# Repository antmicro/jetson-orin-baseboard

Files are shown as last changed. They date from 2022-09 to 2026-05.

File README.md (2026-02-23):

# Antmicro Baseboard for Jetson Orin

Copyright (c) 2022-2026 [Antmicro](https://www.antmicro.com)




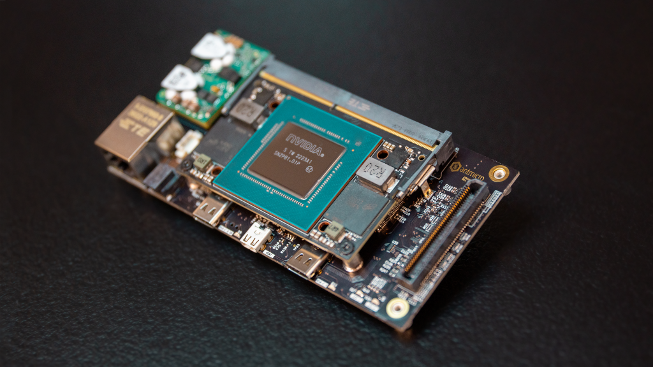
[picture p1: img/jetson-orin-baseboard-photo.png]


## Overview

This project contains open hardware design files for a baseboard supporting [NVIDIA Jetson Orin series](https://www.nvidia.com/en-us/autonomous-machines/embedded-systems/jetson-orin/) of System on Modules (SoMs) including Jetson Orin NX and Jetson Orin Nano.
The board break-routes the typical I/O interfaces from the SoM.
Additionally, it exposes an expansion connector which allows it to be integrated with external processing modules using USB, PCIe or low-speed interfaces.

The design files were prepared in KiCad 9.x.

## Key features

* Two USB PD ports
* DC Power connector
* MIPI CSI-2 interfaces on 50-pin connectors with configurable lane mapping
* Micro HDMI connector
* USB-C 10 Gbps with USB PD and DP
* USB-C 10 Gbps
* USB-C UART with USB PD
* M.2 key M
* M.2 key E
* 1Gb Ethernet with PoE
* Custom expansion connector
* RTC battery backup

## Project structure

The main directory contains KiCad PCB project files, a LICENSE, and a README.
The remaining files are stored in the following directories:

* `img` - contains graphics for this README
* `doc` - contains [documentation and usage instructions](https://antmicro.github.io/jetson-orin-baseboard)

The board exposes MIPI CSI-2 interfaces using unified 50-pin connectors that are electrically compatible with a variety of video accessories created by Antmicro:

* [GMSL Deserializer](https://github.com/antmicro/gmsl-deserializer)
* [SDI-MIPI Video converter](https://github.com/antmicro/sdi-mipi-video-converter)
* [HDMI-MIPI bridge](https://github.com/antmicro/hdmi-mipi-bridge)
* [CVBS-MIPI bridge](https://github.com/antmicro/cvbs-mipi-bridge)
* [OV5640 Dual camera board](https://github.com/antmicro/ov5640-dual-camera-board)
* [OV9281 Dual camera board](https://github.com/antmicro/ov9281-camera-board)
* [Storage Expansion board](https://github.com/antmicro/job-storage-expansion)
* [FRAMOS camera adapter](https://github.com/antmicro/framos-csi-adapter)
* [Allied Vision Alvium Camera Adapter](https://github.com/antmicro/alvium-flexible-csi-adapter)

## Licensing

This project is published under the [Apache-2.0](LICENSE) license.

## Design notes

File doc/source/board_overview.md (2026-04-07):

# Board overview

Jetson Orin Baseboard is an open hardware board design supporting NVIDIA Jetson Orin NX and Orin Nano family of SoMs.
The board design files were created in KiCad 8.x.
The board is a versatile development kit which can be easily adopted in order to make it usable in commercial applications for autonomous vehicles, industry, agriculture, medicine or space.
You can find out more about the Jetson Orin Baseboard in this [blog article](https://antmicro.com/blog/2023/05/jetson-orin-baseboard-1-1-with-orin-nano/), or by visiting Antmicro's portals listed below:

* [Open Hardware Portal](https://openhardware.antmicro.com/boards/jetson-orin-baseboard/)
* [System Designer](https://designer.antmicro.com/library/devices/jetson-orin-baseboard)
* [Open Source Portal](https://opensource.antmicro.com/projects/jetson-orin-baseboard/)

They provide 3D renders and the board stackup definition, as well as an interactive preview of the board schematic.

You can also browse board-specific assets in the GitHub [releases](https://github.com/antmicro/jetson-orin-baseboard/releases) section.
The assets provided here include PDF schematics and mechanical (STEP) models of the board assemblies in certain revisions.

## IO map

A map of on-board connectors, status LEDs, control buttons and I/O interfaces is provided below.

:::{figure-md}
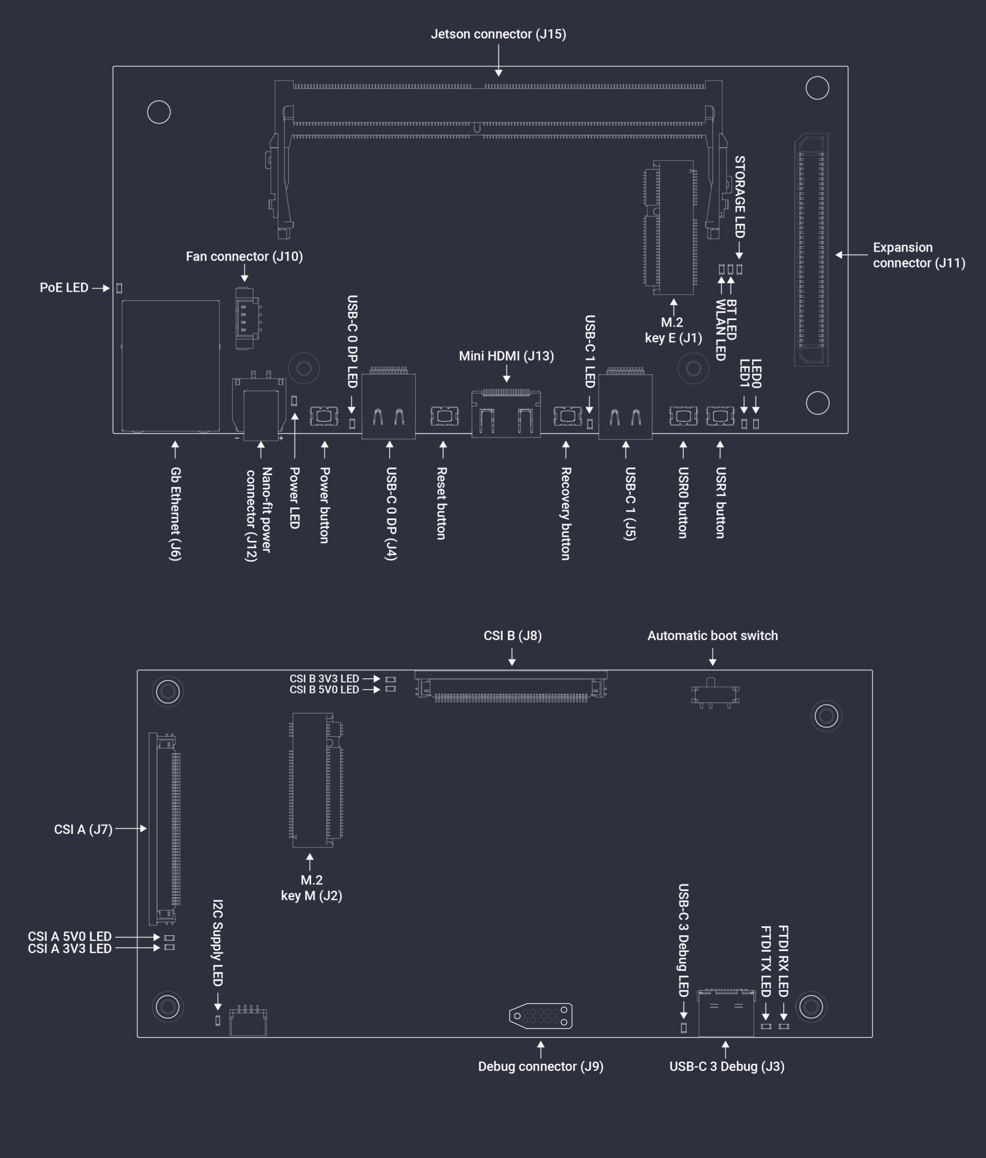
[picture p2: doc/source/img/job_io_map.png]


Jetson Orin Baseboard interface map
:::

## Power

The board can be powered with the following sources:

### 1. DC Connector

Jetson Orin Baseboard can be powered with a stable DC voltage via the on-board locking DC connector ([`J12`](#J12)) with Molex Nano-Fit plug (see the [Power Supply](getting_started.md#power-supply) section for details related to Nano-Fit power harness assembly).
You can use an external DC adapter for powering the board or a battery pack with rechargeable or non-rechargeable batteries, as long as the provided voltage fits within the accepted range (9-20VDC for board revision >= 1.3.0 and up to 15 V on rev. <= 1.1.7).
In board revision >= 1.3.0, the power supply voltage provided to the SoM is switched between `VCC_IN` power rail and 5V power rail provided by the on-board step down DC-DC converter depending on the `MODULE_ID` pin status.
This enables the use of the Jetson Orin NX in "super" mode which requires a minimum power supply voltage of 8V.
If you plan to power the Jetson Orin Baseboard from a battery pack, please note that battery (re-) charging is currently not supported in the design. 
Adjusting the power supply scenario for specific battery types and charging strategy can be implemented via a custom modification of the baseboard PCB design. 

### 2. Power over Ethernet

Jetson Orin Baseboard supports PoE++ Type 1-4 (IEEE 802.3bt) and negotiates Power Delivery (PD) with a maximum power budget of 60W.
The board includes an isolated PoE DC/DC converter.
You can power the board via the Gigabit Ethernet port ([`J6`](#J6)) using a PoE injector or a PoE-capable Ethernet switch.

### 3. USB-C Power Delivery
* USB Power Delivery PD is available on two USB-C ports:
    * USB-C0 ([`J4`](#J4)) general purpose USB port
    * USB-C3 ([`J3`](#J3)) debug console interface port (disabled in the [shared](https://github.com/antmicro/antmicro-jetson-orin-baseboard-tps65988-config) controller configuration)

Those ports are maintained by the on-board USB-C Power Delivery controller (Texas Instruments/[TPS65988](https://www.ti.com/product/TPS65988/part-details/TPS65988DHRSHR)).
This controller needs to be configured in order to make it implement one of the desired power source/sink negotiation scenarios.

:::{note}
The recommended power supply voltage negotiated with the USB-C PD controller for power sink mode is 20VDC (15VDC for board revisions <= 1.3.0).
If you plan to power up the Jetson Orin Baseboard through the USB PD source, make sure it meets [power requirements](getting_started.md#2-power-supply) for stable operation.
:::

## USB-C Power Delivery controller configuration

The on-board USB-C Power Delivery controller (Texas Instruments/[TPS65988](https://www.ti.com/product/TPS65988/part-details/TPS65988DHRSHR)) can be configured for a specific power profile by writing a binary configuration file to an SPI flash.
You can generate your own configuration file with the [TPS6598X-CONFIG](https://www.ti.com/tool/TPS6598X-CONFIG) utility provided by Texas Instruments.
Please refer to the Jetson Orin Baseboard [schematics](https://github.com/antmicro/jetson-orin-baseboard/blob/main/doc/jetson-orin-baseboard-schematic.pdf) to identify the USB port and power supply rail associated with it to generate a valid power profile setting while using the `TPS6598X-CONFIG` tool.
Also please refer to the [TPS65987DDH and TPS65988DH Host Interface Technical Reference Manual](https://www.ti.com/lit/ug/slvubh2b/slvubh2b.pdf) for further details.

There are several ways to write the USB-C PD configuration to the on-board controller:
* Via an external SPI Flash programmer connected to the [`J9`](#J9)
* Via the [antmicro-jetson-orin-baseboard-tps65988-config](https://github.com/antmicro/antmicro-jetson-orin-baseboard-tps65988-config) tool
  * From the Jetson Orin SoM BSP (user space)
  * From the host (PC) via the USB-C ([`J3`](#J3)) debug console interface port (in baseboard revisions >= 1.1.9)

If you happen to have some of the most recent baseboard revision (>= 1.1.9), the easiest method to use is [flashing from the debug console interface port](#tps65988-config-tool-via-the-debug-console-interface-port).

### External SPI Flash programmer
#### 1. Collect the hardware

You will need the following pieces of hardware to proceed with writing the USB-C PD configuration file to the SPI Flash:

* A computer running Linux (the following procedure has been tested with Ubuntu 23 and Debian 11 distributions)
* USB dongle based on FTDI/(FT4232H-56Q) [FTDI4232](https://ftdichip.com/products/ft4232hq/).
  We suggest using Antmicro's open hardware [Debug Toolkit](https://github.com/antmicro/ftdi-toolkit) to simplify the setup (the cable mentioned below connects its J2 straight with Jetson Orin Baseboard's J9)
* 10 Pin Tag-Connect [TC2050-IDC-NL](https://www.tag-connect.com/product/tc2050-idc-nl-10-pin-no-legs-cable-with-ribbon-connector) cable
  This cable should be connected to the signals from FTDI FT4232 according to the following table:

| Tag-Connect TC2050-IDC-NL-050 [(pinout)](https://www.tag-connect.com/wp-content/uploads/bsk-pdf-manager/TC2050-IDC-NL_Datasheet_8.pdf) | FTDI 4232 [(pinout)](https://ftdichip.com/wp-content/uploads/2024/05/DS_FT4232H.pdf) |
|---|---|
| 1 | 3V3 |
| 2 | ADBUS3 (TMS/CS) |
| 3 | GND |
| 4 | ADBUS0 (TCK/SCLK) |
| 5 | GND |
| 6 | ADBUS2(TDO/MISO) |
| 7 | NC |
| 8 | ADBUS1 (TDI/MOSI) |
| 9 | GND |
| 10 | NC |

#### 2. Prepare the FT4232 dongle

  *  Set the [Debug Toolkit](https://github.com/antmicro/ftdi-toolkit) Channel A to 3.3V logic with a jumper.
  *  Enable JTAG VCC with a jumper.
  *  Select `SPI/SWD` interface mode for channel A with a jumper.
  *  Connect the 10 Pin Tag-Connect cable to the Debug Toolkit assuming the connection mapping specified in the table above (for Antmicro Debug Toolkit - connect to J2 connector).

:::{figure-md}
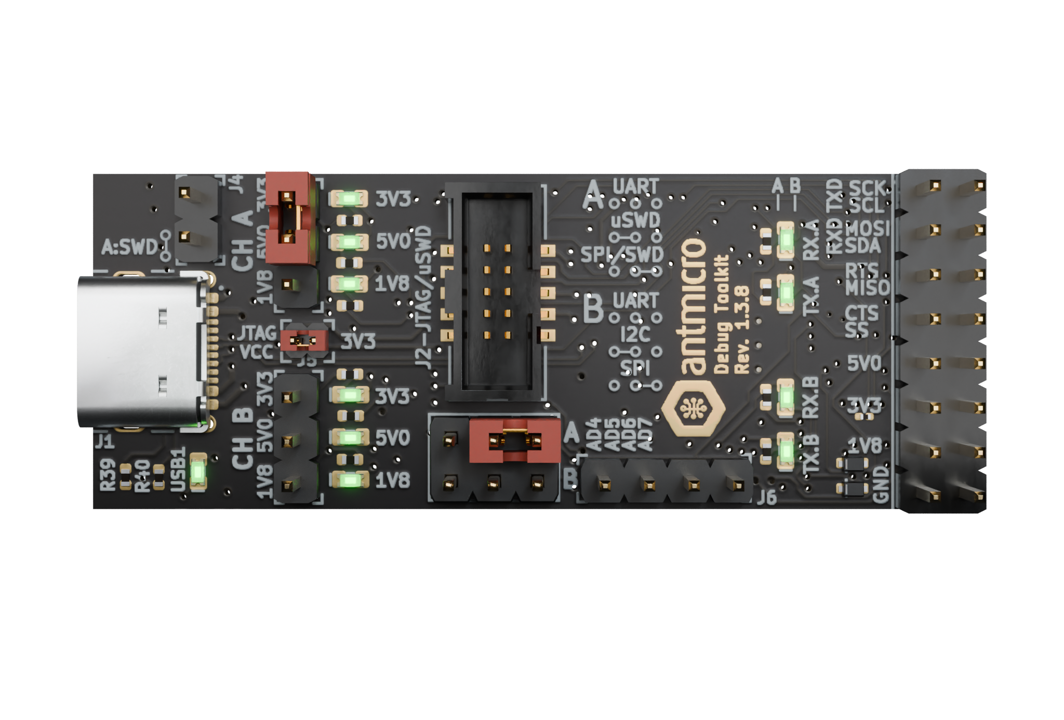
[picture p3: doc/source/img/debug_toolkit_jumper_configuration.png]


Debug Toolkit Jumper configuration for writing the USB-C PD configuration file.
:::

#### 3. Prepare the PC for flashing

  * Install the [flashrom](https://github.com/flashrom/flashrom) utility on your host PC.
    On Debian-based distributions you can use a package manager for that.
```
sudo apt install flashrom
```
  * Adjust the size of the TPS6598 binary configuration file (we named it `config.bin`) to match the SPI flash size:
```
truncate -s 1048576 config.bin
```

#### 4. Write the configuration

  * Connect [Tag-Connect Plug-of-Nails](https://www.tag-connect.com/product/tc2050-idc-nl-050) to the [`J9`](#J9) connector on the Jetson Orin Baseboard.
   Hold the plug in place firmly during the flashing process.
   The SPI flash will be powered via the programming cable during the flashing process - you do not have to provide your Jetson Orin Baseboard with power.

:::{figure-md}
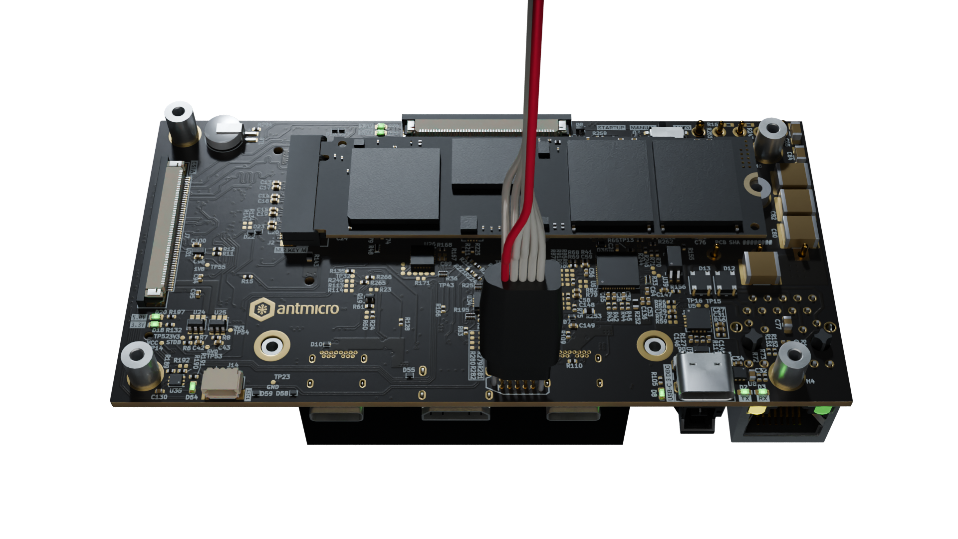
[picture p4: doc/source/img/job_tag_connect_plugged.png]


Jetson Orin Baseboard with Tag-Connect plugged for PD controller flashing.
:::

 * Check if SPI Flash can be detected via Debug Toolkit:
```
flashrom -p ft2232_spi:type=4232H,port=A,divisor=64 | grep "W25Q80.V"
```
Expected outcome:
```
Found Winbond flash chip "W25Q80.V" (1024 kB, SPI) on ft2232_spi.
```

 * Write the configuration file to the SPI Flash:
```
flashrom -p ft2232_spi:type=4232H,port=A,divisor=64 -w config.bin
```
Expected outcome:
```
(...)
Reading old flash chip contents... done.
Erasing and writing flash chip... Erase/write done.
Verifying flash... VERIFIED.
```

 * You can repeat the previous command to ensure that the binary file has been written successfully:

Expected outcome:
```
(...)
Warning: Chip content is identical to the requested image.
Erase/write done.
```

### TPS65988-config tool from Jetson Orin user space

The TPS65988-config flashing script can be found in the [antmicro-jetson-orin-baseboard-tps65988-config](https://github.com/antmicro/antmicro-jetson-orin-baseboard-tps65988-config) repository.

#### 1. Prepare hardware

To properly execute this script, boot the Jetson Orin Baseboard, and connect to it via the [debug console](getting_started.md#connect-the-debug-console) or via SSH. 
Since the PD controller is not yet configured at this point, the baseboard has to be powered from either the [`J12`](#J12) or via PoE connected to the [`J6`](#J6).
Internet connection is also suggested.

#### 2. Install dependencies
Log into Jetson Orin module.
Clone the [antmicro-jetson-orin-baseboard-tps65988](https://github.com/antmicro/antmicro-jetson-orin-baseboard-tps65988-config) repository and install the `smbus2` package using `pip`

```
git clone https://github.com/antmicro/antmicro-jetson-orin-baseboard-tps65988-config.git
pip3 install smbus2
cd antmicro-jetson-orin-baseboard-tps65988-config
```

#### 3. Flash the config
Run:

```
python3 TPS65988_flash.py --erase --write JOBrev1_1_6.bin
```

Expected outcome:
```
(...)
Writing 42KB to flash memory...
Write completed 43968 bytes written
The PD Controller has been flashed successfully
Performing cold reset
```

### TPS65988-config tool via the debug console interface port
This option allows for flashing the USB-C Power Delivery controller without SoM or external power.

#### 1. Prepare hardware
* Disconnect power supply from the baseboard
* Remove Jetson module from the baseboard
* Connect a host PC to Jetson Orin Baseboard USB-C Debug Connector ([`J3`](#J3))

#### 2. Install dependencies

On the host PC:

Clone the [antmicro-jetson-orin-baseboard-tps65988-config](https://github.com/antmicro/antmicro-jetson-orin-baseboard-tps65988-config) repository and install the `smbus2` package with `pip`

```
git clone https://github.com/antmicro/antmicro-jetson-orin-baseboard-tps65988-config.git
pip3 install smbus2
cd antmicro-jetson-orin-baseboard-tps65988-config
```

#### 3. Write the configuration
```
python3 TPS65988_flash.py --erase --write ./JOBrev1_1_6.bin --ft230x
```
During the flashing process the [`D3`](#D3) LED should light up.

Expected outcome:
```
(...)
Writing 42KB to flash memory...
Write completed 43968 bytes written
The PD Controller has been flashed successfully
Performing cold reset
Reverting FT230X to UART configuration
```
The [`D3`](#D3) RX LED should turn off indicating end of communication.

## Mechanics

The Jetson Orin Baseboard PCB is 120x60 millimeters (WxL) which translates into 4.72x2.36 inch.
The overall height of the set depends on the cooling module attached.
The base setup with a default cooling module is 37 mm or 1.45 inch tall.
The KiCad PCB design files include mechanical layers with dimensions specified for the fastening holes and notable components.
The board with the Jetson Module, M.2 storage and cooling module weighs 164g (5.78oz).
The mechanical STEP models of the Jetson Orin Baseboard in notable revisions are provided in the [releases](https://github.com/antmicro/jetson-orin-baseboard/releases/) sections available on GitHub.

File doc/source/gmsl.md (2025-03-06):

# GMSL
This manual will guide you through the setup of the open hardware GMSL Deserializer and Serializer boards together with Jetson Orin Baseboard.
It describes the basic steps required to run a simple demo that captures feed from the connected OV5640 sensor.

## Collect the hardware
You'll need the following hardware:
* [NVIDIA Jetson Orin Nano SoM](https://www.nvidia.com/en-us/autonomous-machines/embedded-systems/jetson-orin/)
* [Antmicro Jetson Orin Baseboard](https://github.com/antmicro/jetson-nano-baseboard)
* [Antmicro OV5640 dual camera board](https://github.com/antmicro/ov5640-dual-camera-board)
* [Antmicro GMSL Serializer](https://github.com/antmicro/gmsl-serializer) x 2
* [Antmicro GMSL Deserializer](https://github.com/antmicro/gmsl-deserializer)
* [Antmicro Dual Camera to GMSL Serializer CSI Adapter](https://github.com/antmicro/dual-gmsl-serializer-adapter) (optional, for two camera setup)
* NVMe drive
* Power supplies (for GMSL Deserializer it can be the same as for the Jetson Orin Baseboard)

## Build your setup

### Prerequisites
First follow the steps in [Getting Started](./getting_started.md) to have a running Jetson Orin Baseboard ready.

### Steps
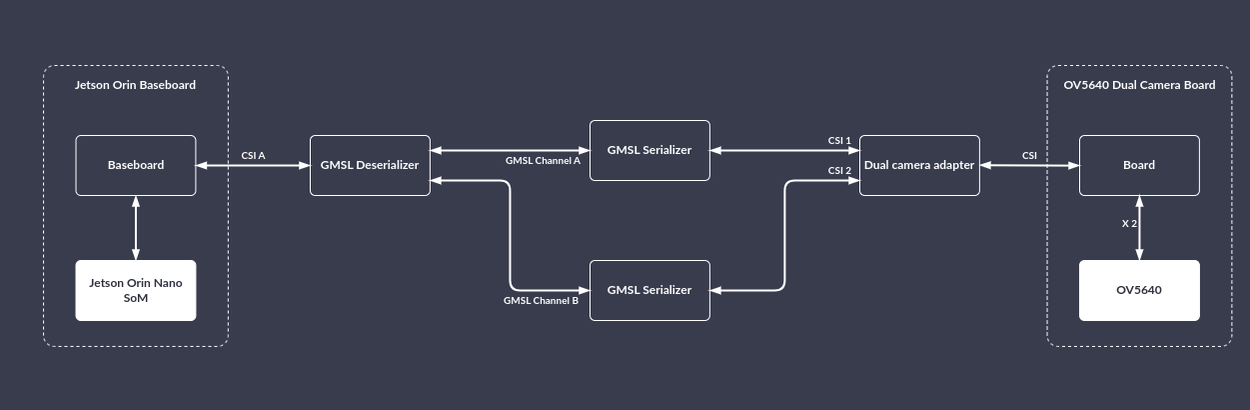
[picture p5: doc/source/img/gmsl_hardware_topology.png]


To prepare the Jetson Orin Baseboard for GMSL usage, connect the hardware like in the diagram above, that is:
1. Connect GMSL Deserializer to Jetson Orin Baseboard on CSI A
2. Connect GMSL Serializer #1 to GMSL Deserializer on Channel A
3. Connect GMSL Serializer #2 to GMSL Deserializer on Channel B
4. Connect GMSL Serializer #1 to the dual camera adapter
5. Connect GMSL Serializer #2 to the dual camera adapter
6. Connect OV5640 Dual Camera Board to the dual camera adapter
7. Plug in the power supply to the GMSL Deserializer
8. Power on the Jetson Orin Baseboard

This is how the setup should look after everything has been connected:
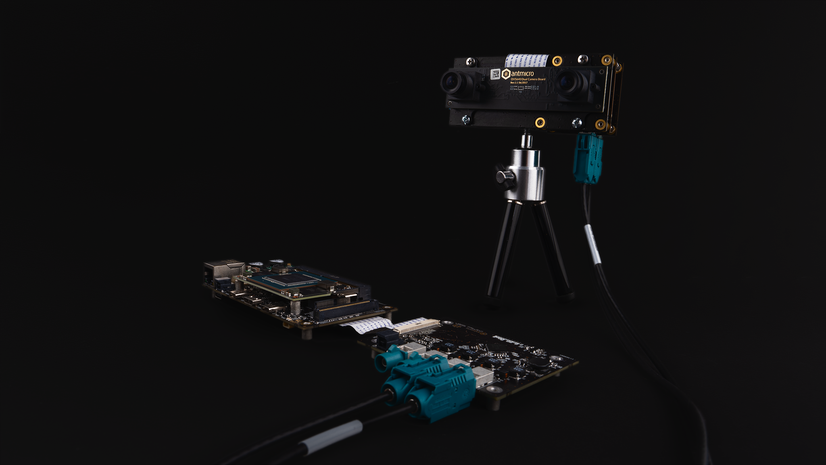
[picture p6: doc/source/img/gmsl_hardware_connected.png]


## Flash the BSP image
Flash the image using [this BSP](https://github.com/antmicro/meta-antmicro/tree/master/system-releases/nvidia-jetson-orin-baseboard-demo). First, pull the code:
```
mkdir gmsl-demo && cd gmsl-demo
$ repo init -u https://github.com/antmicro/meta-antmicro.git -m system-releases/nvidia-jetson-orin-baseboard-demo/manifest.xml
$ repo sync -j`nproc`
```
Build the BSP:
```
$ source sources/poky/oe-init-build-env
$ export BB_ENV_PASSTHROUGH_ADDITIONS="$BB_ENV_PASSTHROUGH_ADDITIONS KERNEL_DEVICETREE"
$ PARALLEL_MAKE="-j $(nproc)" BB_NUMBER_THREADS="$(nproc)" MACHINE="p3509-a02-p3767-0000" KERNEL_DEVICETREE="tegra234-p3767-0003-antmicro-job-gmsl-ov5640.dtb" bitbake nvidia-jetson-orin-baseboard-demo
```
After the BSP has been built, connect the NVMe storage to the device and put the device into recovery mode:
* Connect the Recovery USB-C port to the host PC
* Press the POWER button (if the device isn't powered yet)
* Press and hold the RECOV button
* Press the RESET button
* Release the RESET and RECOV buttons
* Check if the following USB device is present on your host PC:
```
$ lsusb
...
ID 0955:7323 NVIDIA Corp. APX
...
```
Unpack the `tegraflash` package:
```
cd tmp/deploy/images/p3509-a02-p3767-0000
mkdir flash-directory && cd flash-directory
tar xzvf ../nvidia-jetson-orin-baseboard-demo-p3509-a02-p3767-0000.tegraflash.tar.gz
```
Flash it:
```
sudo ./initrd-flash
```

Run the following command on the device to verify that the GMSL hardware was detected:
```
$ media-ctl -p
```
It's output should reflect the GMSL devices' topology:
```
...
- entity 1: nvcsi0 (2 pads, 2 links)
            type V4L2 subdev subtype Unknown flags 0
            device node name /dev/v4l-subdev0
	pad0: Sink
		<- "des_ch_0":0 [ENABLED]
	pad1: Source
		-> "vi-output, ov5640 21-003c":0 [ENABLED]

- entity 4: nvcsi1 (2 pads, 2 links)
            type V4L2 subdev subtype Unknown flags 0
            device node name /dev/v4l-subdev1
	pad0: Sink
		<- "des_ch_1":0 [ENABLED]
	pad1: Source
		-> "vi-output, ov5640 23-003c":0 [ENABLED]

- entity 7: ser_0_ch_0 (2 pads, 2 links)
            type V4L2 subdev subtype Unknown flags 0
            device node name /dev/v4l-subdev2
	pad0: Source
		[fmt:FIXED/0x0]
		-> "des_ch_0":1 [ENABLED]
	pad1: Sink
		[fmt:YUYV8_1X16/0x0]
		<- "ov5640 21-003c":0 [ENABLED]

- entity 10: ser_1_ch_0 (2 pads, 2 links)
             type V4L2 subdev subtype Unknown flags 0
             device node name /dev/v4l-subdev3
	pad0: Source
		[fmt:FIXED/0x0]
		-> "des_ch_1":1 [ENABLED]
	pad1: Sink
		[fmt:YUYV8_1X16/0x0]
		<- "ov5640 23-003c":0 [ENABLED]

- entity 13: des_ch_0 (2 pads, 2 links)
             type V4L2 subdev subtype Unknown flags 0
             device node name /dev/v4l-subdev4
	pad0: Source
		[fmt:YUYV8_1X16/0x0]
		-> "nvcsi0":0 [ENABLED]
	pad1: Sink
		[fmt:FIXED/0x0]
		<- "ser_0_ch_0":0 [ENABLED]

- entity 16: des_ch_1 (2 pads, 2 links)
             type V4L2 subdev subtype Unknown flags 0
             device node name /dev/v4l-subdev5
	pad0: Source
		[fmt:YUYV8_1X16/0x0]
		-> "nvcsi1":0 [ENABLED]
	pad1: Sink
		[fmt:FIXED/0x0]
		<- "ser_1_ch_0":0 [ENABLED]

- entity 19: ov5640 21-003c (1 pad, 1 link)
             type V4L2 subdev subtype Sensor flags 0
             device node name /dev/v4l-subdev6
	pad0: Source
		[fmt:UYVY8_1X16/1920x1080 field:none colorspace:srgb]
		-> "ser_0_ch_0":1 [ENABLED]

- entity 21: vi-output, ov5640 21-003c (1 pad, 1 link)
             type Node subtype V4L flags 0
             device node name /dev/video0
	pad0: Sink
		<- "nvcsi0":1 [ENABLED]

- entity 47: ov5640 23-003c (1 pad, 1 link)
             type V4L2 subdev subtype Sensor flags 0
             device node name /dev/v4l-subdev7
	pad0: Source
		[fmt:UYVY8_1X16/1920x1080 field:none colorspace:srgb]
		-> "ser_1_ch_0":1 [ENABLED]

- entity 49: vi-output, ov5640 23-003c (1 pad, 1 link)
             type Node subtype V4L flags 0
             device node name /dev/video1
	pad0: Sink
		<- "nvcsi1":1 [ENABLED]
```

## Capturing streams
### Setting up formats
Deserializer and serializer need to be informed what packet types to forward, otherwise all packets will be filtered:
```
# first stream
media-ctl -d /dev/media0 --set-v4l2 '"ser_0_ch_0":1[fmt:YUYV8_1X16/1920x1080]'
media-ctl -d /dev/media0 --set-v4l2 '"des_ch_0":0[fmt:YUYV8_1X16/1920x1080]'
# second stream
media-ctl -d /dev/media0 --set-v4l2 '"ser_1_ch_0":1[fmt:YUYV8_1X16/1920x1080]'
media-ctl -d /dev/media0 --set-v4l2 '"des_ch_1":0[fmt:YUYV8_1X16/1920x1080]'
```
### Capturing frames
To capture a given number of frames from the camera just run:
```
v4l2-ctl -d<camera_number> --stream-mmap --stream-count=<number_of_frames> --stream-to=cam0_image.raw
```
Or use GStreamer:
```
gst-launch-1.0 v4l2src device=<camera_device> num-buffers=<number_of_frames> ! filesink location=cam0_image.raw
```
For OV5640 number of frames should be > 3, since OV5640 needs a few frames to roll out before the stream stabilizes.

### Live video feed
This requires Jetson Orin Baseboard to be connected to some screen via HDMI.
To stream the feed from a camera to an X11 window:
```
gst-launch-1.0 v4l2src device=<camera_device> ! xvimagesink
```

To capture two feeds simultaneously:
```
gst-launch-1.0 \
v4l2src device=/dev/video1 ! \
compositor name=mix sink_0::xpos=0 sink_0::ypos=0 sink_1::xpos=1280 sink_1::ypos=0 ! \
videoconvert ! autovideosink \
v4l2src device=/dev/video0 ! \
mix.
```

### Example images captured with the setup
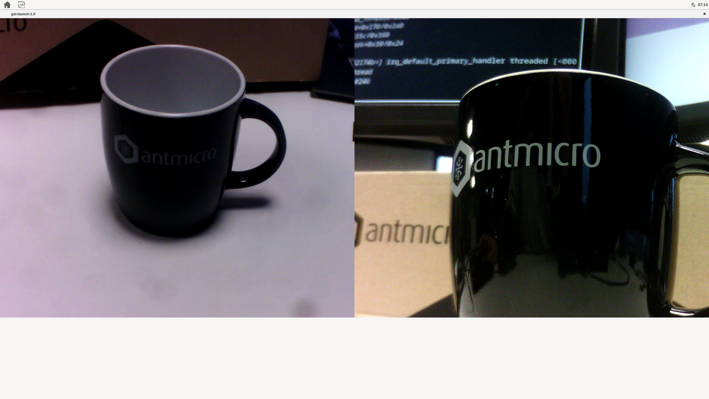
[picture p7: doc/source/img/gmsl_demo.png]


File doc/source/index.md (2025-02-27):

# {{project}}

```{toctree}
:maxdepth: 3

getting_started
board_overview
gmsl
```

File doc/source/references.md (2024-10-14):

# Image references
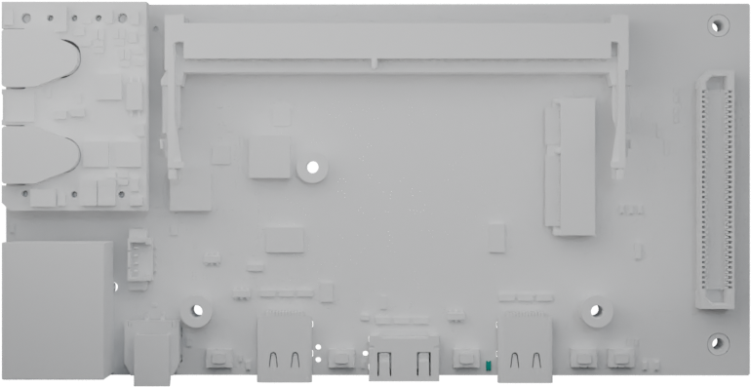
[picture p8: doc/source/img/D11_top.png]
```{image} img/D11_top.png
:name: D11
```

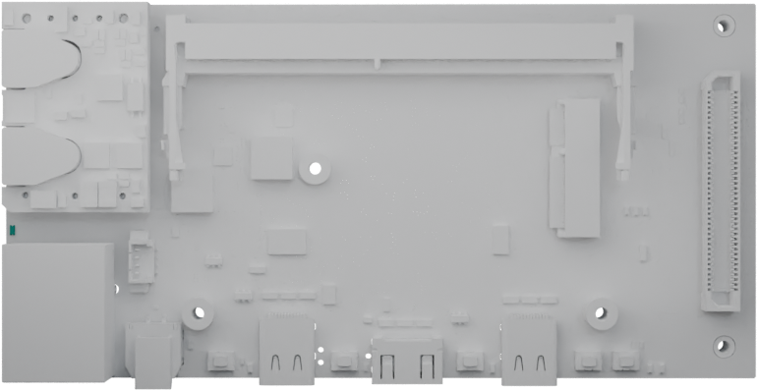
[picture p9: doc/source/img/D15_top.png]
```{image} img/D15_top.png
:name: D15
```

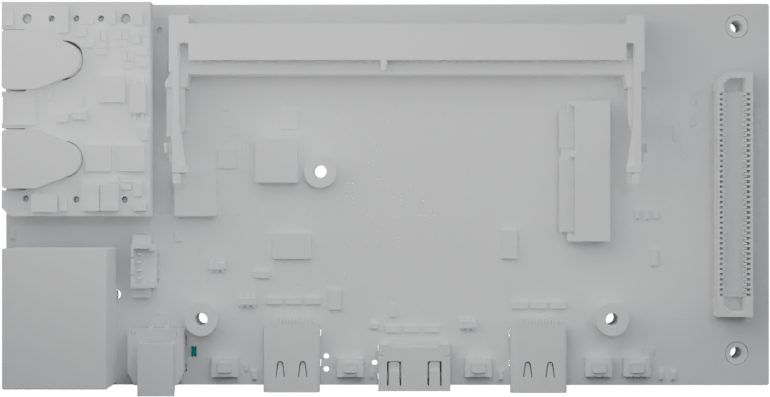
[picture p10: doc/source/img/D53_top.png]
```{image} img/D53_top.png
:name: D53
```

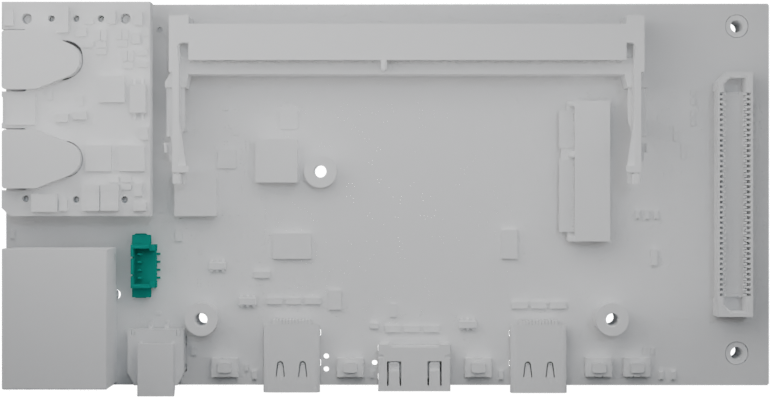
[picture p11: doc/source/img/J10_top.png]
```{image} img/J10_top.png
:name: J10
```

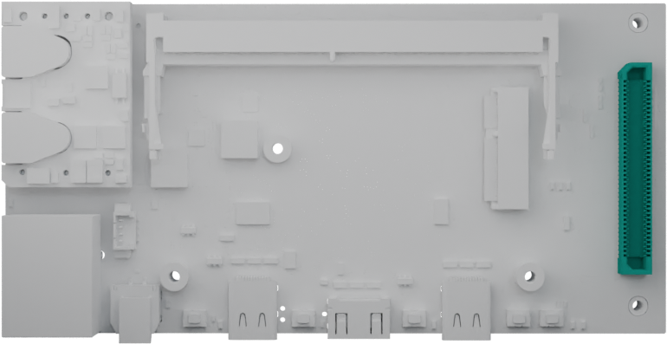
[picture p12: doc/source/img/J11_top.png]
```{image} img/J11_top.png
:name: J11
```

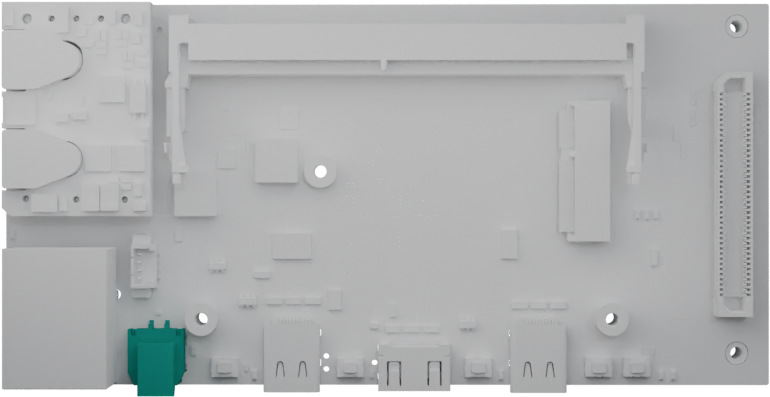
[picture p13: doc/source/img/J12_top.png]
```{image} img/J12_top.png
:name: J12
```

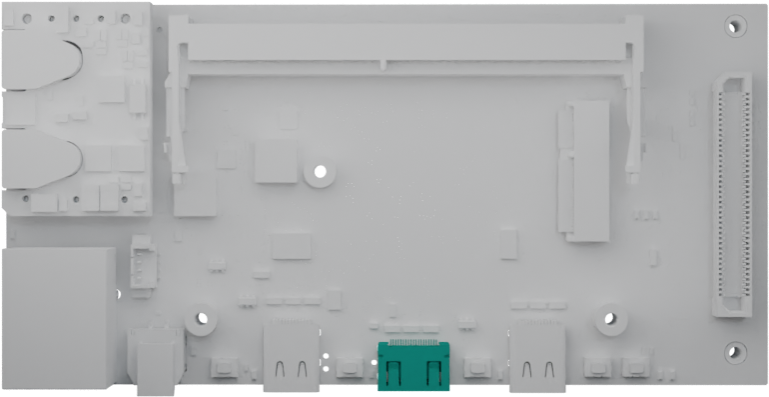
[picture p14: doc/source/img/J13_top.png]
```{image} img/J13_top.png
:name: J13
```

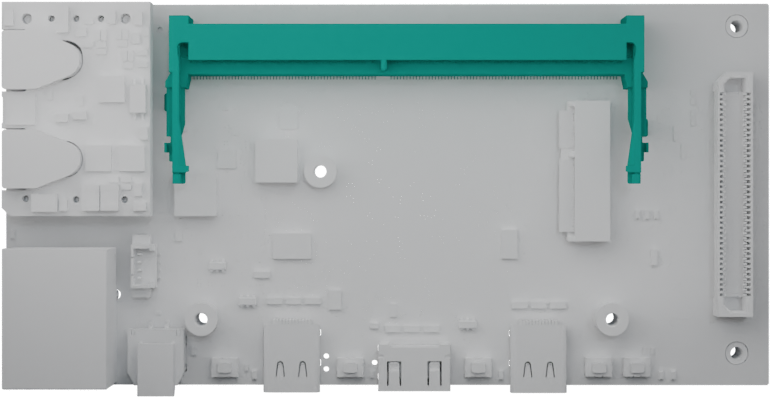
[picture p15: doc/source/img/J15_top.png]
```{image} img/J15_top.png
:name: J15
```

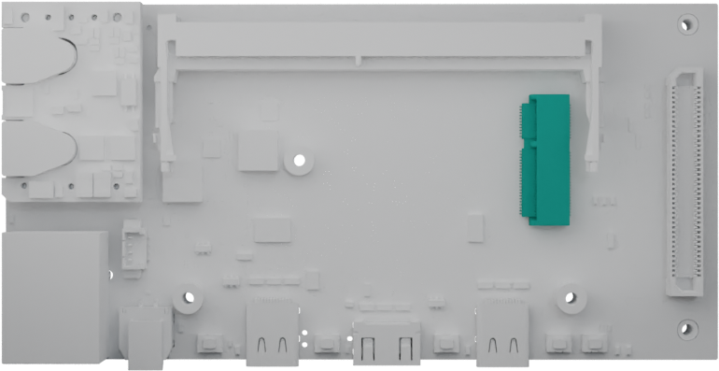
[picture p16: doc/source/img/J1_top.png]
```{image} img/J1_top.png
:name: J1
```

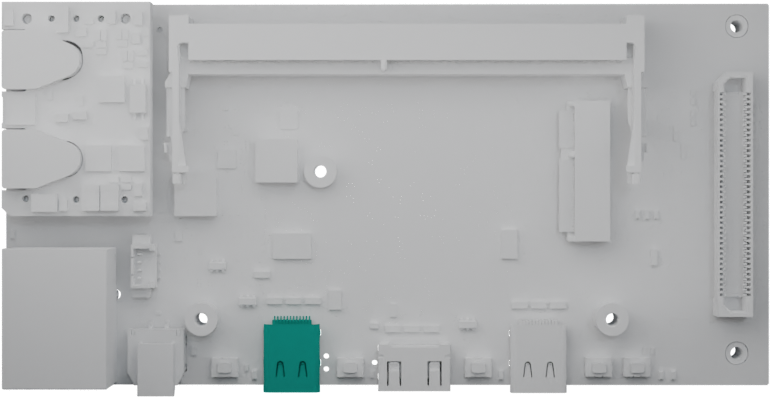
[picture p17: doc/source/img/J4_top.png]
```{image} img/J4_top.png
:name: J4
```

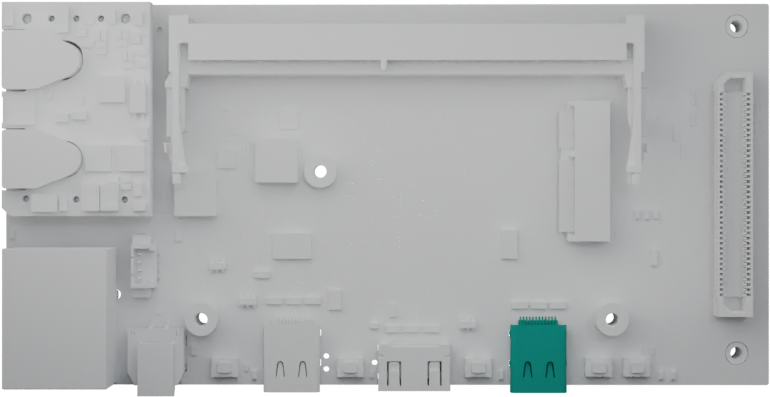
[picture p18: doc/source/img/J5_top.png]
```{image} img/J5_top.png
:name: J5
```

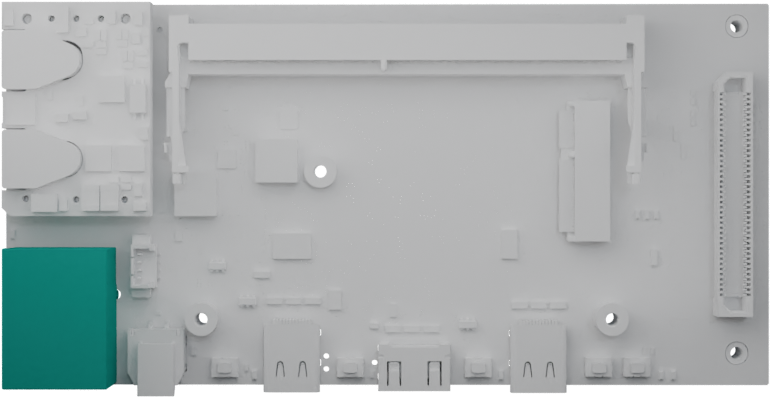
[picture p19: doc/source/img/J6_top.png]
```{image} img/J6_top.png
:name: J6
```

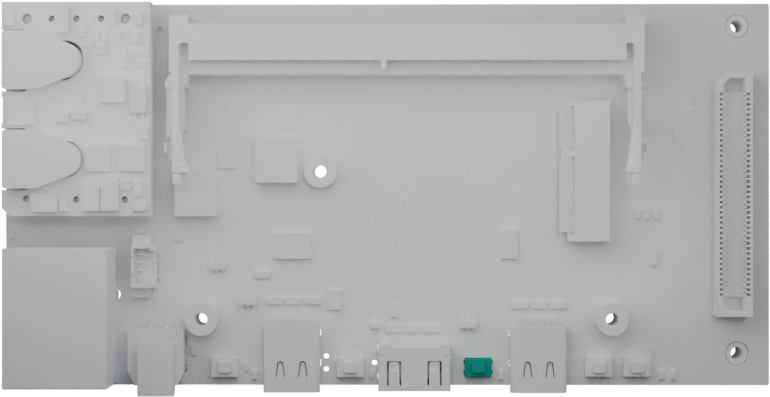
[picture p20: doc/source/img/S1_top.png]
```{image} img/S1_top.png
:name: S1
```

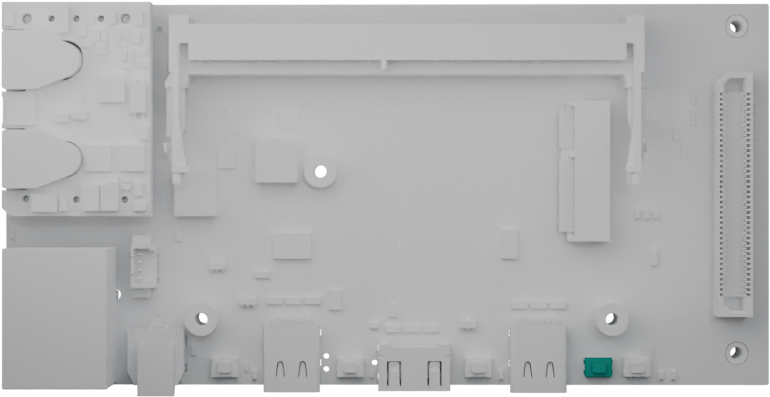
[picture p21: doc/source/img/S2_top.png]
```{image} img/S2_top.png
:name: S2
```

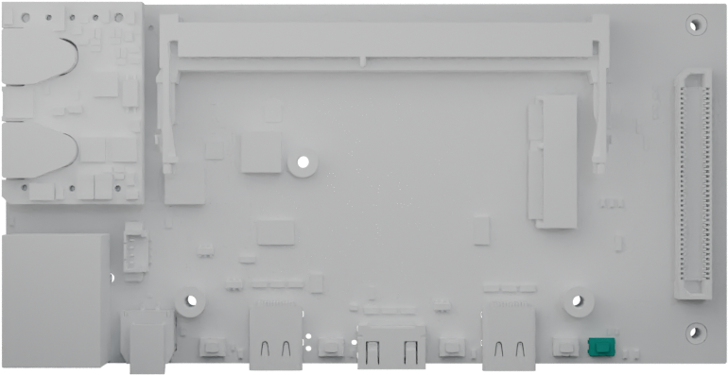
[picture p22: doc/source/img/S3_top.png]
```{image} img/S3_top.png
:name: S3
```

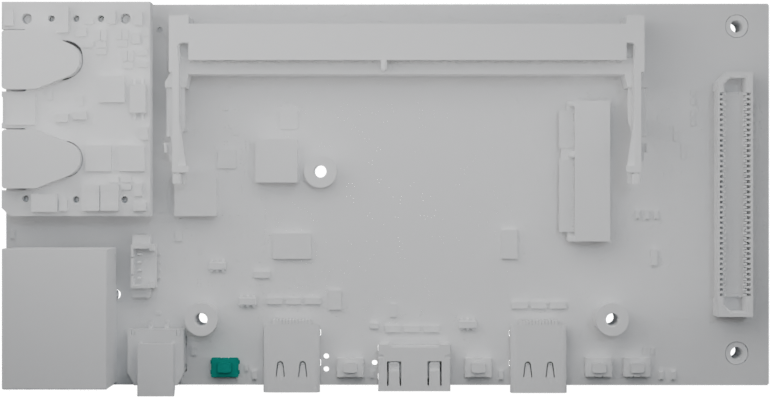
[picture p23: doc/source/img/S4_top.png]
```{image} img/S4_top.png
:name: S4
```

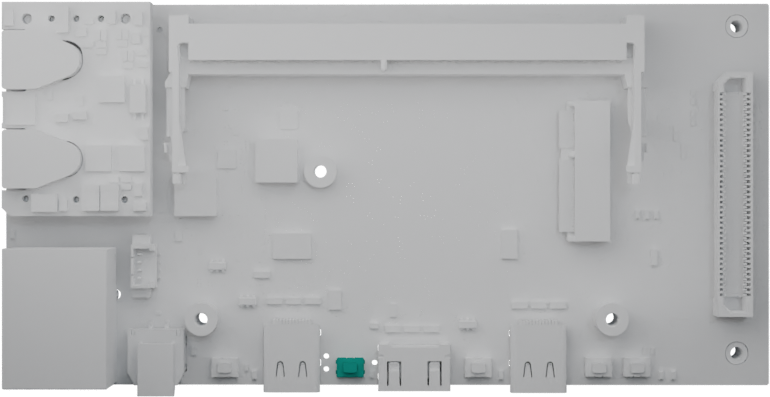
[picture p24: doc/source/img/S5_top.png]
```{image} img/S5_top.png
:name: S5
```

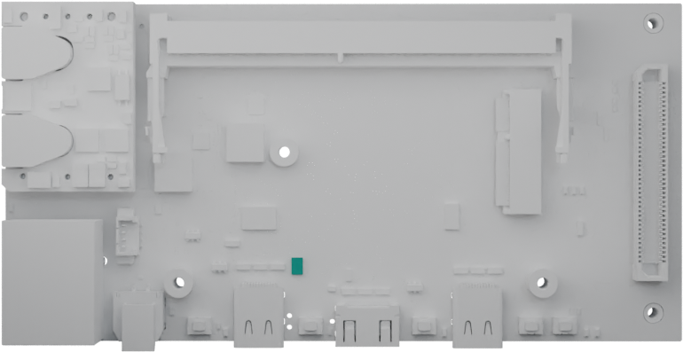
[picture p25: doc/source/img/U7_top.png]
```{image} img/U7_top.png
:name: U7
```

```{image} img/D3_bottom.png
:name: D3
```

```{image} img/J14_bottom.png
:name: J14
```

```{image} img/J2_bottom.png
:name: J2
```

```{image} img/J3_bottom.png
:name: J3
```

```{image} img/J7_bottom.png
:name: J7
```

```{image} img/J8_bottom.png
:name: J8
```
```{image} img/job_tag_connect_plugged_scaled.png
:name: J9
```

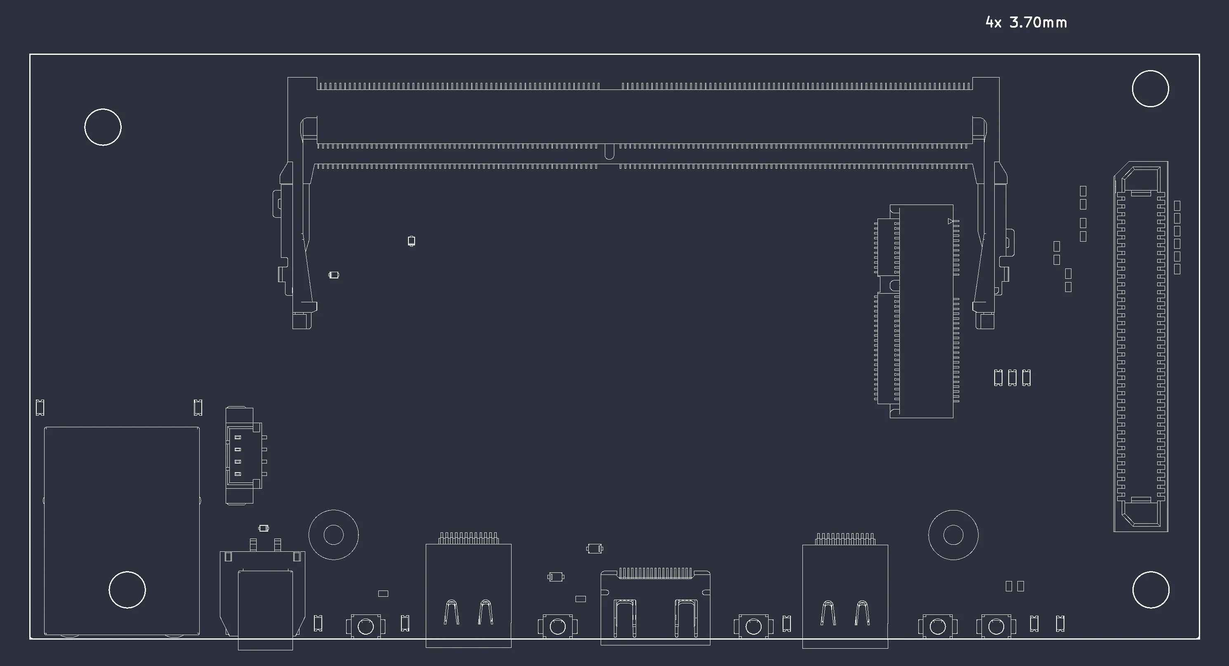
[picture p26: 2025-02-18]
assets/wireframe/wireframe_descriptions_top.webp

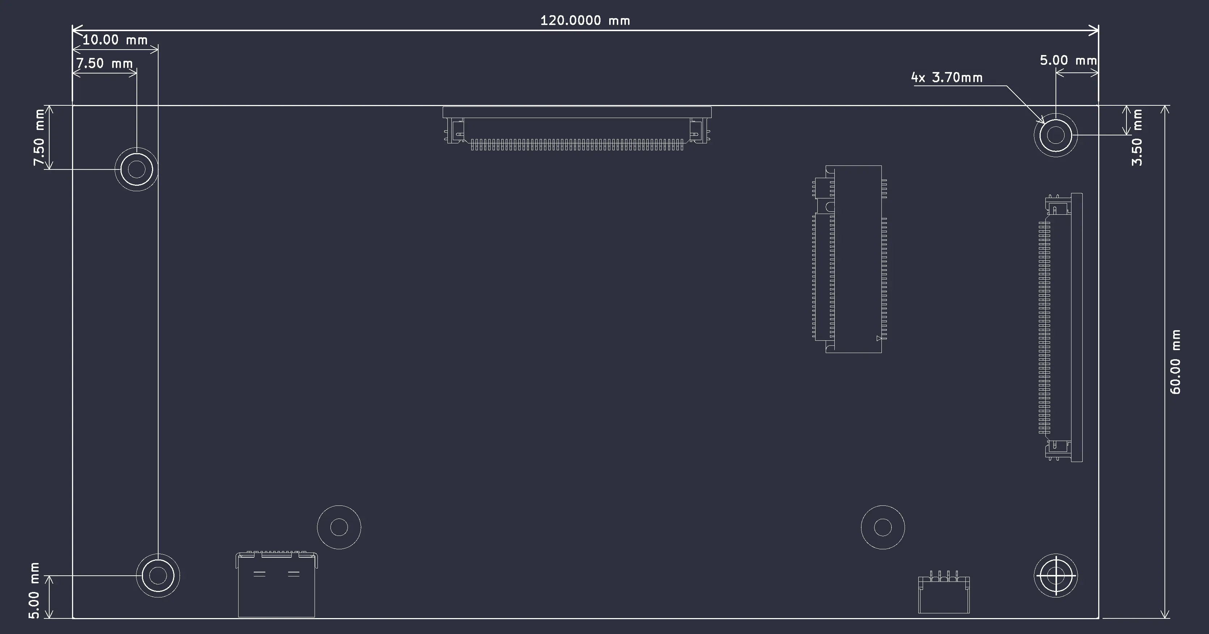
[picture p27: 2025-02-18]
assets/wireframe/wireframe_dimensions_bottom.webp

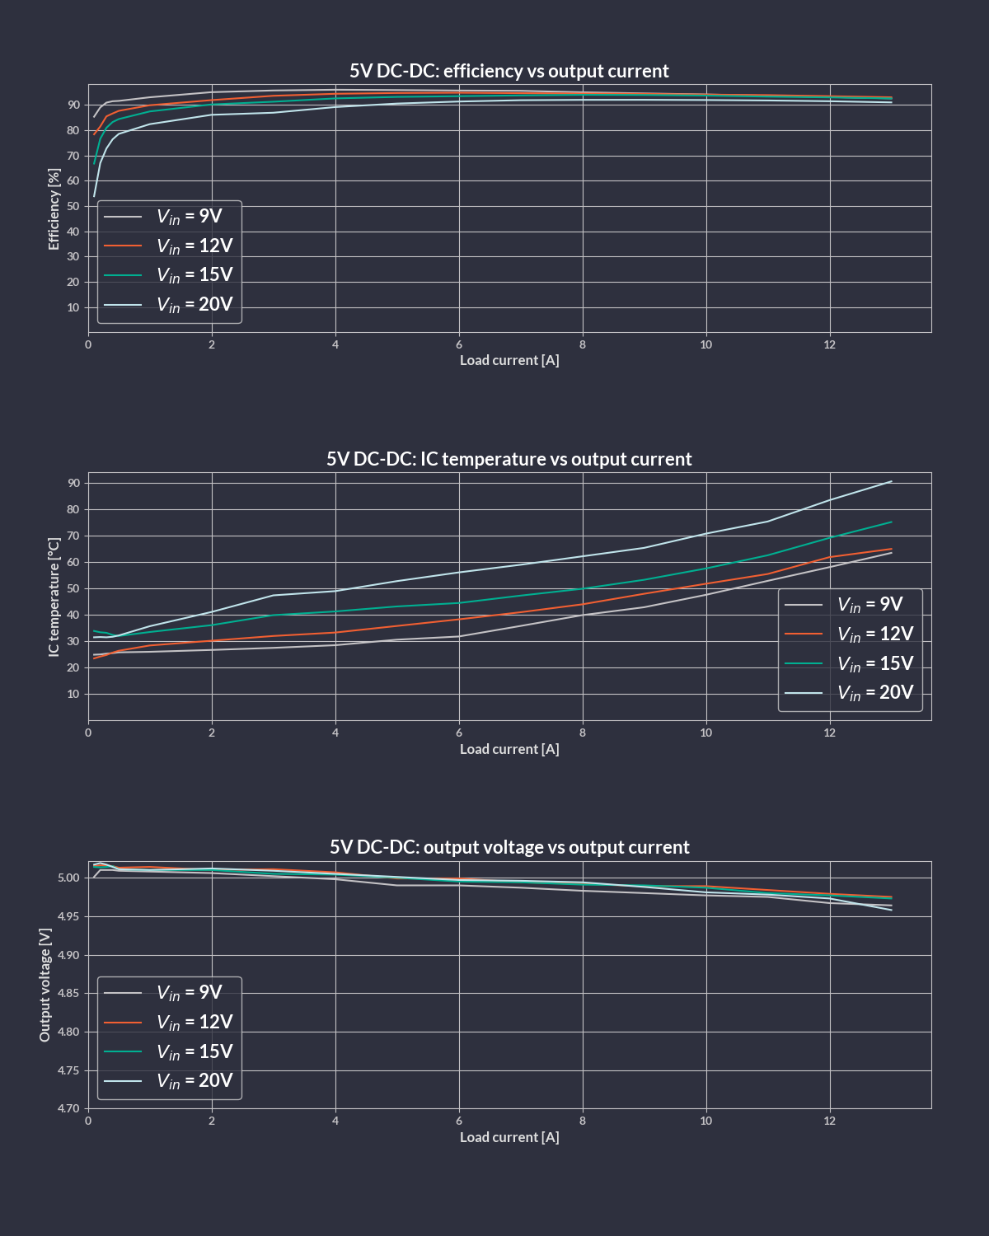
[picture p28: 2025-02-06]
doc/source/img/5V_eff_temp_vs_output_curr.png

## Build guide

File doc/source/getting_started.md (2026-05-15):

# Getting started guide

This manual will guide you through the initial setup of the open hardware [Jetson Orin Baseboard](https://github.com/antmicro/jetson-orin-baseboard).
It describes the basic steps required to assemble the board with required peripheral accessories, write a compiled Board Support Package (BSP) to the processing module and get it booted.
If you want to learn more about the Jetson Orin Baseboard itself, go to the [Board Overview](./board_overview.md) section.
That section also includes an [I/O map](./board_overview.md#io-map) that may come in handy when locating interface connectors mentioned in this guide.

## Collect the hardware

To get started with the Jetson Orin Baseboard, you'll need the following hardware:

### 1. Jetson SoM

The Jetson Orin Baseboard is electrically compatible with the NVIDIA Jetson Orin NX, Jetson Orin Nano [family of SoMs](https://developer.nvidia.com/embedded/jetson-modules) including Super modes of those SoMs.

### 2. Power supply

The Jetson Orin Baseboard supports three power supply scenarios:

* USB-C port ([`J4`](#J4)) with charger supporting Power Delivery (PD) negotiation.
  That is the easiest and most recommended solution for starters.
  The boards produced and distributed by [CircuitHub](https://antmicro-hardware.circuithub.com) come with pre-configured on-board USB-C Power Delivery controller which enables power sink mode on `USB-C 0` port.
  If you have built the board from scratch, you need to [configure the USB-C Power Delivery controller](board_overview.md#usb-c-power-delivery-controller-configuration) as described in the Board Overview section.
  You can use a typical smartphone or laptop USB-C charger utilizing Power Delivery protocol with support for 15V or 20V supply.

* RJ45 ([`J6`](#J6)) Ethernet connector using a PoE injector or a PoE-capable Ethernet switch compliant with the IEEE 802.3bt standard.

* DC locking connector ([`J12`](#J12)) which accepts a 2-wire Molex Nano-Fit plug.
  You can use an off-the-shelf Nano-Fit Cable assembly (Molex/[451300203](https://www.molex.com/en-us/products/part-detail/451300203)) or build a custom one from a Nano-Fit receptacle (Molex/[1053071202](https://www.molex.com/en-us/products/part-detail/1053071202)) and pre-crimped wires (Molex/[797582130](https://www.molex.com/en-us/products/part-detail/797582130)).
  The Jetson Orin Baseboard can be powered with a benchtop PSU or AC/DC wall adapter providing DC voltage.
  The recommended power supply voltage range for Jetson Orin Baseboard in revision <= 1.1.7 is 9-15 VDC.
  The recommended power supply voltage range for Jetson Orin Baseboard in revision >= 1.3.0 is 9-20 VDC.
  If you are using a DC locking connector - please observe the polarity marked in the render below.

Power consumption of the device varies depending on the used SoM version, utilized peripherals and specific application. 
We recommend using minimum a 30W rated power supply for the Jetson Orin Nano series and minimum 45W for the Jetson Orin NX series.

:::{figure-md}
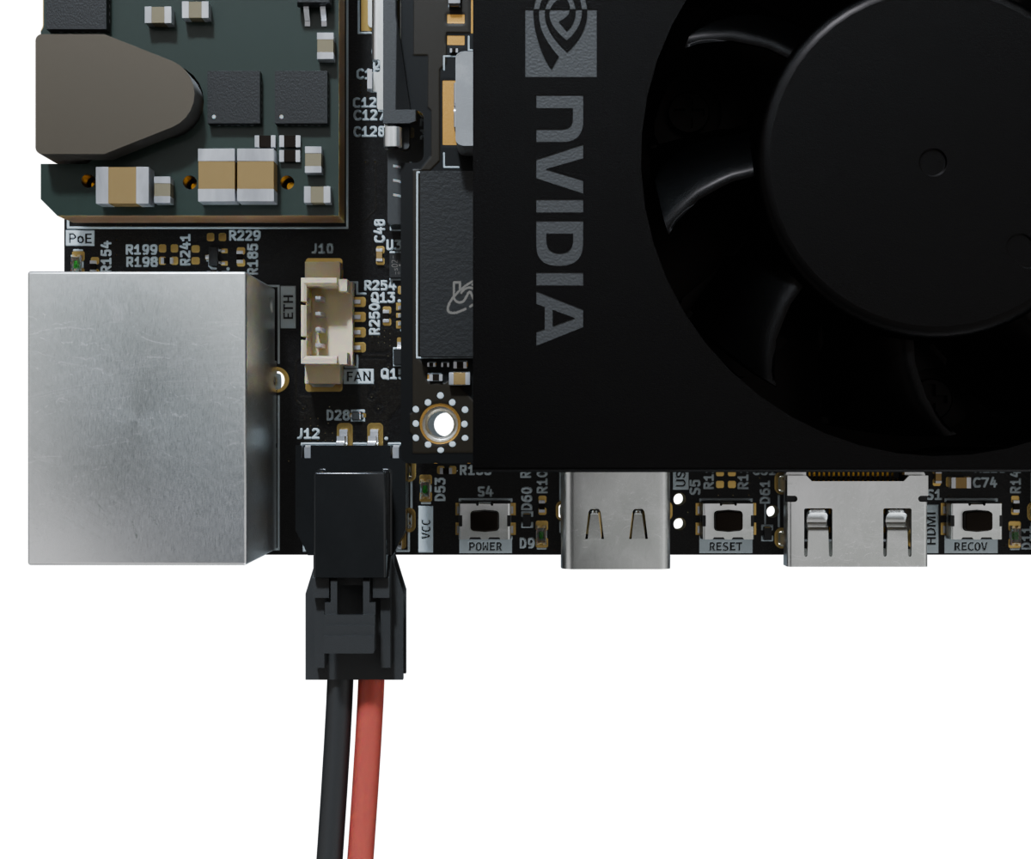
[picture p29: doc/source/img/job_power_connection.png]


Jetson Orin Baseboard DC power connection with polarity marking (red: vcc, black: gnd).
:::

### 3. Storage

You should equip the Jetson Orin Baseboard with M.2 NVMe SSD storage with at least 64GB of capacity.
That will be the primary storage device from which the SoM will boot.

### 4. Cooling module

You can use the Jetson Orin compatible cooling fan (Waveshare/[24076](https://www.waveshare.com/orin-fan-pwm.htm)) as a primary cooling solution when working with the Jetson Orin Baseboard.
Using a SoM without any cooling solution attached will make it throttle and eventually reboot or crash the system due to overheating.

### 5. Fastening bolts

You will need at least one metric M2.5 (5mm long) bolt and a matching screwdriver to fasten the SSD to the baseboard.
You may want to use more bolts to fasten the SoM and the baseboard to the baseplate.
All mechanical fastening points located on the board support bolts with metric M2.5 thread (ISO 7045).

### 6. Host PC

You will need a computer running Linux for flashing the reference BSP image to the Jetson Orin SoM installed in the baseboard.
The BSP flashing instructions provided below were verified with Debian and Arch based systems.
You may need to introduce minor adjustments for other Linux distros.

### 7. Cabling

#### SoM Flashing and debug console

You will need two USB-C cables for connecting the SoM flashing port and the debug port located on the Jetson Orin Baseboard to your PC.
You should avoid using USB hubs for the flashing interface to get the optimal flashing speed/performance.

#### Video output

Video output is optional.\
Use good quality HDMI 2.1, miniHDMI to HDMI cables with metal body plugs.\
Following cables were verified in an anechoic chamber EMI test and are recommended: Ugreen/15514 or Ugreen/15515.

## Build your setup

To prepare the Jetson Orin Baseboard for initial usage, follow the steps described below:

### 1. Install the cooling module

Begin with installing the cooling fan on the Jetson Orin SoM.
Make sure the openings carved in the bottom side of the heatsink match the power inductors located on the Jetson Orin SoM.
Please refer to the Jetson Cooling Fan [product page](https://www.waveshare.com/orin-fan-pwm.htm) for details.

### 2. Install the SoM

Securely attach the NVIDIA Jetson Orin SoM to the [`J15`](#J15) connector of the Jetson Orin Baseboard.
Remember to connect the cooling fan plug into the [`J10`](#J10) fan receptacle.
Optionally, you can fasten the SoM to the baseboard with two metric M2.5 (5mm long) bolts.

:::{caution}
The baseboard does not support hot-swapping of the SoM. 
Please disconnect all power sources from the baseboard and wait minimum 10s before removing/inserting the SoM.
:::

### 3. Install the storage

Install the NVMe M.2 SSD storage in the [`J2`](#J2) M.2 (key-M) slot located on the bottom side (i.e opposite side to the SoM) of the Jetson Orin Baseboard.
You need to fasten the SSD with one metric M2.5 (5mm long) bolt to ensure reliable connection.

### 4. Apply power supply

Pick one of the power supply scenarios described in the [Power Supply](#power-supply) section.
We recommend using an off-the-shelf USB-C charger connected to the `USB-C 0` port ([`J4`](#J4)) as the easiest option.
Apply power to the board.
Providing valid power supply should cause the VCC ([`D53`](#D53)) power indicator LED to light up.

### 5. Connect the debug console

Connect the debug USB-C ([`J3`](#J3)) port (located on the bottom side, under the power connector) to your PC.
This should get a virtual USB/serial port registered in your system under ``/dev/ttyUSBx``.
You can check the ``lsusb`` or ``dmesg`` commands to verify if the serial bridge was enumerated properly.

### 6. Connect the flashing interface

Connect the flashing USB-C ([`J5`](#J5) which is the right-most port on the top side of the Jetson Orin Baseboard) to your PC.
This should cause the [`D11`](#D11) LED indicator located next to the USB port to light up.
Now you are ready to prepare the BSP flashing image and initialize the flashing process.
At this point you should have 3 USB-C cables connected to the board and providing power supply, debug console in a terminal session, flashing interface.

:::{figure-md}
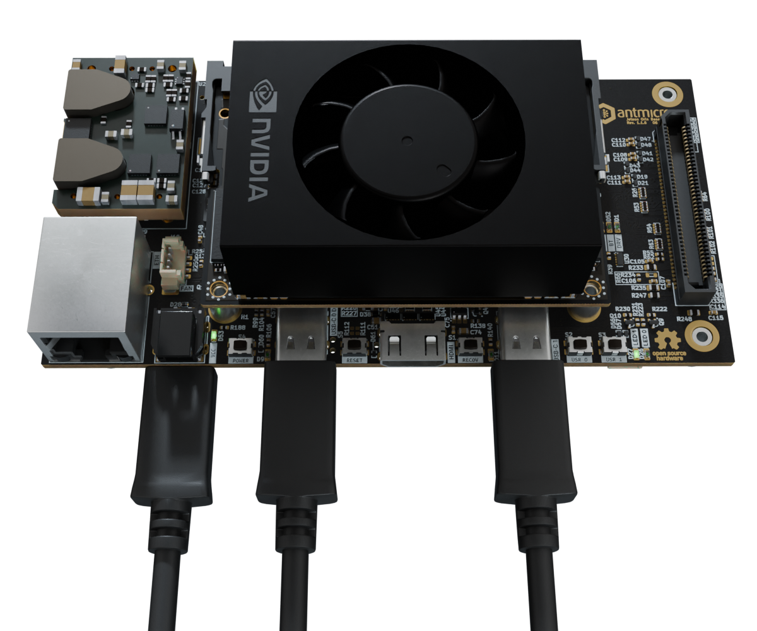
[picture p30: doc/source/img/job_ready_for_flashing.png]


Jetson Orin Baseboard ready for flashing.
:::

## Flash the BSP image

Jetson Orin Baseboard comes with a reference BSP image of a Yocto-based system built on top of the [meta-antmicro](https://github.com/antmicro/meta-antmicro) layer.
This BSP will let you verify the basic functionality of the board.
The following steps will guide you through the process of downloading and flashing a precompiled Board Support Package (BSP) for the Jetson Orin Baseboard.

### 1. Get the BSP image

First, create a workspace directory that will contain all of the files you will need for flashing:

```bash
export WORK="$HOME/antmicro-job-bsp"
mkdir -p $WORK
cd $WORK
```
Download the BSP image into the previously created workspace directory.
Make sure there is no other BSP image already downloaded there.
Please use the tabs provided below to pick the reference BSP image suitable for the Jetson Orin SoM variant you plan to use with the baseboard.
The latest available reference BSP image is based on JetPack 6.1.

````{tab} Orin NX 16 GB
```bash
wget https://dl.antmicro.com/projects/nvidia-jetson-orin-baseboard-demo-p3768-0000-p3767-0000.rootfs-20250709101446.tegraflash.tar.gz
```
````

````{tab} Orin NX 8 GB
```bash
wget https://dl.antmicro.com/projects/nvidia-jetson-orin-baseboard-demo-p3768-0000-p3767-0001.rootfs-20250709101437.tegraflash.tar.gz
```
````

````{tab} Orin Nano 8 GB
```bash
wget https://dl.antmicro.com/projects/nvidia-jetson-orin-baseboard-demo-p3768-0000-p3767-0003.rootfs-20250709101435.tegraflash.tar.gz
```
````

````{tab} Orin Nano 4 GB
```bash
wget https://dl.antmicro.com/projects/nvidia-jetson-orin-baseboard-demo-p3768-0000-p3767-0004.rootfs-20250709102320.tegraflash.tar.gz
```
````

````{tab} Orin Nano 8 GB (included in the NVIDIA Developer Kit)
```bash
wget https://dl.antmicro.com/projects/nvidia-jetson-orin-baseboard-demo-jetson-orin-nano-devkit-nvme.rootfs-20260428121811.tegraflash.tar.gz
```
````

Next, unpack the BSP image:

```bash
mkdir -p $WORK/bsp
cd $WORK/bsp
tar xvzf $WORK/*.tegraflash.tar.gz
```

### 2. Install dependencies

You need to have a `device-tree-compiler` installed on your machine for the flash tool to work.
On a Debian-like system, you can install it via apt:

```bash
sudo apt-get install device-tree-compiler
```

On an Arch-like system, you can install it via pacman:

```bash
sudo pacman -S dtc
```

### 3. Disable auto-mounting

When running a Debian-like operating system, you might encounter some difficulties with flashing the board, due to problems with disk auto-mounting.
A simple workaround for this issue is to disable auto-mounting for the time being:

```bash
gsettings set org.gnome.desktop.media-handling automount false
gsettings set org.gnome.desktop.media-handling automount-open false
```

### 4. Enter recovery mode

Make sure that the Jetson Orin Baseboard is [connected to a power source](#apply-power-supply) and that you have connected the [debug console USB](#connect-the-debug-console) and the [flashing USB interface](#connect-the-flashing-interface) to your PC, as described in the [Build your setup](#build-your-setup) section.
As already mentioned in the [Cabling](#cabling) section, you should be entering the recovery mode with direct connection of the flashing USB interface to the PC (i.e. there should be no USB hubs in between).
In order to enter the recovery mode, execute the following procedure using buttons located on the top side of the Jetson Orin Baseboard, oriented as shown in the photo above.

* Press and release the `POWER` button located on the top side, next to the DC power jack.
  The cooling fan on top of the Jetson SoM should start spinning slowly.
* Press and hold the `RECOV` (FORCE_RECOVERY) button located on the top side between the HDMI port and the right-most USB-C connector.
* Press and release the `RESET` button located on the top side between the HDMI port and the left-most USB-C connector.
* Release the `RECOV` button.
  The SoM cooling fan will now start spinning faster.

On the host PC, you should now see the following new USB device being detected (e.g. via lsusb):
```bash
lsusb | grep -i nvidia
# Bus 001 Device 026: ID 0955:7523 NVIDIA Corp. APX
```

The Jetson SoM will stay in the recovery mode for ~45s and then it will make an attempt to boot up.
If needed, repeat the procedure to force the SoM back into recovery mode.

### 5. Open debug console

Whenever developing with the Jetson Orin Baseboard, it always makes sense to have a terminal hooked to the Debug UART on your host PC.
You can use any serial port terminal emulator for that, but we’ll use ``picocom`` in this guide.
Make sure that the [debug console USB](#connect-the-debug-console) is connected to your host PC and the USB-serial converter is enumerated:
```bash
lsusb -d 0403:
# Bus 001 Device 118: ID 0403:6015 Future Technology Devices International, Ltd Bridge(I2C/SPI/UART/FIFO)
sudo dmesg | grep FTDI
# [1740634.745814] usb 1-4: FTDI USB Serial Device converter now attached to ttyUSB0
```

Run the terminal:
```bash
sudo picocom -b 115200 /dev/ttyUSB0
```

You should keep the ``picocom`` terminal open in a separate window/tab throughout board flashing.
That will give you an insight into the progress and debug log messages displayed during the process.

### 6. Flash the board

Open another terminal instance on your PC and navigate to the directory which holds the downloaded and unpacked BSP, as described in the [Get the BSP image](#get-the-bsp-image) section.

```bash
cd $HOME/antmicro-job-bsp/bsp
```

Make sure your SoM remains in the recovery mode.
Then, execute the flashing script from the same directory:

```bash
sudo ./initrd-flash
```
Be patient, as flashing might take a while (up to 30min).
When the flashing succeeds, you should see a log similar to the one below:

```bash
Starting at 2024-07-05T11:43:56+00:00
Machine:       p3509-a02-p3767-0000
Rootfs device: nvme0n1p1
Found Jetson device in recovery mode at USB 1-8
== Step 1: Signing binaries at 2024-07-05T11:43:56+00:00 ==
== Step 2: Boot Jetson via RCM at 2024-07-05T11:44:09+00:00 ==
Found Jetson device in recovery mode at USB 1-8
== Step 3: Sending flash sequence commands at 2024-07-05T11:44:12+00:00 ==
Waiting for USB storage device flashpkg from e3340a08...........[/dev/sdc]
Device size in blocks: 262144
== Step 4: Writing partitions on external storage device at 2024-07-05T11:44:57+00:00 ==
Waiting for USB storage device nvme0n1 from e3340a08...[/dev/sdc]
Creating partitions
  [02] name=kernel start=0 size=131072 sectors
  [03] name=kernel-dtb start=0 size=896 sectors
  [04] name=reserved_for_chain_A_user start=0 size=65536 sectors
  [05] name=kernel_b start=0 size=131072 sectors
  [06] name=kernel-dtb_b start=0 size=896 sectors
  [07] name=reserved_for_chain_B_user start=0 size=65536 sectors
  [08] name=recovery start=0 size=163840 sectors
  [09] name=recovery-dtb start=0 size=1024 sectors
  [10] name=RECROOTFS start=0 size=614400 sectors
  [11] name=esp start=0 size=131072 sectors
  [12] name=recovery_alt start=0 size=163840 sectors
  [13] name=recovery-dtb_alt start=0 size=1024 sectors
  [14] name=esp_alt start=0 size=131072 sectors
  [01] name=APP (fills to end)
Writing partitions
  Writing boot.img (size=37214208) to /dev/sdc2 (size=67108864)...
  Writing kernel_tegra234-p3767-0000-antmicro-job.dtb (size=333342) to /dev/sdc3 (size=458752)...
  Writing boot.img (size=37214208) to /dev/sdc5 (size=67108864)...
  Writing kernel_tegra234-p3767-0000-antmicro-job.dtb (size=333342) to /dev/sdc6 (size=458752)...
  Writing esp.img (size=67108864) to /dev/sdc11 (size=67108864)...
  Writing nvidia-jetson-orin-baseboard-demo.ext4 (size=59055800320) to /dev/sdc1 (size=255237365248)...
[OK: /dev/sdc]
== Step 5: Waiting for final status from device at 2024-07-05T12:13:37+00:00 ==
Waiting for USB storage device flashpkg from e3340a08...[/dev/sdc]
Final status: SUCCESS
Successfully finished at 2024-07-05T12:13:41+00:00
Host-side log:              log.initrd-flash.2024-07-05-11.43.56
Device-side logs stored in: device-logs-2024-07-05-11.43.56
```

Common Issue:
When a device is connected through a USB hub, the initrd-flash script may not recognize it, and it can get stuck displaying "Waiting for Jetson to appear on USB.......".
To verify whether the baseboard is directly connected to a root hub, use the `lsusb -vt` command.
Note that some USB ports on your PC motherboard USB may also be internally connected through a hub.

### 7. Login

After successful flashing, the SoM should reboot and you should see the booting log in the [debug console](#open-debug-console).
The SoM should boot up to the login screen visible in the debug console.
The reference BSP comes with a preconfigured root account.
To log in to the console, connect to the board via UART, turn on the power, and wait for the board to boot.
When it successfully boots, you will be asked for login and password:

```
p3509-a02-p3767-0000 login:
```
:::{note}
Please note that the login prompt may differ depending on the SoM and the BSP version you used for flashing.
:::

Use the following login credentials to get access to the system:

```
login: root
password: root
```

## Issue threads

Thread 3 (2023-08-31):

Import to Altium error

ltidswell, 2023-08-31:
I'm trying to import the files into Altium Designer using the import wizard but the .PcbDoc keeps showing up as empty. The schematics import fine. I get the following logs after the import is complete. Do you have Altium files available / has anyone else had this issue with these files?
[csi.SchLib.LOG](https://github.com/antmicro/jetson-orin-baseboard/files/12480976/csi.SchLib.LOG)
[ethernet.SchLib.LOG](https://github.com/antmicro/jetson-orin-baseboard/files/12480977/ethernet.SchLib.LOG)
[hdmi.SchLib.LOG](https://github.com/antmicro/jetson-orin-baseboard/files/12480978/hdmi.SchLib.LOG)

pgielda, 2023-08-31:
No, the project files are meant to be used in Kicad (https://en.wikipedia.org/wiki/KiCad). Obviously it is technically possible to import those designs to other tools but this is beyond the scope of this repository / issue tracker -- its meant for reporting bugs / problems with the design only.

Closed 2023-08-31.

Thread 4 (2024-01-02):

Most sheets are off-grid...

ajawamnet, 2024-01-02:
see attached

pkatarzynski, 2024-09-11:
Hi ajawamnet

Your screenshot you posted suggests that you are using a grid of 0.254 (10mil).

The schematics are defined for a grid of 1.27mm (50mil) which is a default grid size specified for KiCad 7 and KiCad8 (see the https://docs.kicad.org/8.0/en/eeschema/eeschema.html#snapping).
You can also use a 0.635mm (25mil) grid for a more fine-grained snapping.

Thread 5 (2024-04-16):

Will USB-C Displayport + Power Delivery work out of the box?

chicoband, 2024-04-16:
What device tree do I need to use? What changes do I need to make in the device tree to achieve this? Or will it work without any modifications in the device tree? Sorry I'm new to this but please help!

UtsavBalar1231, 2024-06-24:
+1

mizrex, 2024-09-20:
+1

pkatarzynski, 2024-09-23:
USB Power Delivery Controller (TPS65988DHRSHR) needs to be programmed with configuration file in order to enable USB-C power delivery in certain role.
You can configure it externally with TAG connect probe  as described [here](https://antmicro.github.io/jetson-orin-baseboard/board_overview.html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) or you can use the [TPS65988-config](https://github.com/antmicro/antmicro-jetson-orin-baseboard-tps65988-config) tool that allows to configure the controller from user space.

USB-C ALT mode requires muxing video output from HDMI to DisplayPort in the BSP.

sb3d-tech-mteitel, 2024-09-23:
Do you have instructions for “muxing video output from HDMI to DisplayPort in the BSP”?
Device Tree?
Pinmux?

Sent from Mail for Windows

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

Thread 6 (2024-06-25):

Repository does not contain lib folder

Furukawa-k, 2024-06-25:
I cannot find the kicad library folder in the repository.

pkatarzynski, 2024-07-01:
Hi Furukawa-k
I saw there was a mention about `lib` folder in README which was a leftover from previous revisions  - thanks for spotting this.

After we have migrated the PCB design into KiCad 7.x there is no need to keep  local copies of the component libraries as they can be re-created from the project.
You can generate local component libraries with those three major steps

* In KiCad Schematic Editor select `File -> Export -> Symbols to New Library`
  *  Include power symbols, select `Project` for Library Table
  * Confirm you want to reassign the schematic component references to the newly created schematic library
* In KiCad PCB Editor select `File -> Export -> Symbols to New Library`
  * Select `Project` for the Library Table
  * Confirm you want to make the fooprints from the design refer to the newly created footprint library
 * In KiCad PCB Editor select `Tools -> Update Schematic from PCB`
   * In the `Update` section check only `Footprint assignments`

Furukawa-k, 2024-07-17:
Thank you for indicating the reference.
How can I reference the 3D model?

Closed 2024-07-01.

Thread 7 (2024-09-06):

A lot of those Footprints are really wrong...

ajawamnet, 2024-09-06:
For instance, the SOD-523 - see the datasheet vs what you have.
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
Many of the footprints are incorrect.

pkatarzynski, 2024-09-11:
Hi ajawamnet

From the snippet you shared I assume you are referring to the recommended mounting footprint of SOD-523 provided by ON Semiconductors (https://www.onsemi.com/pdf/datasheet/rb521s30t1-d.pdf).

We share the SOD-523 footprint  for more diodes in our component library. This footprint definition originates from NXP  (https://www.nxp.com/docs/en/package-information/SOD523.pdf).

Also the recommended SOD-523 pad geometry differs between diode vendors.

I think the biggest recommended SOD-523 package comes from Diodes (https://www.diodes.com/assets/Package-Files/SOD523.pdf) which assumes 0.6x0.7mm pad size.

Closed 2024-09-11.

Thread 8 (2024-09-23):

SW1 part number is incorrect

ltidswell, 2024-09-23:
The value & footprint for part SW1 is for PN: PCM12SMTR but the MPN listed for this part (and what shows in the BOM) is PN: PCM13SMTR. This part will not fit in the footprint used on the board. If the BOM is used to order this part, it will NOT fit on the board.
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

mizrex, 2024-09-23:
It did work in our case. This is the DigiKey part# we used [401-2016-2-ND](https://www.digikey.com/en/products/detail/c-k/PCM12SMTR/1640112)

mizrex, 2024-09-23:
@ltidswell , yes you are right. I misunderstood your comment earlier.

pkatarzynski, 2024-11-06:
Hi ltidswell.

We have unified the SW1 MPN into PCM12SMTR. Thanks for spotting that.

Closed 2024-11-06.

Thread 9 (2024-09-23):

Bluetooth won't come up on a M.2 Wifi/BT card

mizrex, 2024-09-23:
Firstly, great work on this project! Very nicely done and documented.
We tried connecting a Wifi6 and also a Wifi5 Intel M.2. cards to J1 Key-E on the board. While the Wifi came up fine after installing their drivers. We are not able to get the Bluetooth working.
I did see that the SDIO pins are not connected (only major difference compare to the Jetson Orin Nano dev kit). But I'm not sure if Bluetooth uses the SDIO.
If you happen to have any idea on this?

mizrex, 2024-09-24:
Could it be something related to this USB connection:
If R20 and R52 needs to be populated?
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

mizrex, 2024-09-25:
We tried connecting R20 and R52, from my previous post. The Bluetooth LED (D52), started glowing, and M.2 card started showing up under _lsusb_ . However, it won't activate or turn on(even after drivers were installed). _hcitool dev_ cannot find any local bluetooth hardware connected. Any idea on this?

mizrex, 2024-10-01:
@pkatarzynski , thank you for getting back. This is [the Wifi+BT card](https://www.intel.com/content/www/us/en/products/sku/130293/intel-wifi-6-ax201-gig/specifications.html) we are using.
@pgielda , please see the lsusb and lspci outputs below. I think the wifi came up fine on the PCIE, while the bluetooth came up on the USB (after we connected R20 and R52). However, the bluetooth doesn't come up (even after installing it's drivers). Wifi works fine.
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

pkatarzynski, 2024-10-04:
Please verify if the Bluetooth interface is not soft-blocked.

You can use  `rfkill list` for that.
You can unblock the device with `rfkill unblock all`

After that the Bluetooth device should become visible after calling  `hcitool dev`

We have checked this approach with Waveshare AW-CB375NF WiFi/BT M.2 card Jetson Orin Baseboard in [Rev.1.1.6](https://github.com/antmicro/jetson-orin-baseboard/releases/tag/rev.1.1.6-ch) and the reference BSP image mentioned in the [Getting Started](https://antmicro.github.io/jetson-orin-baseboard/getting_started.html#get-the-bsp-image) section of the documentation.

zonga501, 2024-10-14:
Hello, Working with mizrex and the device seems to not be blocked but is also not showing
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

Closed 2024-10-11.

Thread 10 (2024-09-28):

1.1.6 doesn't have 3D models

ajawamnet, 2024-09-28:
Unlike 1.0.0 and 1.1.2, 1.1.6 has no 3D models and the PCB has the environment for each footprint set to ${ANT3DMDL}  instead of ${KIPRJMOD}

pkatarzynski, 2024-10-11:
A 3D model of the Jetson Orin Baseboard in rev.1.1.6 is included in the GH release https://github.com/antmicro/jetson-orin-baseboard/releases/tag/rev.1.1.6-ch

ajawamnet, 2024-10-11:
No - not the same thing I mean there's no 3D models in the ALTIUM  file.  And the the environment for each footprint set to ${ANT3DMDL} instead of ${KIPRJMOD}

Closed 2024-10-11.

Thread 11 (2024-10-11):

No HDMI display after boot (GPU miscinfigured for X11?)

sb3d-tech-mteitel, 2024-10-11:
Hardware:
Jetson orin baseboard purchased from CircuitHub. (https://antmicro-hardware.circuithub.com/)
Reworked for 2 4 lane mipi cameras. (remove R107 and install R103)
Jetson orin NX 8GB.

Powered from J4 or J12

bsp loaded per the instructions here.

https://github.com/antmicro/jetson-orin-baseboard/blob/main/doc/source/getting_started.md
enclosed are:
 the device tree as decompiled from /proc/device-tree using dtc.
the log from the host while running initrd-flash
the log from the target console during boot
output from dmesg after booting the target.

[initrd-flash.log](https://github.com/user-attachments/files/17337391/initrd-flash.log)
[bootlog.log](https://github.com/user-attachments/files/17337394/bootlog.log)
[debugConsole.log](https://github.com/user-attachments/files/17337396/debugConsole.log)
[device-tree.dts.log](https://github.com/user-attachments/files/17337475/device-tree.dts.log)

Note: EUFI displays the NVIDIA Logo and message **  WARNING: Test Key is used.  **
on the HDMI display at the point in the debug console output that has a large number of blank lines.

This is the last thing that is displayed on the HDMI monitor.

there are concerning messages about NVRM and Xserver in the debug console logs.

I am able to log into the target from the debug console or ssh.

sarnold, 2024-10-29:
We're thinking this is related to the right (or wrong) machine definition: Building for [this machine](https://github.com/OE4T/meta-tegra/blob/kirkstone/conf/machine/p3768-0000-p3767-0001.conf) should get the demo image working.

sarnold, 2024-10-29:
Also it turns out the Orin Baseboard build manifest seems to be on the wrong meta-tegra branch since the 8 GB Orin NX machine is *missing*.

gtirth, 2025-02-19:
I am also having the same problem. Are there any instructions or solutions to get this working.

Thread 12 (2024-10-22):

Orin Nano Support

mstanisz0, 2024-10-22:
Hi all,

I was trying to follow the [Getting Started Guide](https://antmicro.github.io/jetson-orin-baseboard/getting_started.html) and I ran into an issue flashing the BSP image.  When I go to flash, I get a hang at `Waiting for USB storage device flashpkg` on my Linux host.

On the debug console, the Orin Nano gets stuck in a busy wait loop.

From [searching around](https://github.com/OE4T/meta-tegra/discussions/1304), it sounds like it might be a device tree issue for my board type.  I see the antmicro BSP was developed for the Orin NX 16GB (P3767-0000) but I have the Orin Nano 8GB (P3767-0003).

Could you point me to instructions on how to update the demo BSP for the Orin Nano 8GB?

mstanisz0, 2024-10-29:
I'm assuming my issue is related to either having an Orin Nano or installed JetPack6 previously.  Is there a link you suggest for building up a new BSP for the baseboard?  I was looking at the [Module Adaptation Guide](https://docs.nvidia.com/jetson/archives/r36.4/DeveloperGuide/HR/JetsonModuleAdaptationAndBringUp/JetsonOrinNxNanoSeries.html), not sure if that's the right place to start.

mstanisz0, 2024-10-29:
Moving this discussion over to the [meta-antmicro](https://github.com/antmicro/meta-antmicro) repo, looks like it might be more relevant there.

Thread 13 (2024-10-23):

Bluetooth, continues to not work, through the M.2 Wifi/Bluetooth modules

mizrex, 2024-10-23:
Hello, Working with mizrex and the device seems to not be blocked but is also not showing
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

_Originally posted by @zonga501 in https://github.com/antmicro/jetson-orin-baseboard/issues/9#issuecomment-2411304959_

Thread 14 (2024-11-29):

USB-C Chip Removal and Compatibility with Base Image

aiweier1231, 2024-11-29:
Hi Antmicro Team,

First, thank you for providing this excellent open-source Jetson Orin baseboard design! I’m a graduate student at the University of Waterloo, and I am working on my own baseboard design based on your project. For simplicity (and to avoid potential issues with USB-C protocol chips), I’ve decided to remove the USB-C DP chip. However, the actual USBx connections to the Jetson module remain unchanged.

Here’s how I plan to use USB on my baseboard:

I need to retain the debug (FTDI) USB functionality for debugging purposes.
I need the ability to flash images to the Jetson module.
I will connect a USB 3.0 camera
I am planning to use the following base image as a starting point:
https://dl.antmicro.com/projects/nvidia-jetson-orin-baseboard-demo-p3509-a02-p3767-0000-20240723125144.tegraflash.tar.gz

Given these changes and requirements, I have a few questions:

1. Would the original image still work with the removal of the TI USB-C DP chip, given that the USBx connections to the Jetson remain the same?
2. Would I need to modify the device tree for USB-C PD hardware change?
3. Does the TI USB-C chip require flashing or a specific configuration in the base image for proper functionality?

Thank you in advance for your support and for making these resources available to the community!

Leo

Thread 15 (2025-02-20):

CSI port openings?

BEKKING, 2025-02-20:
I was planning to buy this product for my object detection project but i am unable to see any classical 15-22 pin CSI ports to directly connect my camera to.
Instead there is 50 pin irregular mezzanine connector is selected by designers. Is there a way for me to connect a camera module with standard CSI-MIPI cable to this baseboard?

Muammer06, 2025-02-23:
@pgielda, thank you for replying.
To respond briefly on behalf of my colleague, we were discussing the CSI port that is typically found in camera interfaces. We require instructions on how to transfer the 2-line and 4-line structure for this board. It appears unfeasible to transfer directly from the 50-line data transfer port to the CSI port, as per your design. Do you believe it would be more practical to create a separate board for this purpose? What steps should we take to address this issue?
CSI port=https://www.google.com/search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

Closed 2025-07-31.

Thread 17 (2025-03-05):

Jetpack 6.0 Flash

gtirth, 2025-03-05:
Hello,

I have been trying to flash the jetpack 6.0 on the orin baseboard with jetson orin nx 8GB SOC. However, it does not seem to boot up in the very last phase and it fails with timeout error.

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

I would really appreciate some insights here.

Thanks,
Tirth

amarburg, 2025-05-20:
You need to disable reading the CVB EEPROM per [here in the L4T Manual](https://docs.nvidia.com/jetson/archives/r36.4.3/DeveloperGuide/HR/JetsonModuleAdaptationAndBringUp/JetsonAgxOrinSeries.html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)

That said, I am also not able to get a bootable system with Jetpack.   Will create a separate issue.

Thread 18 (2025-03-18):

jetson-orin-baseboard-bsp board configuration files no longer accessible

acostach, 2025-03-18:
Hi @smr0z , previously two files for the Antmicro Job beaseboard for L4T 35.2.1 were available as an overlay on top of the Nvidia BSP:

- bsp_overlay/antmicro-job+p3767.conf
- bsp_overlay/bootloader/t186ref/BCT/tegra234-mb2-bct-misc-p3767-0000-antmicro-job.dts

I was using them at the "a3f498d4e1d3de081f0fdac2e16b4ecd64595d40" revision of the jetson-orin-baseboard-bsp repository, for provisioning our boards. Now `wget https://raw.githubusercontent.com/antmicro/jetson-orin-baseboard-bsp/a3f498d4e1d3de081f0fdac2e16b4ecd64595d40/bsp_overlay/antmicro-job%2Bp3767.conf ` returns a 404.

it seems that either the repository was deleted, made private or renamed. Could you please point me to where they have been moved, or make them available again?

Thank you

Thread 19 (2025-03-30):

USB C pin swap

mKunzendorf, 2025-03-30:
Hi, first of all thanks for sharing this project

When looking at U10 pin  4, 5 and 7, 8
It seems like the positive and negative pins are swapped, is this intentional?

USBSS0_RX_C_P -> USBSS0_RX_N
USBSS0_RX_C_N -> USBSS0_RX_P

USBSS0_TX_C_P -> USBSS0_TX_N
USBSS0_TX_C_N ->  USBSS0_TX_P

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

Best Regards
Mikael

zakrent, 2025-04-04:
Hi mKunzendorf

The polarity of USB SuperSpeed lanes has been swapped intentionally in order to simplify the PCB layout. USB automatically detects it and corrects for it, see sections 6.4.2 and 6.13.7 of [USB 3.2 Revision 1.1 specification](https://www.usb.org/document-library/usb-32-revision-11-june-2022) for details.

A side note here is that some USB Alt modes such as DisplayPort Alt mode do not support the automatic lane polarity inversion. That's why we swapped the lane polarity before the USB SS/DP mux but we didn't swap any polarities after it.

Closed 2025-04-09.

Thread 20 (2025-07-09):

Writing partition failed to nvme

TechSmithSH, 2025-07-09:
During flashing image to nvme, it failed, on step#3 it seems passed but on step#4 it failed. Below is the log for "sudo ./initrd-flash", could you please help to suggest whats going wrong?

Hardware Info
SOM: JetsonOrinNX 8GB
NVME: 128Gb (ThinkPlus ST9000 M.2 NVME 2280)
HOST PC: Ubuntu22, no USB hub in between, directly plugged to USB C on the host machine

Disk automount is disabled,
gsettings set org.gnome.desktop.media-handling automount false
gsettings set org.gnome.desktop.media-handling automount-open false

sudo ./initrd-flash
Starting at 2025-07-09T16:07:46+08:00
Machine:       p3768-0000-p3767-0001
Rootfs device: nvme0n1p1
Found Jetson device in recovery mode at USB 1-12
== Step 1: Signing binaries at 2025-07-09T16:07:46+08:00 ==
== Step 2: Boot Jetson via RCM at 2025-07-09T16:07:59+08:00 ==
Found Jetson device in recovery mode at USB 1-12
== Step 3: Sending flash sequence commands at 2025-07-09T16:08:03+08:00 ==
Waiting for USB storage device flashpkg from 4ce67d9d.......[/dev/sda]
Device size in blocks: 262144
Unmounted /dev/sda.
== Step 4: Writing partitions on external storage device at 2025-07-09T16:08:28+08:00 ==
Waiting for USB storage device nvme0n1 from 4ce67d9d.........................................[got flashpkg when expecting nvme0n1]
ERR: could not find nvme0n1
ERR: write failure to external storage at 2025-07-09T16:11:41+08:00

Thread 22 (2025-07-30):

Cross-over connections between RX+ and RX- and between TX+ and TX- pins

avinashkrg90, 2025-07-30:
In page no 5 (USB3) schematic, the IC HD3SS3220RNHT is used as a mux-demux for USB signals meant for debug purpose. Pin no 9 and 10 (RX+ and RX-) are tied to the SODIMM pins in a cross-over manner, that is RX+ is going to USBSS2_RX_N and similarly the RX - is going to the USBSS2_RX_P, as can be shown in the screenshot attached.

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

As per datasheet, shouldn't they be connected without a cross-over, i.e. +ve with +ve and -ve with -ve.
Please look into this once.

Closed 2025-07-31.

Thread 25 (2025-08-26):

Trying to configure Vision Components IMX412C cameras on Jetson Orin baseboard, cameras seem to probe (mostly) ok but am running into some issues

dburr, 2025-08-26:
# Trying to configure Vision Components IMX412C cameras on Jetson Orin baseboard, cameras seem to probe (mostly) ok but am running into some issues

I am attempting to configure dual [Vision Components IMX412c sensors](https://www.mipi-modules.com/en/mipi-camera-modules-technical-data/) on an Antmicro Jetson Orin Baseboard with an Orin NX 8 GB SOM, and am running into some problems, probably due to the unusual I/O arrangement (gpio and i2c muxes.)

The GPIO mux is properly detected and I have verified that the cameras are receiving power (I have the GPIO lines locked "high" (camera power lines are active high.)

```text
[    7.346186] pca953x 1-0020: supply vcc not found, using dummy regulator
[    7.353151] pca953x 1-0020: using no AI
[    7.359941] gpio-308 (csia_pen-hog): hogged as output/high
[    7.366220] gpio-309 (csib_pen-hog): hogged as output/low
[    7.372399] gpio-310 (usbc1_pen-hog): hogged as output/high
[    7.378761] gpio-311 (disable_poe_dcdc-hog): hogged as output/low
[    7.385527] gpiochip2: registered GPIOs 308 to 315 on 1-0020
```

And the i2c mux also appears to be properly configured, and indeed the cameras themselves appear to probe as well... mostly.

```text
[    7.394145] pca954x 2-0070: supply vcc not found, using dummy regulator
[    7.401074] pca954x 2-0070: supply vcc-pullup not found, using dummy regulator
[    7.408587] pca954x 2-0070: pca954x_probe: forcing device bus number, start 30.
[    7.416742] vc_mipi 30-001a: vc_probe(): Probing UNIVERSAL VC MIPI Driver (v0.18.3)
[    7.519194] i2c 30-0010: +--- VC MIPI Camera -----------------------------------+
[    7.526887] i2c 30-0010: | MANUF. | Vision Components               MID: 0x0427 |
[    7.534577] i2c 30-0010: | MODULE | ID:  0x0412                     REV:   0004 |
[    7.549169] i2c 30-0010: | SENSOR | SONY IMX412C                                |
[    7.556859] i2c 30-0010: +--------+---------------------------------------------+
[    7.564552] i2c 30-0010: +--- Sensor Registers ------+--------+--------+--------+
[    7.572246] i2c 30-0010: |                           | low    | mid    | high   |
[    7.579940] i2c 30-0010: +---------------------------+--------+--------+--------+
[    7.587628] i2c 30-0010: | idle                      | 0x0100 |        |        |
[    7.595321] i2c 30-0010: | horizontal start          | 0x0345 | 0x0344 |        |
[    7.603009] i2c 30-0010: | vertical start            | 0x0347 | 0x0346 |        |
[    7.610698] i2c 30-0010: | horizontal end            | 0x0349 | 0x0348 |        |
[    7.618394] i2c 30-0010: | vertical end              | 0x034b | 0x034a |        |
[    7.626090] i2c 30-0010: | hor. output width         | 0x034d | 0x034c |        |
[    7.633784] i2c 30-0010: | ver. output height        | 0x034f | 0x034e |        |
[    7.641480] i2c 30-0010: | exposure                  | 0x0200 | 0x0203 | 0x0202 |
[    7.649179] i2c 30-0010: | gain                      | 0x0205 | 0x0204 |        |
[    7.656873] i2c 30-0010: +---------------------------+--------+--------+--------+
[    7.664571] i2c 30-0010: | clock for ext. trigger    |        0 Hz              |
[    7.672276] i2c 30-0010: | pixel clock               |        0 Hz              |
[    7.679971] i2c 30-0010: | shutter offset            |        0 us              |
[    7.687669] i2c 30-0010: +---------------------------+--------------------------+
[    7.695364] i2c 30-0010: +--- Module Modes -------+---------+---------+---------+
[    7.703062] i2c 30-0010: |  # | rate    | lanes   | format  | type    | binning |
[    7.703064] i2c 30-0010: +----+---------+---------+---------+---------+---------+
[    7.703070] i2c 30-0010: |  0 |    1350 |       2 | RAW10   | STREAM  |       0 |
[    7.703072] i2c 30-0010: |  1 |    1350 |       4 | RAW10   | STREAM  |       0 |
[    7.719181] i2c 30-0010: |  2 |    1350 |       2 | RAW10   | SLAVE   |       0 |
[    7.719182] i2c 30-0010: |  3 |    1350 |       4 | RAW10   | SLAVE   |       0 |
[    7.734578] i2c 30-0010: +----+---------+---------+---------+---------+---------+
[    7.749622] i2c 30-0010: vc_init_ctrl_imx412(): Initialising module control for IMX412
[    7.765030] i2c 30-0010: +-------+--------+------------+-----------+
[    7.806150] i2c 30-0010: | lanes | format | exposure   | framerate |
[    7.812690] i2c 30-0010: |       |        | max [us]   | max [mHz] |
[    7.819219] i2c 30-0010: +-------+--------+------------+-----------+
[    7.825761] i2c 30-0010: |     2 | RAW10  |    1058097 |     20028 |
[    7.832289] i2c 30-0010: |     4 | RAW10  |     529048 |     40057 |
[    7.838820] i2c 30-0010: |     2 | RAW10  |    1058097 |     20028 |
[    7.838822] i2c 30-0010: |     4 | RAW10  |     529048 |     40057 |
[    7.838824] i2c 30-0010: |     2 | RAW10  |    1058097 |     20028 |
[    7.838827] i2c 30-0010: |     4 | RAW10  |     529048 |     40057 |
[    7.838829] i2c 30-0010: |     2 | RAW10  |    1058097 |     20028 |
[    7.878951] i2c 30-0010: |     4 | RAW10  |     529048 |     40057 |
[    7.885496] i2c 30-0010: |     2 | RAW10  |    1058097 |     20028 |
[    7.892026] i2c 30-0010: |     4 | RAW10  |     529048 |     40057 |
[    7.898570] i2c 30-0010: |     2 | RAW10  |    1058097 |     20028 |
[    7.905112] i2c 30-0010: |     4 | RAW10  |     529048 |     40057 |
[    7.911653] i2c 30-0010: +-------+--------+------------+-----------+
[    7.918184] i2c 30-0010: VC MIPI Core successfully initialized
[    7.924176] vc_mipi 30-001a: vc_init_io(): Init trigger and flash mode
[    7.939297] i2c 30-0010: vc_mod_set_trigger_mode(): Set trigger mode: DISABLED
[    7.954051] i2c 30-0010: vc_mod_set_io_mode(): Set IO mode: DISABLED
[    7.965789] vc_mipi 30-001a: vc_init_frmfmt(): Init frame (width: 4032, height: 3040, fps: 0)
[    7.980174] vc_mipi 30-001a: vc_init_binning(): Init binning modes
[    7.980373] vc_mipi 30-001a: tegracam sensor driver:vc_mipi_v2.0.6
[    7.990550] tegra-camrtc-capture-vi tegra-capture-vi: subdev vc_mipi 30-001a bound
[    8.009161] vc_mipi 30-001a: vc_core_set_num_lanes(): Set number of lanes 4
[    8.016330] vc_mipi 30-001a: vc_init_lanes(): Init lanes (num_lanes: 4)
[    8.023138] vc_mipi 30-001a: vc_init_tegra_controls(): Read control gain (min: 0, max: 48000, default: 0)
[    8.032974] vc_mipi 30-001a: vc_init_tegra_controls(): Overwrite control exposure (min: 1, max: 529048, default: 10000)
[    8.044065] vc_mipi 30-001a: vc_init_tegra_controls(): Overwrite control framerate (min: 0, max: 40057, default: 0)
```

The cameras do appear to be communicating (at least somewhat) over i2c, as much of the probed data is correct and makes sense (module name and ID, revision, MID, sensor name, etc.) I am unsure of what the correct values for some of the properties should be (horizontal start, vertical start, etc.) however I am almost certain that some of them are bogus (for example, ext. trigger clock, pixel clock, and shutter offset of 0 looks bogus to me.)

I have tried running image capture commands (nvgstcapture-1.0, etc.) and all I see is a completely black image.

Any advice/assistance is much appreciated. I am wondering (hoping) if there is something simple that I have overlooked, because this seems like it is very close to working.

Below I have attached my .dtsi file as well as the full kernel log (dmesg.)

Artifacts:

* [My DTSI file](https://github.com/user-attachments/files/21997547/tegra234-camera-vc-mipi-cam.dtsi.txt)
* [Full kernel log (dmesg) output](https://github.com/user-attachments/files/21997551/dmesg.new.txt)

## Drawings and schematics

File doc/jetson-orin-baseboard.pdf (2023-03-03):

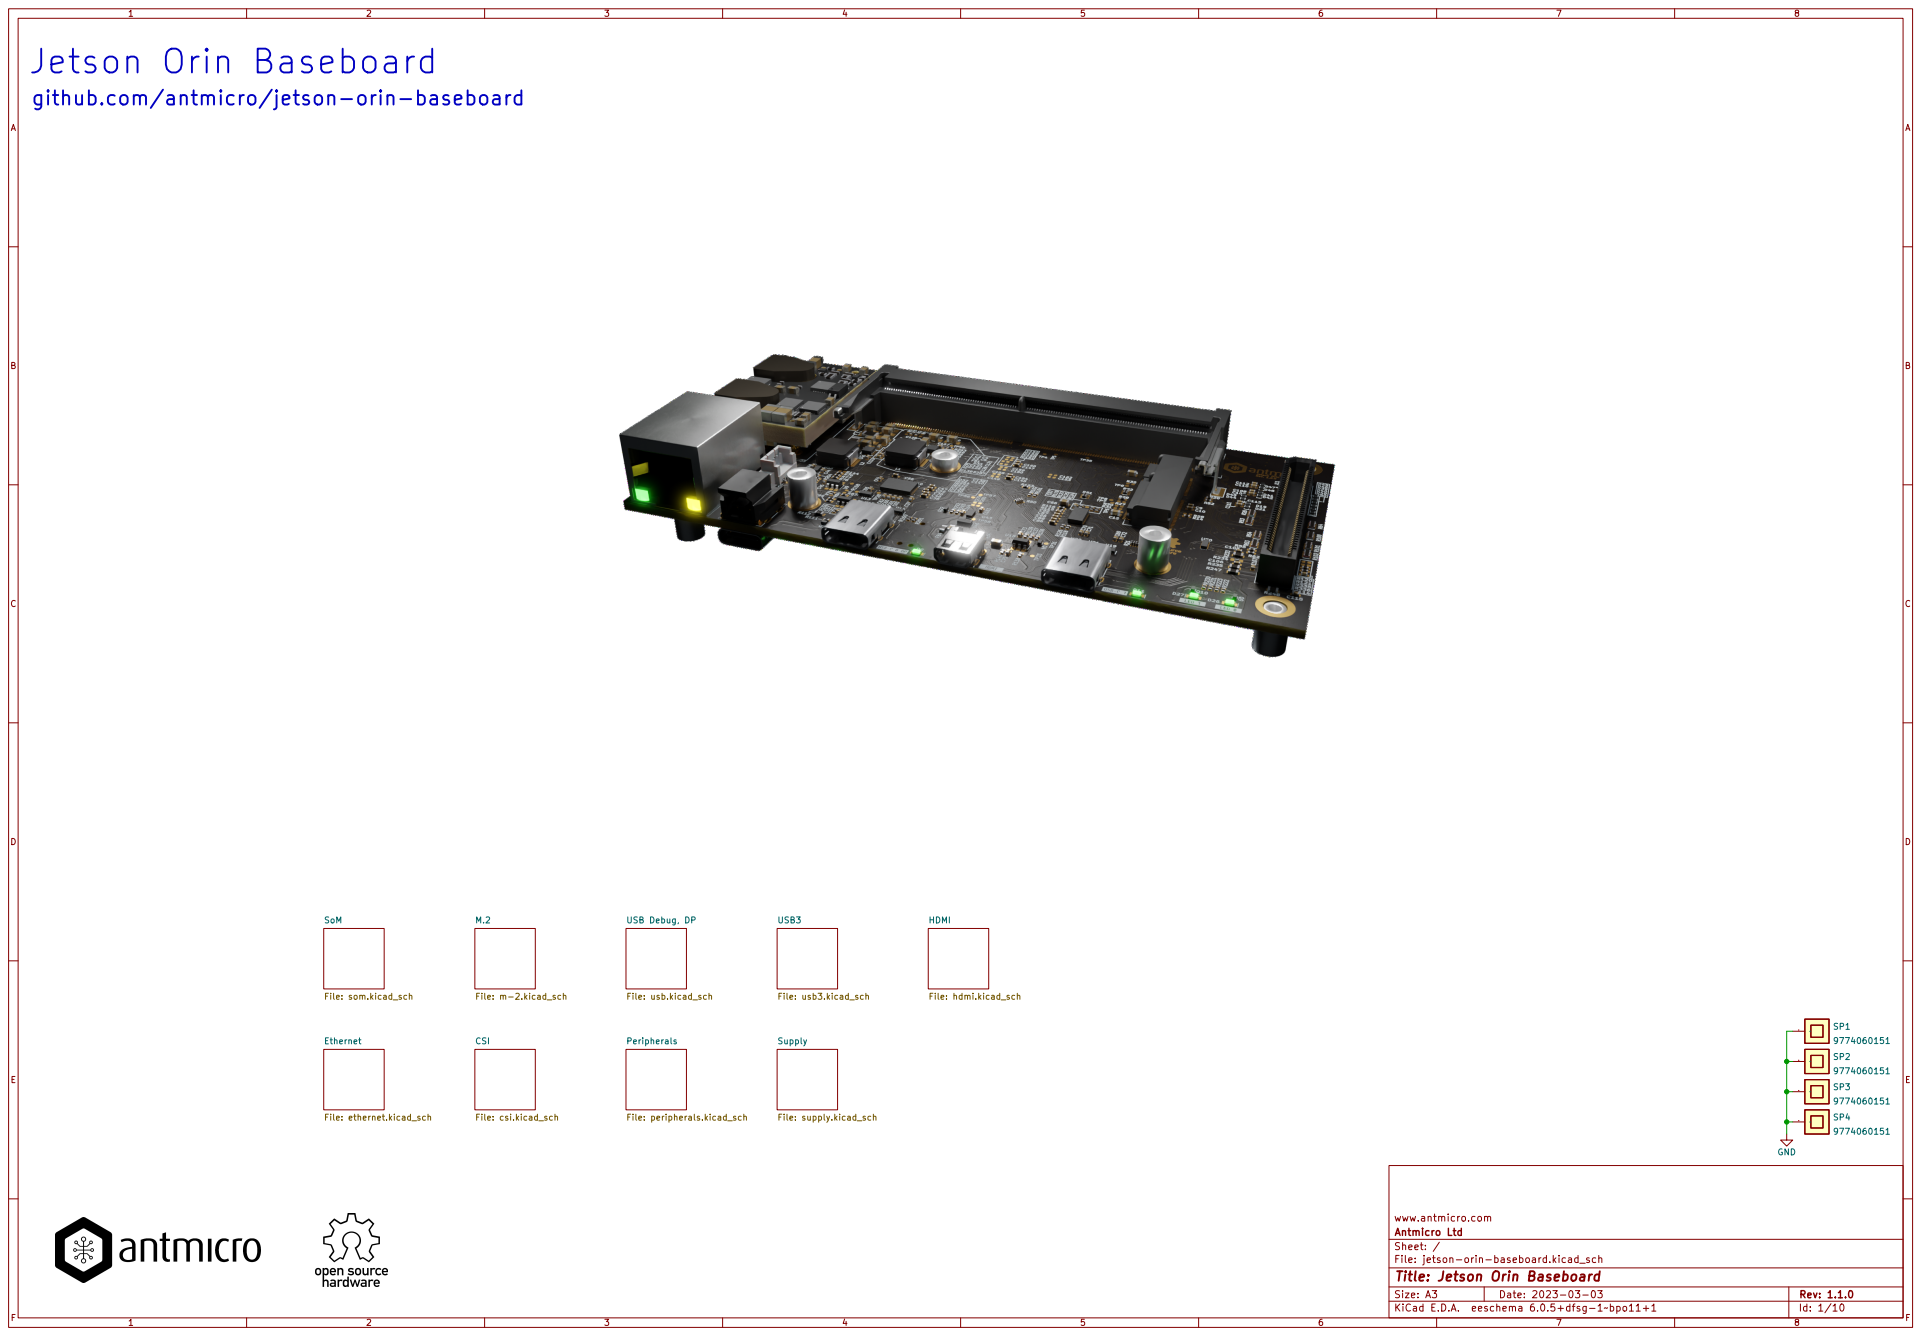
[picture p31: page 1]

9774060151 Jetson Orin Baseboard
github.com/antmicro/jetson-orin-baseboard

File: jetson-orin-baseboard.kicad_sch Sheet: / Antmicro Ltd www.antmicro.com

Id: 1/10 Title: Jetson Orin Baseboard

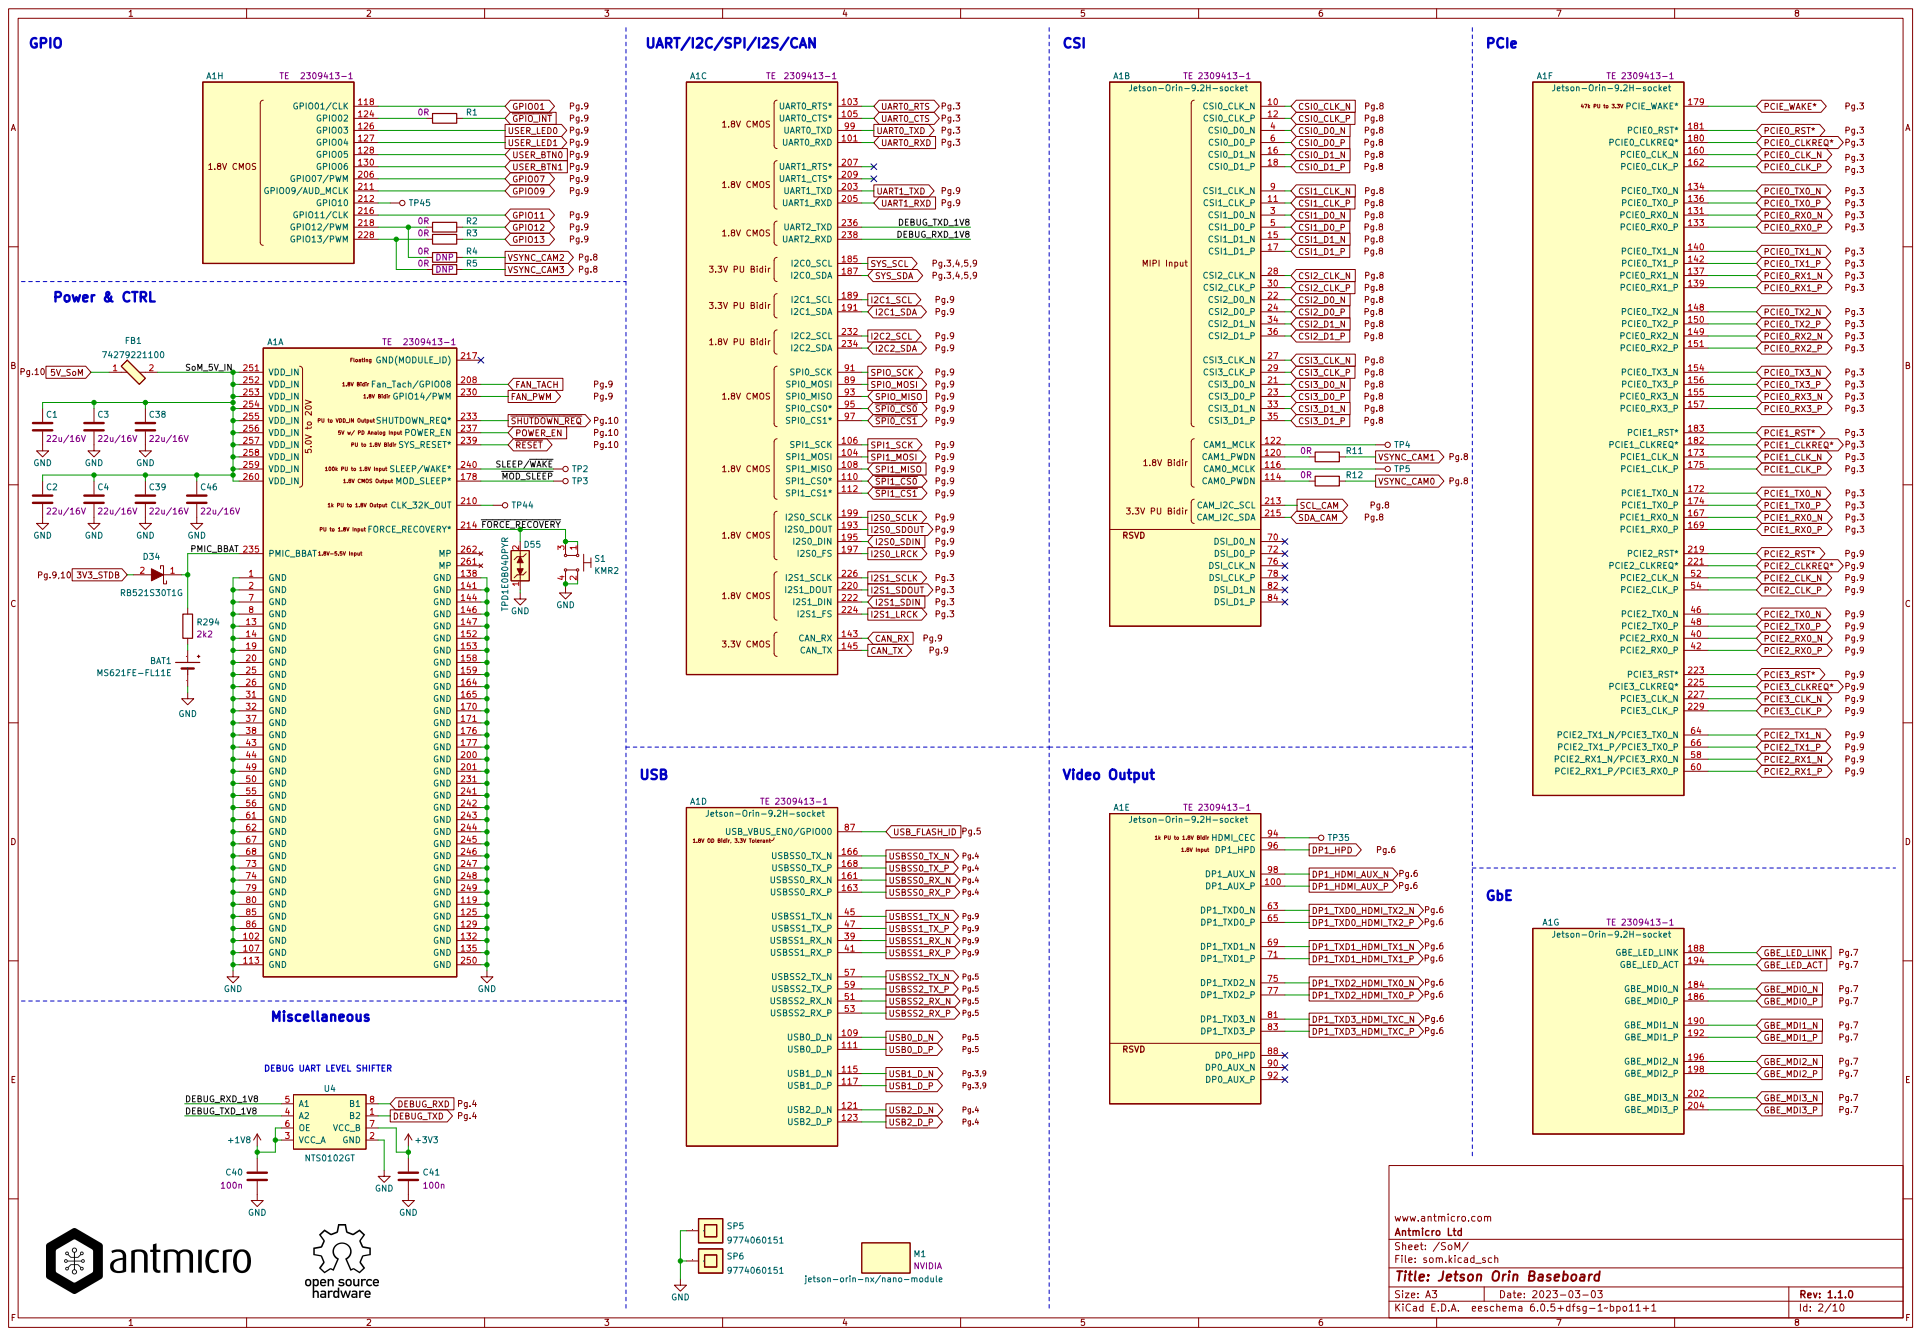
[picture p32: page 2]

Jetson-Orin-9.2H-socket TE 2309413-1

1.8V Bidir 3.3V PU Bidir MIPI Input RSVD

Video Output DEBUG UART LEVEL SHIFTER

1.8V Input 1k PU to 1.8V Bidir RSVD

File: som.kicad_sch Sheet: /SoM/ Antmicro Ltd www.antmicro.com

jetson-orin-nx/nano-moduleNVIDIA

Id: 2/10 Title: Jetson Orin Baseboard

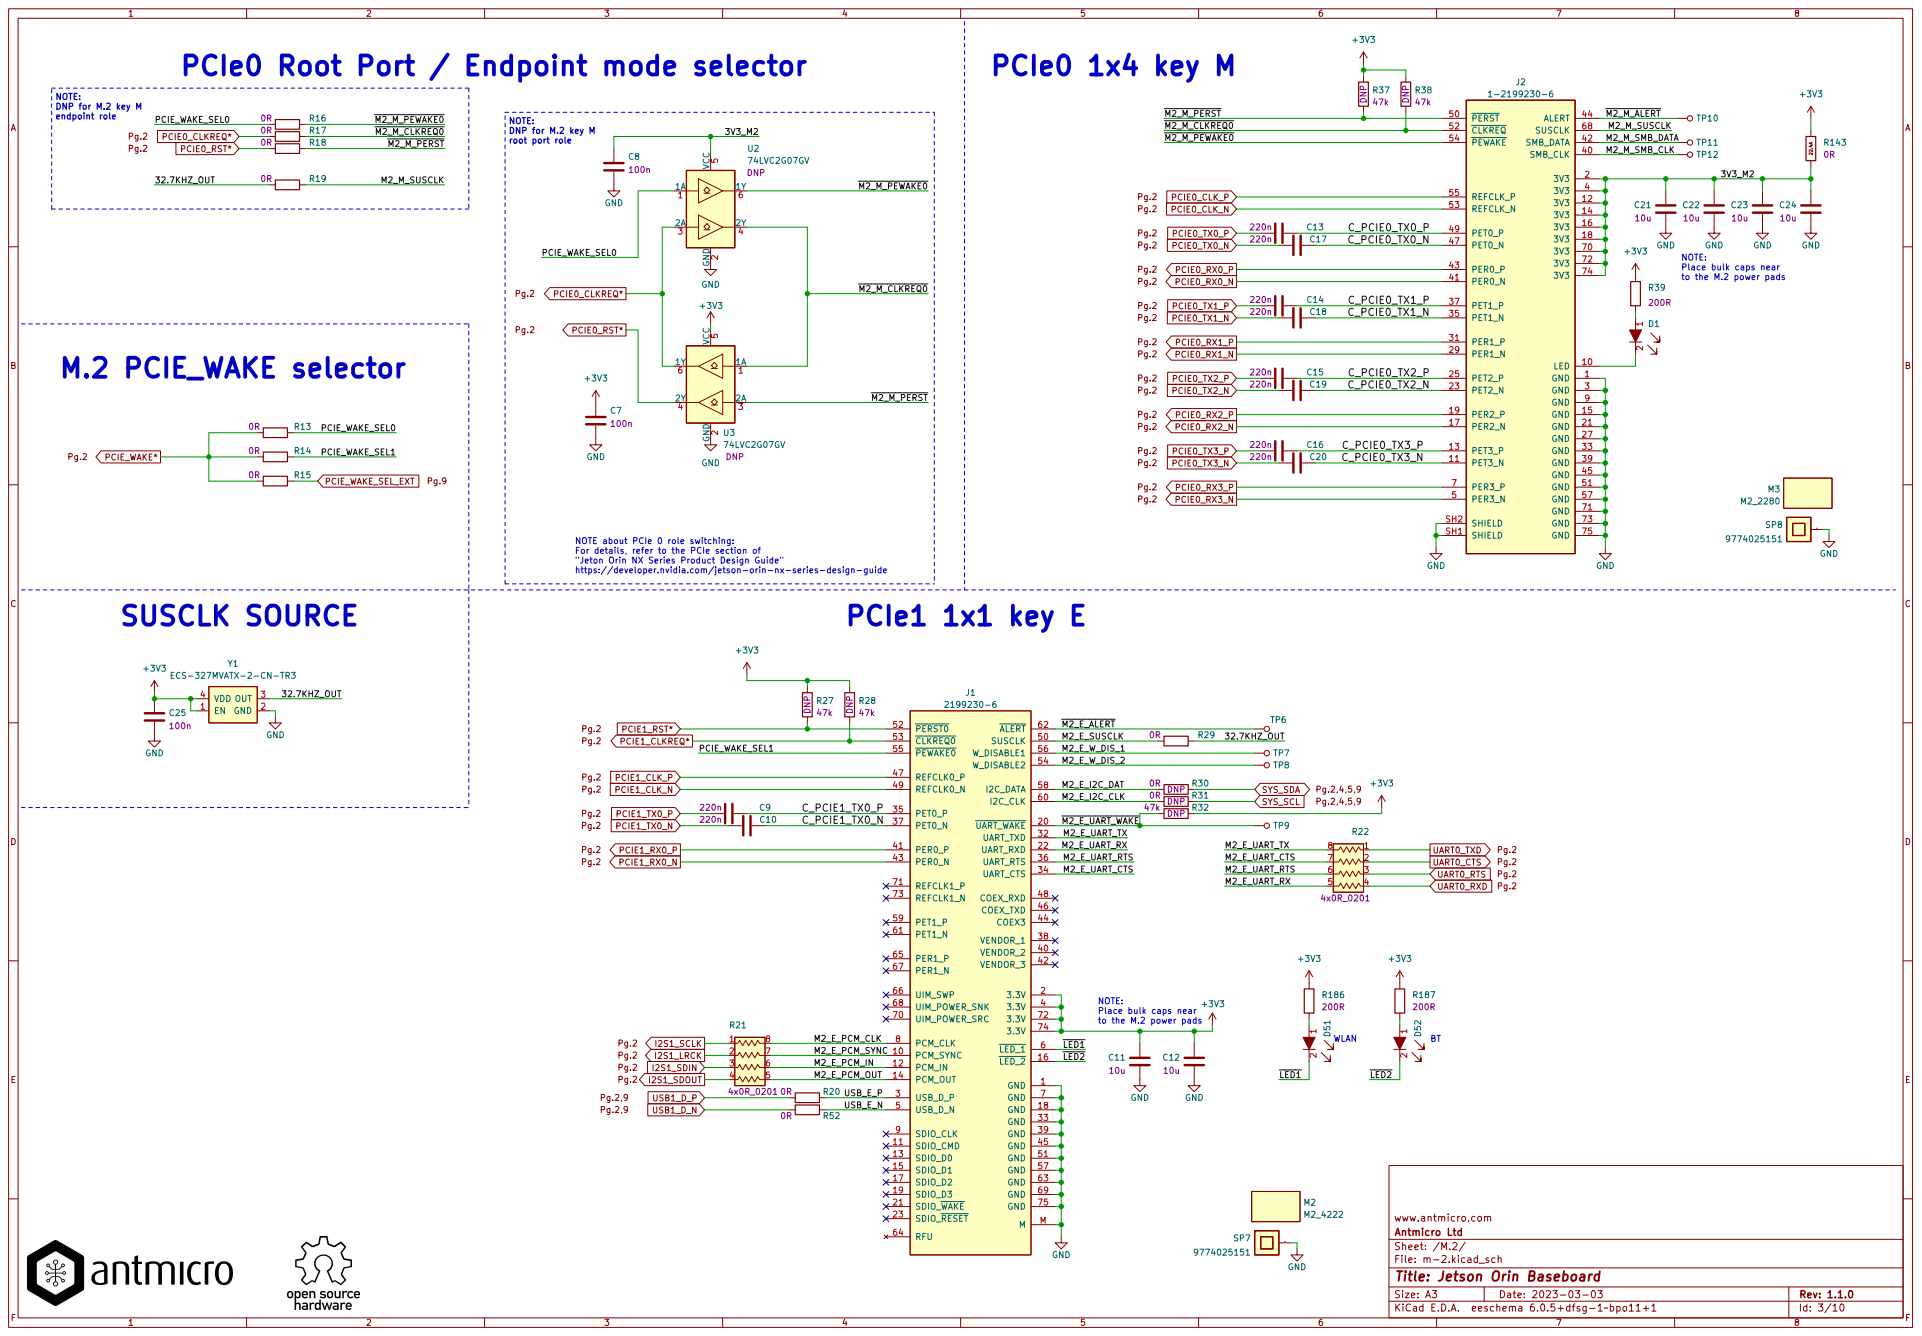
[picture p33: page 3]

PCIe0 Root Port / Endpoint mode selector

NOTE: DNP for M.2 key M

NOTE: Place bulk caps near

to the M.2 power pads

NOTE about PCIe 0 role switching: For details, refer to the PCIe section of "Jeton Orin NX Series Product Design Guide"

https://developer.nvidia.com/jetson-orin-nx-series-design-guide

47k | R32 DNP

C_PCIE1_TX0_N

File: m-2.kicad_sch Sheet: /M.2/ Antmicro Ltd www.antmicro.com

Id: 3/10 Title: Jetson Orin Baseboard

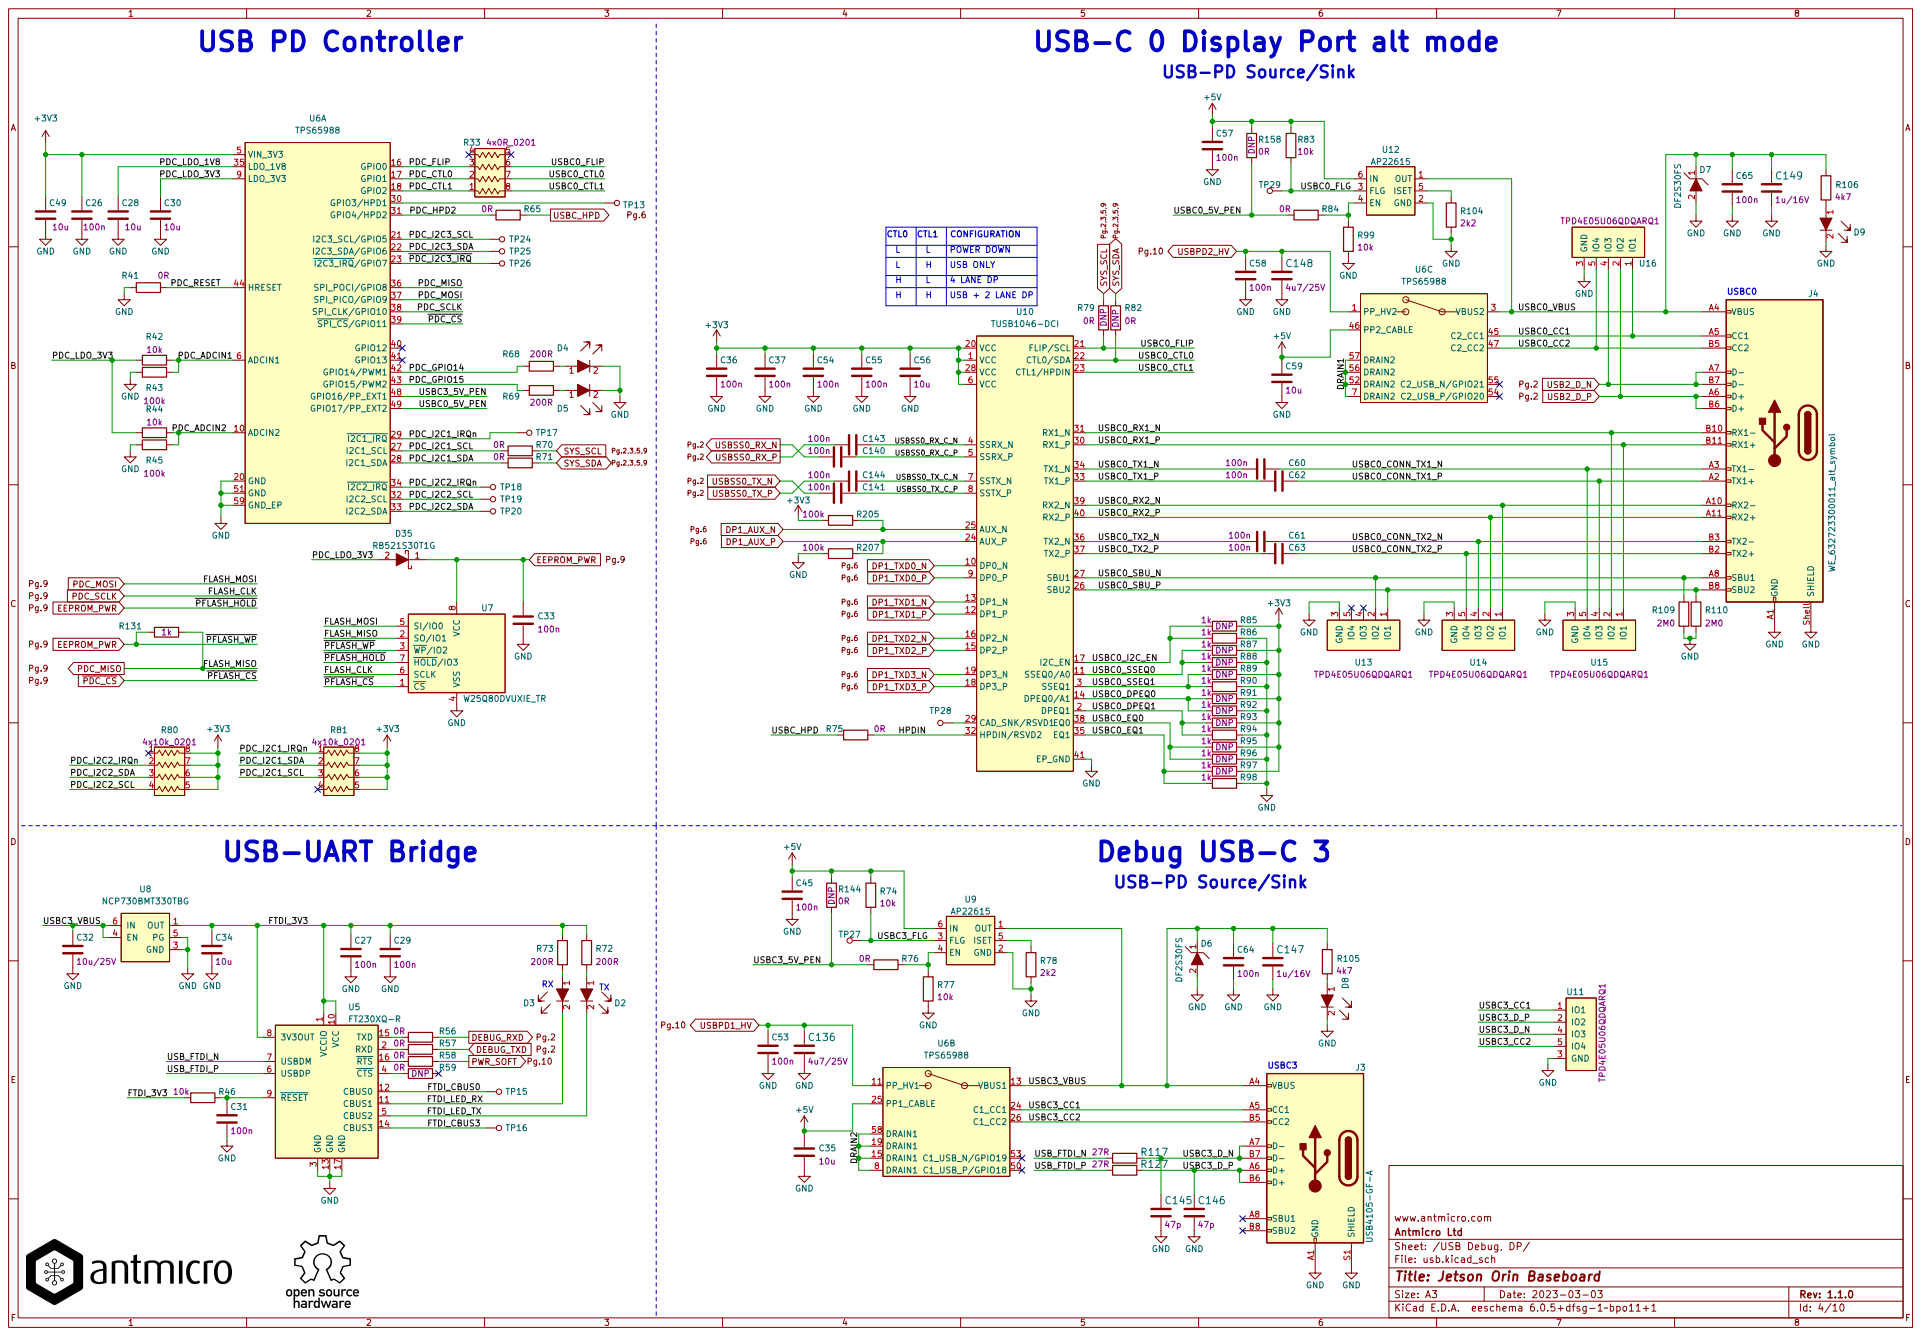
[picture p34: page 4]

USB-C 0 Display Port alt mode

4 LANE DP USB-UART Bridge

USB + 2 LANE DP CONFIGURATION

4 SI/IO0 5 SCLK 6 ~{HOLD}/IO3 7 VCC

USB-PD Source/Sink

1 VCC 10 CBUS1 11 CBUS0 12 GND 13 CBUS3 14 TXD 15 ~{RTS} 16 GND 17 RXD 2 GND

Sheet: /USB Debug, DP/ Antmicro Ltd www.antmicro.com

File: usb.kicad_sch
Id: 4/10 Title: Jetson Orin Baseboard

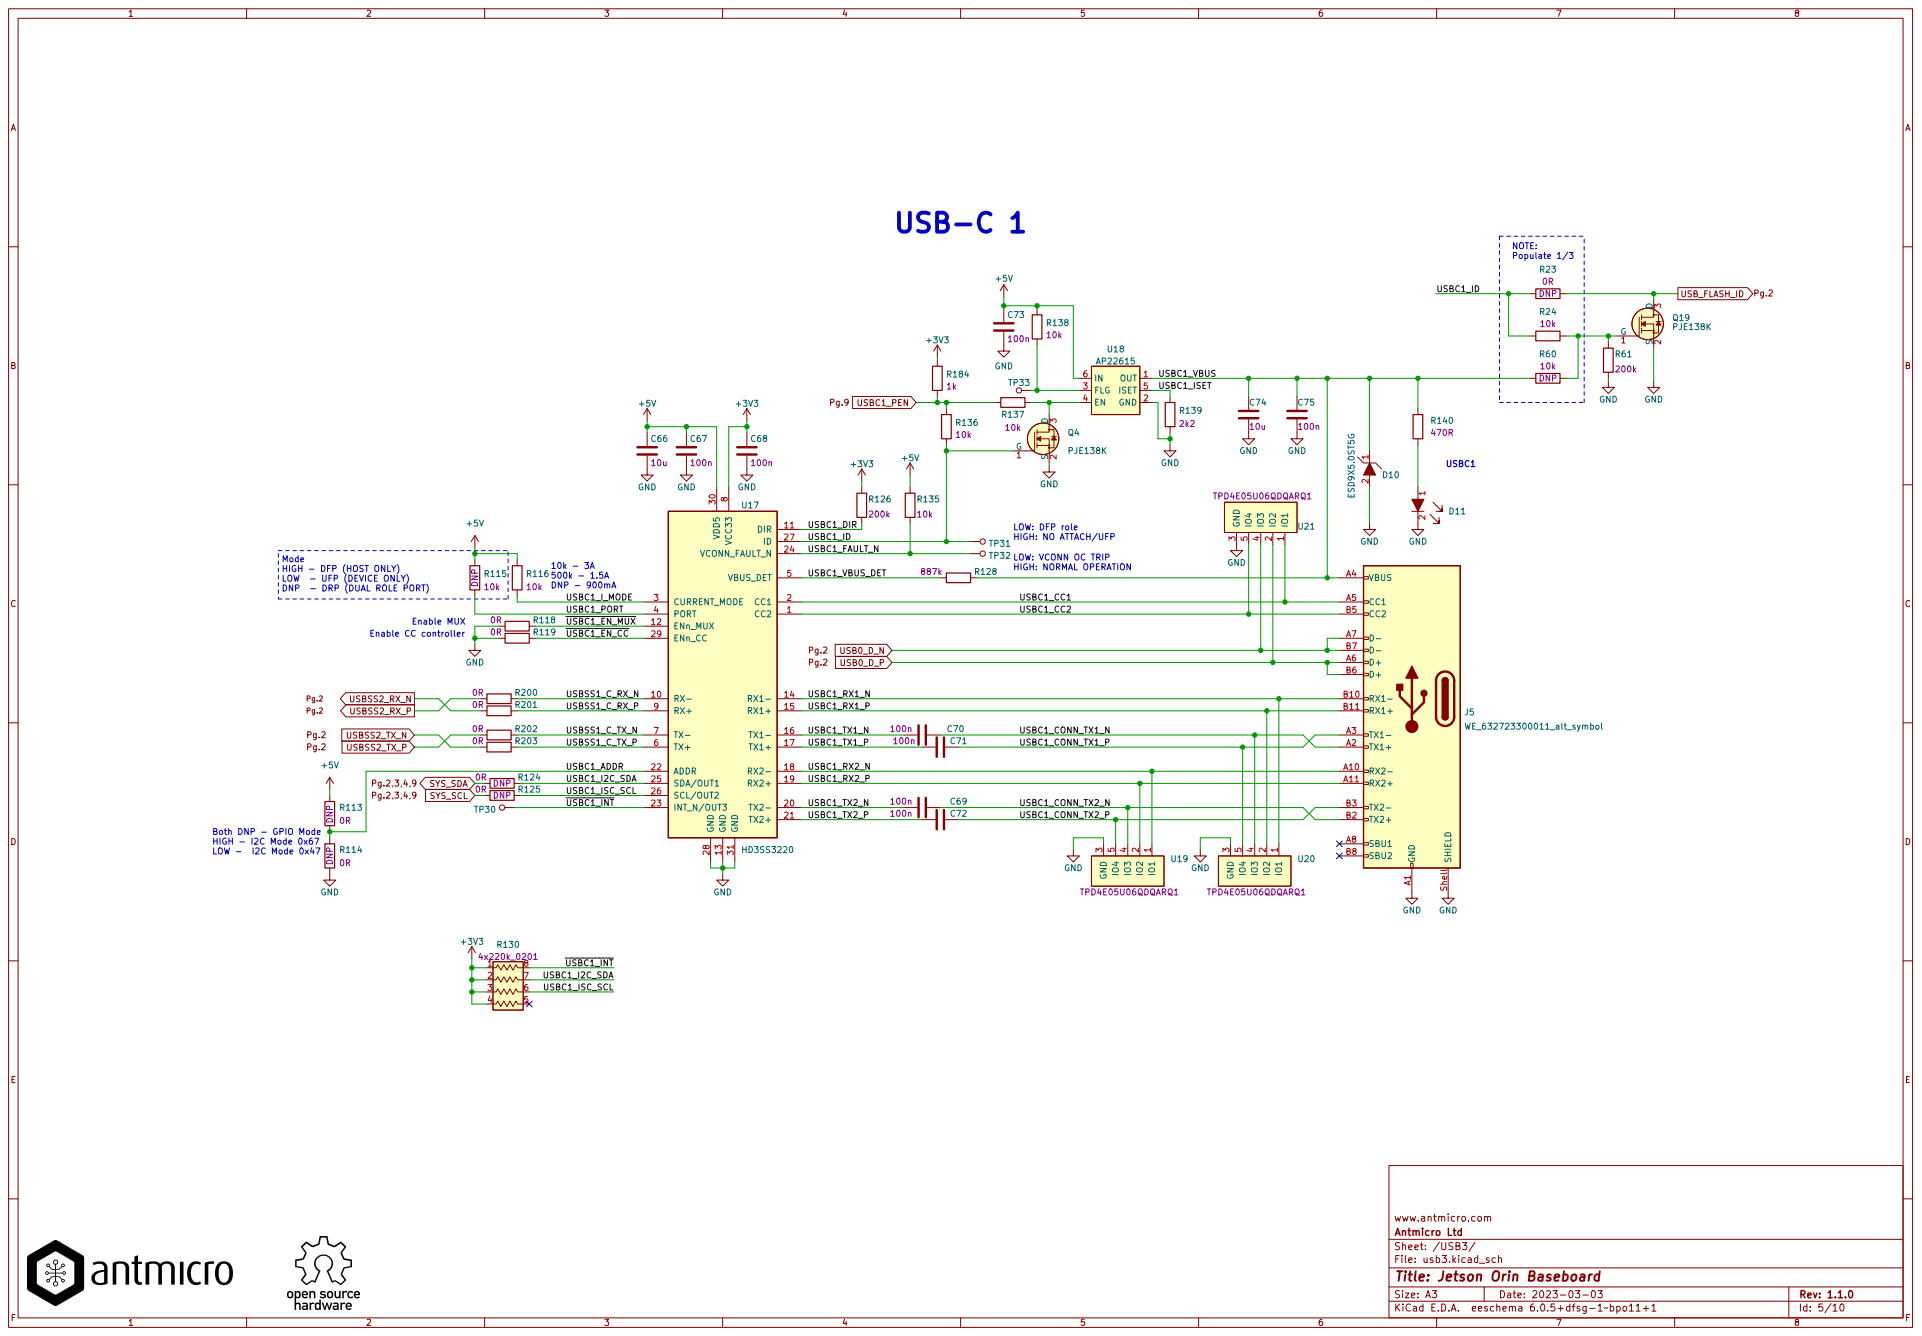
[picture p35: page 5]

USBC1 Both DNP - GPIO Mode HIGH - I2C Mode 0x67

Enable CC controller Mode HIGH - DFP (HOST ONLY)

LOW: VCONN OC TRIP HIGH: NORMAL OPERATION

LOW - UFP (DEVICE ONLY)
DNP - DRP (DUAL ROLE PORT) Enable MUX

File: usb3.kicad_sch Sheet: /USB3/ Antmicro Ltd www.antmicro.com

Id: 5/10 Title: Jetson Orin Baseboard

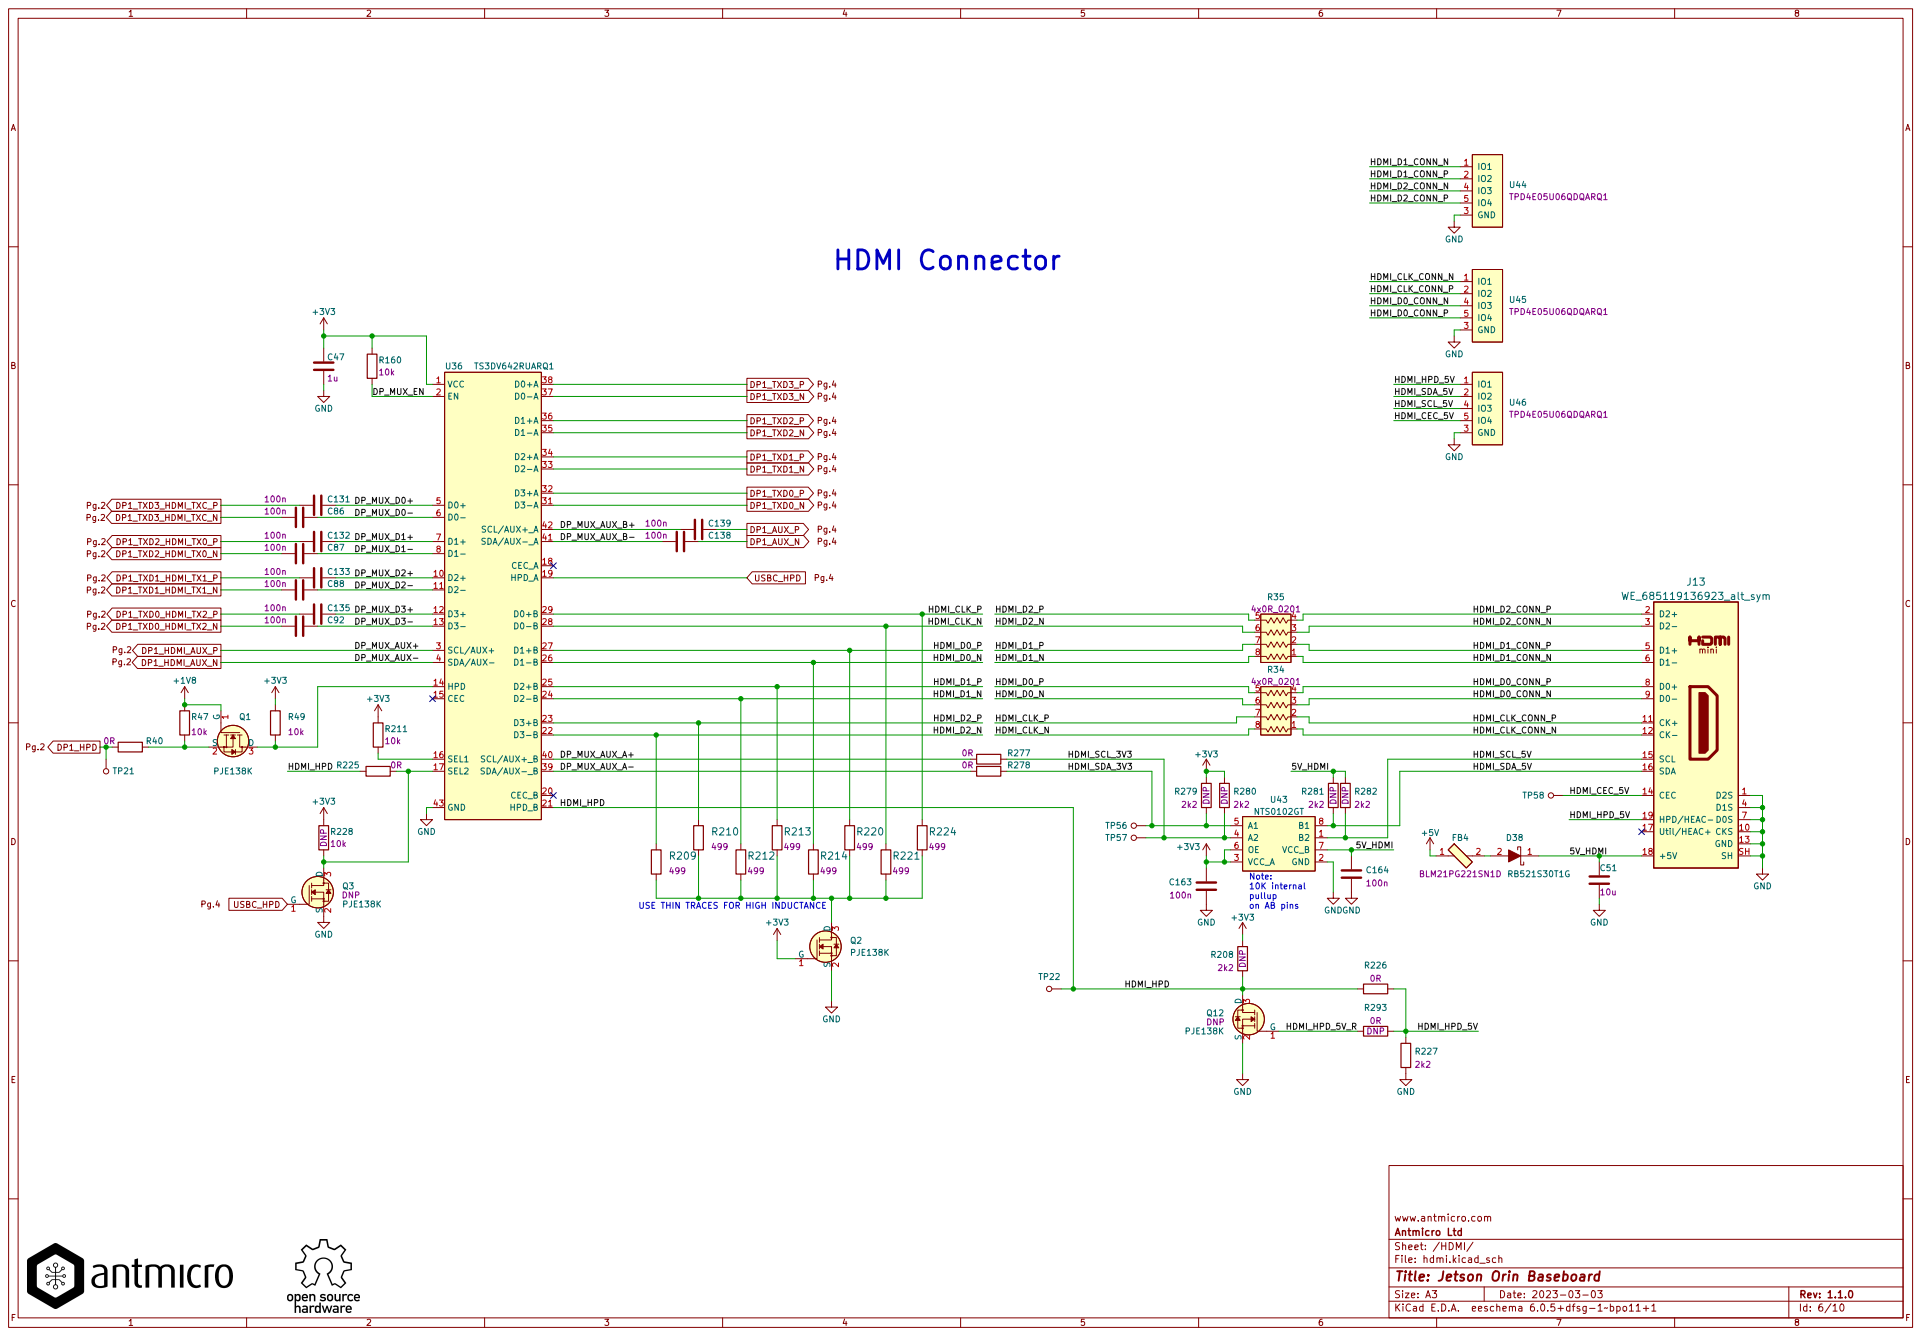
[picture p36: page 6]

File: hdmi.kicad_sch Sheet: /HDMI/ Antmicro Ltd www.antmicro.com

Id: 6/10 Title: Jetson Orin Baseboard

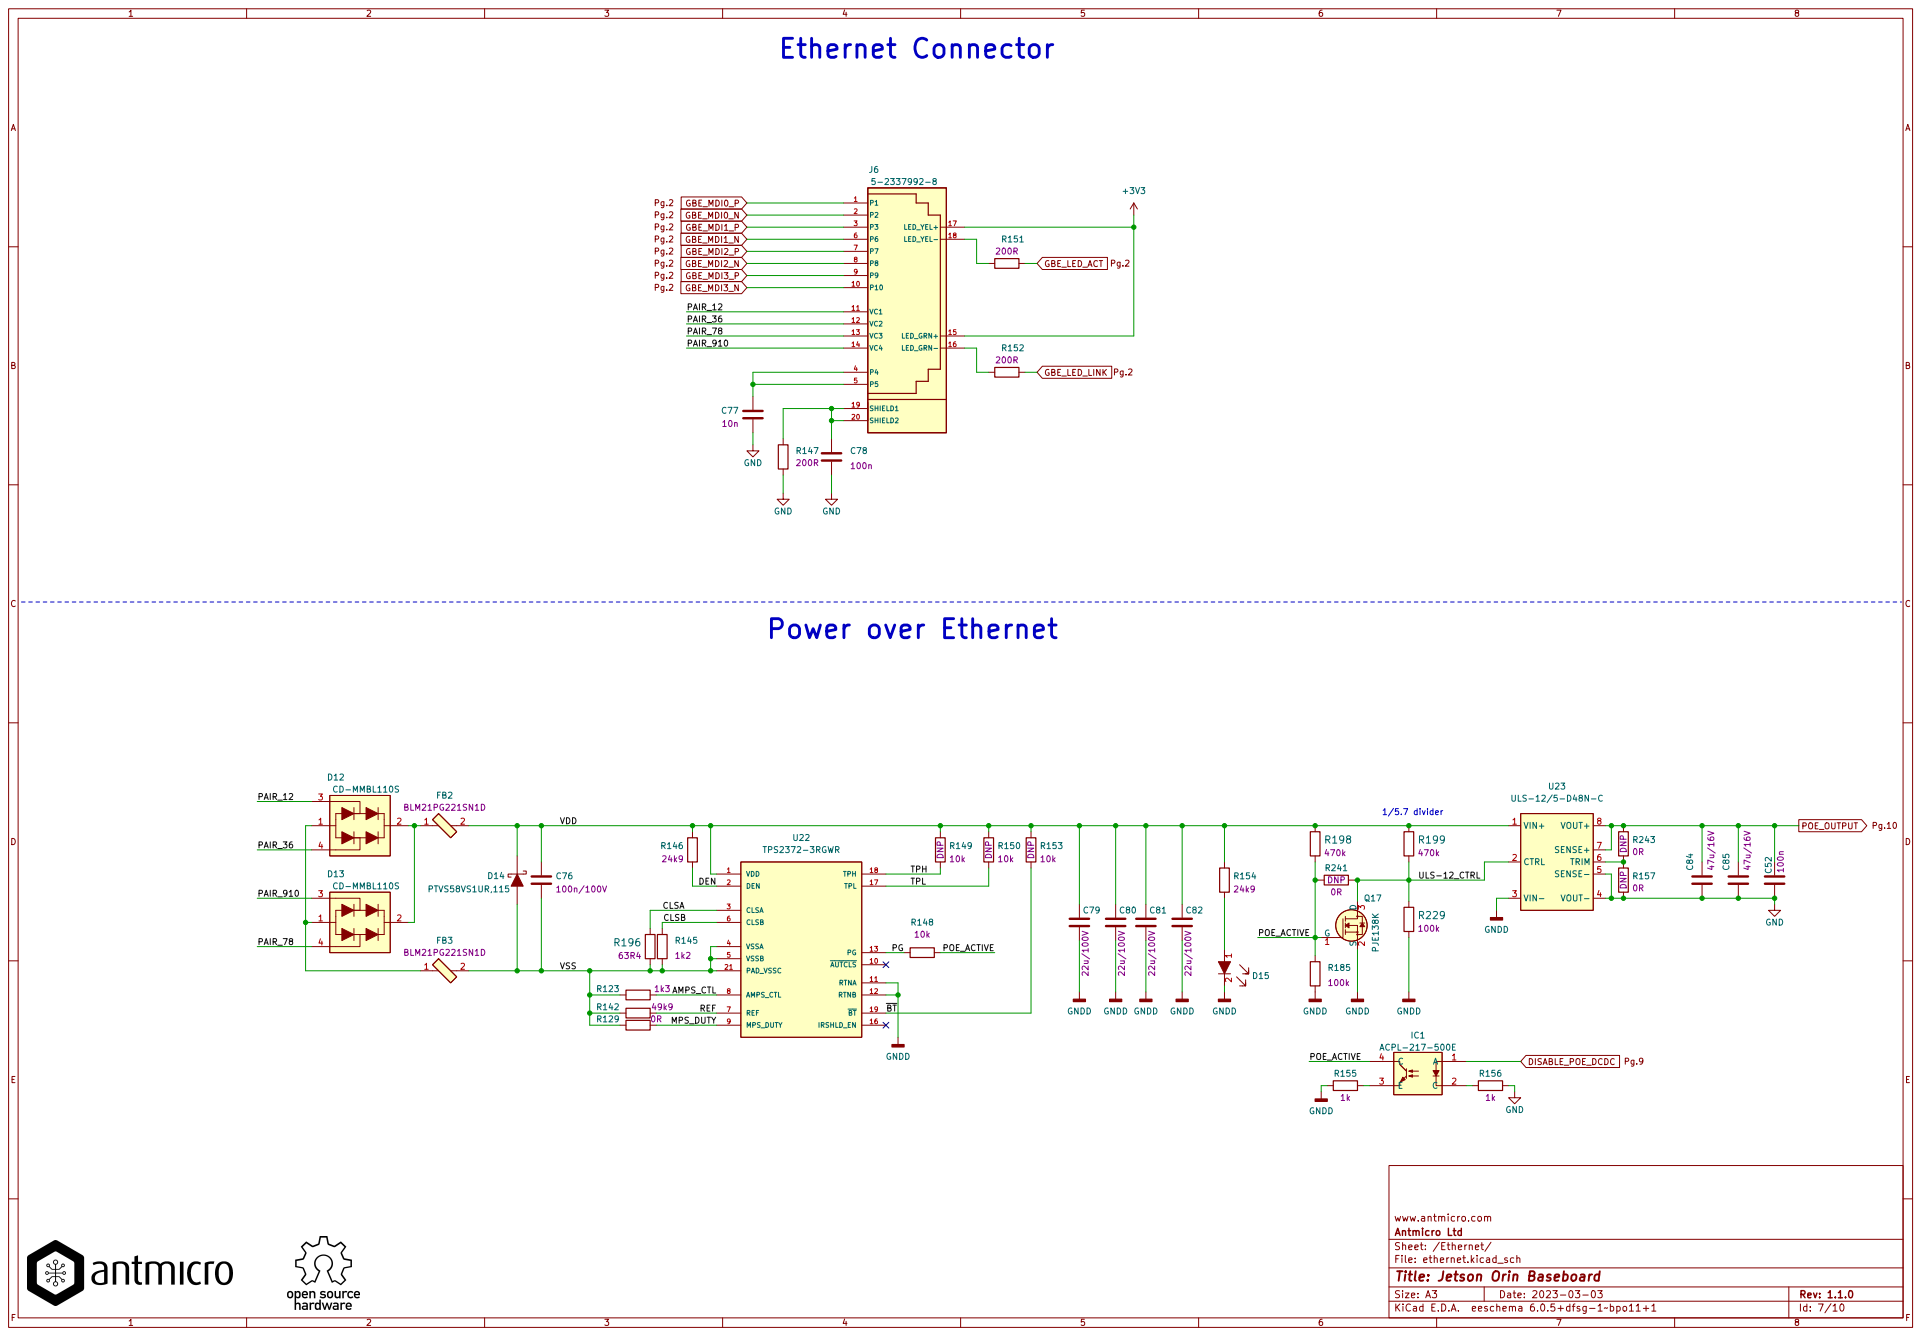
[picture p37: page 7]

TPL TPH Ethernet Connector

File: ethernet.kicad_sch Sheet: /Ethernet/ Antmicro Ltd www.antmicro.com

Id: 7/10 Title: Jetson Orin Baseboard

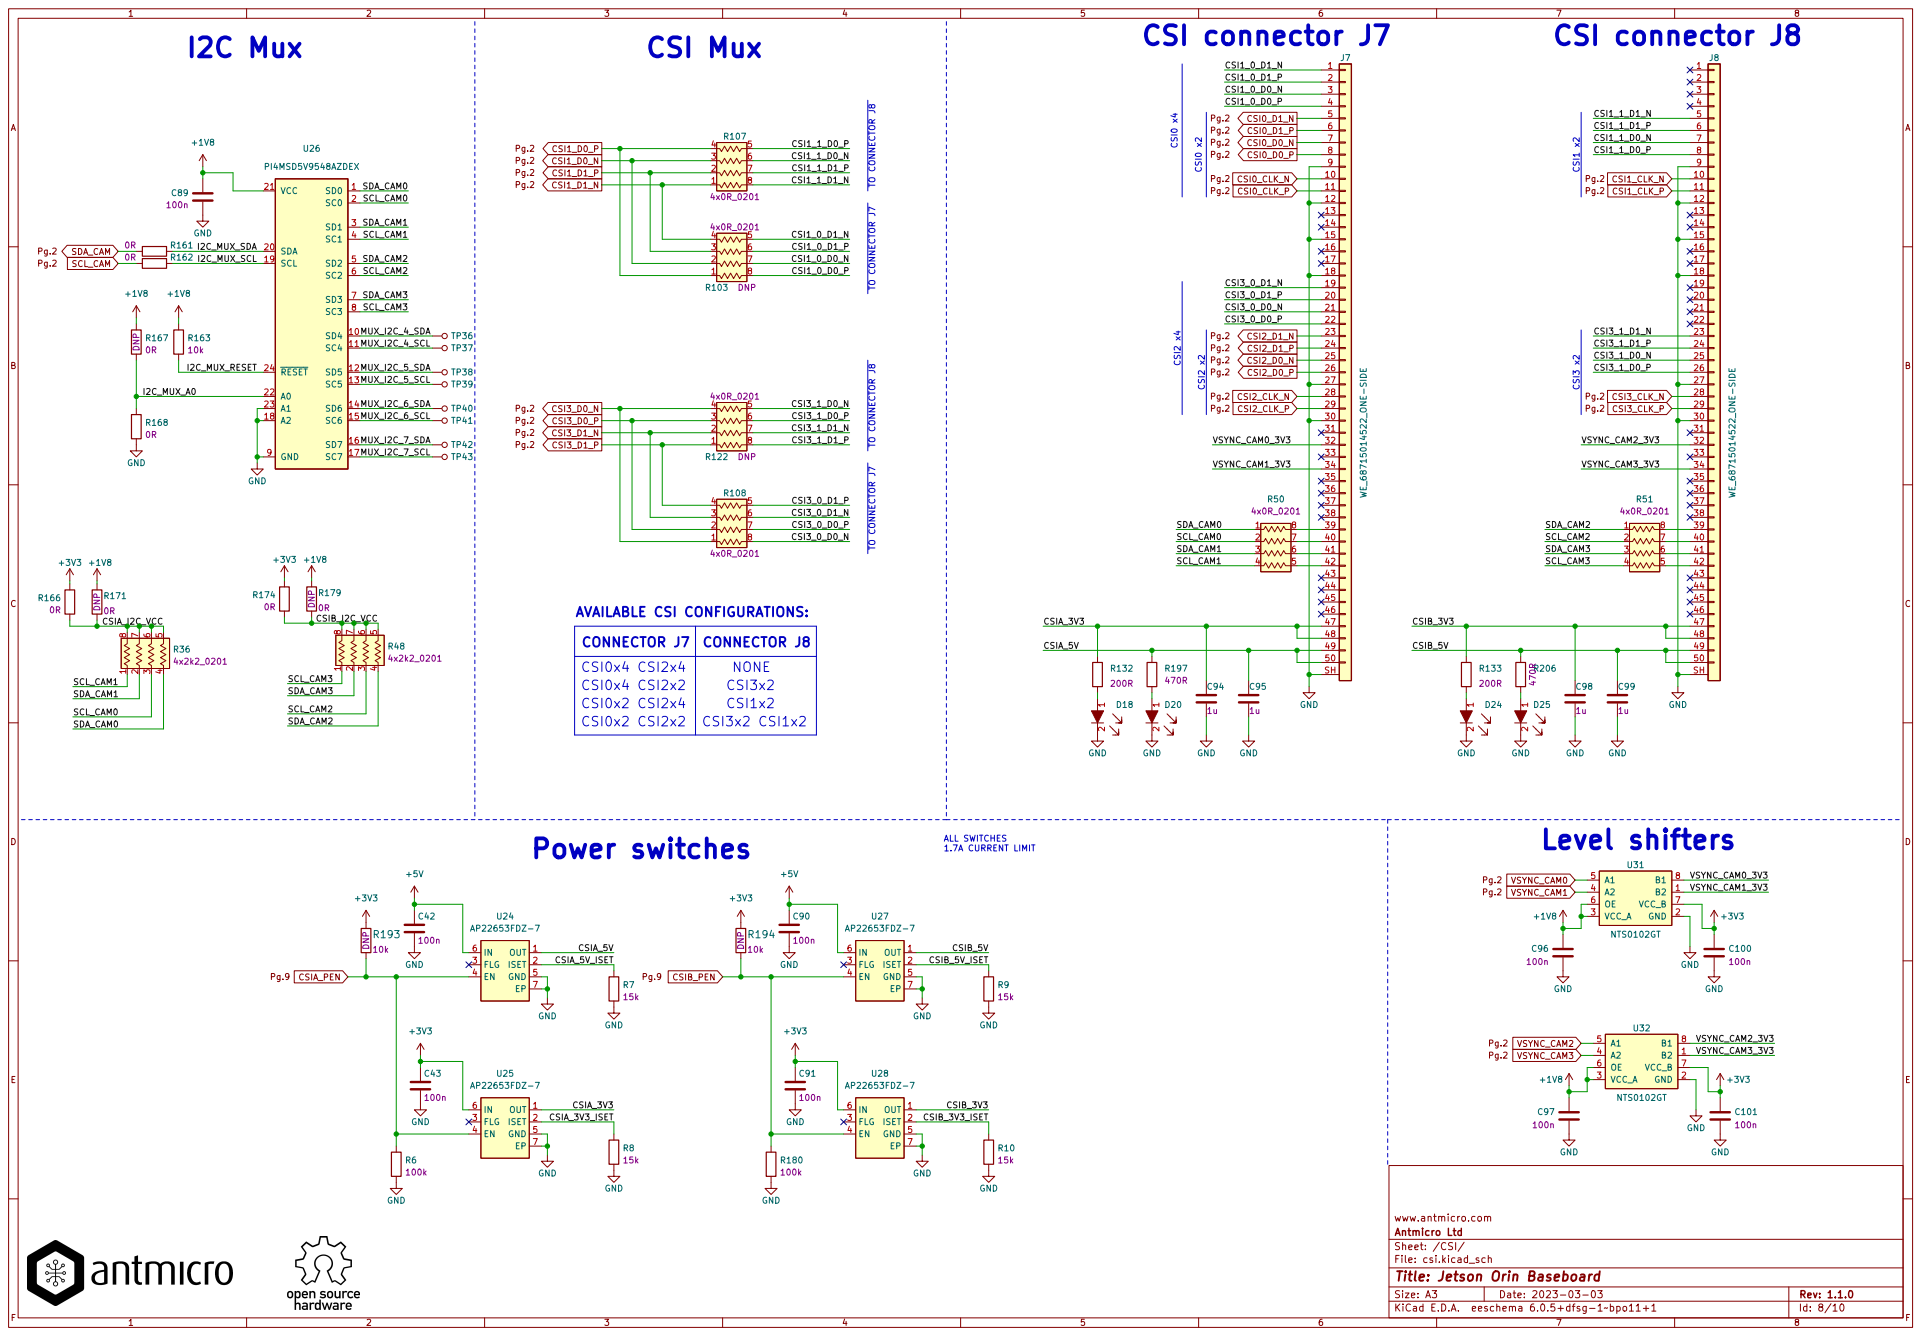
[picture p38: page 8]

CSI1_0_D0_P CSI2 x2
1.7A CURRENT LIMIT TO CONNECTOR J7

CONNECTOR J7 | CONNECTOR J8
CSI0x4 CSI2x4 CSI0x2 CSI2x2 | CSI3x2 CSI3x2 CSI1x2

File: csi.kicad_sch Sheet: /CSI/ Antmicro Ltd www.antmicro.com

Id: 8/10 Title: Jetson Orin Baseboard

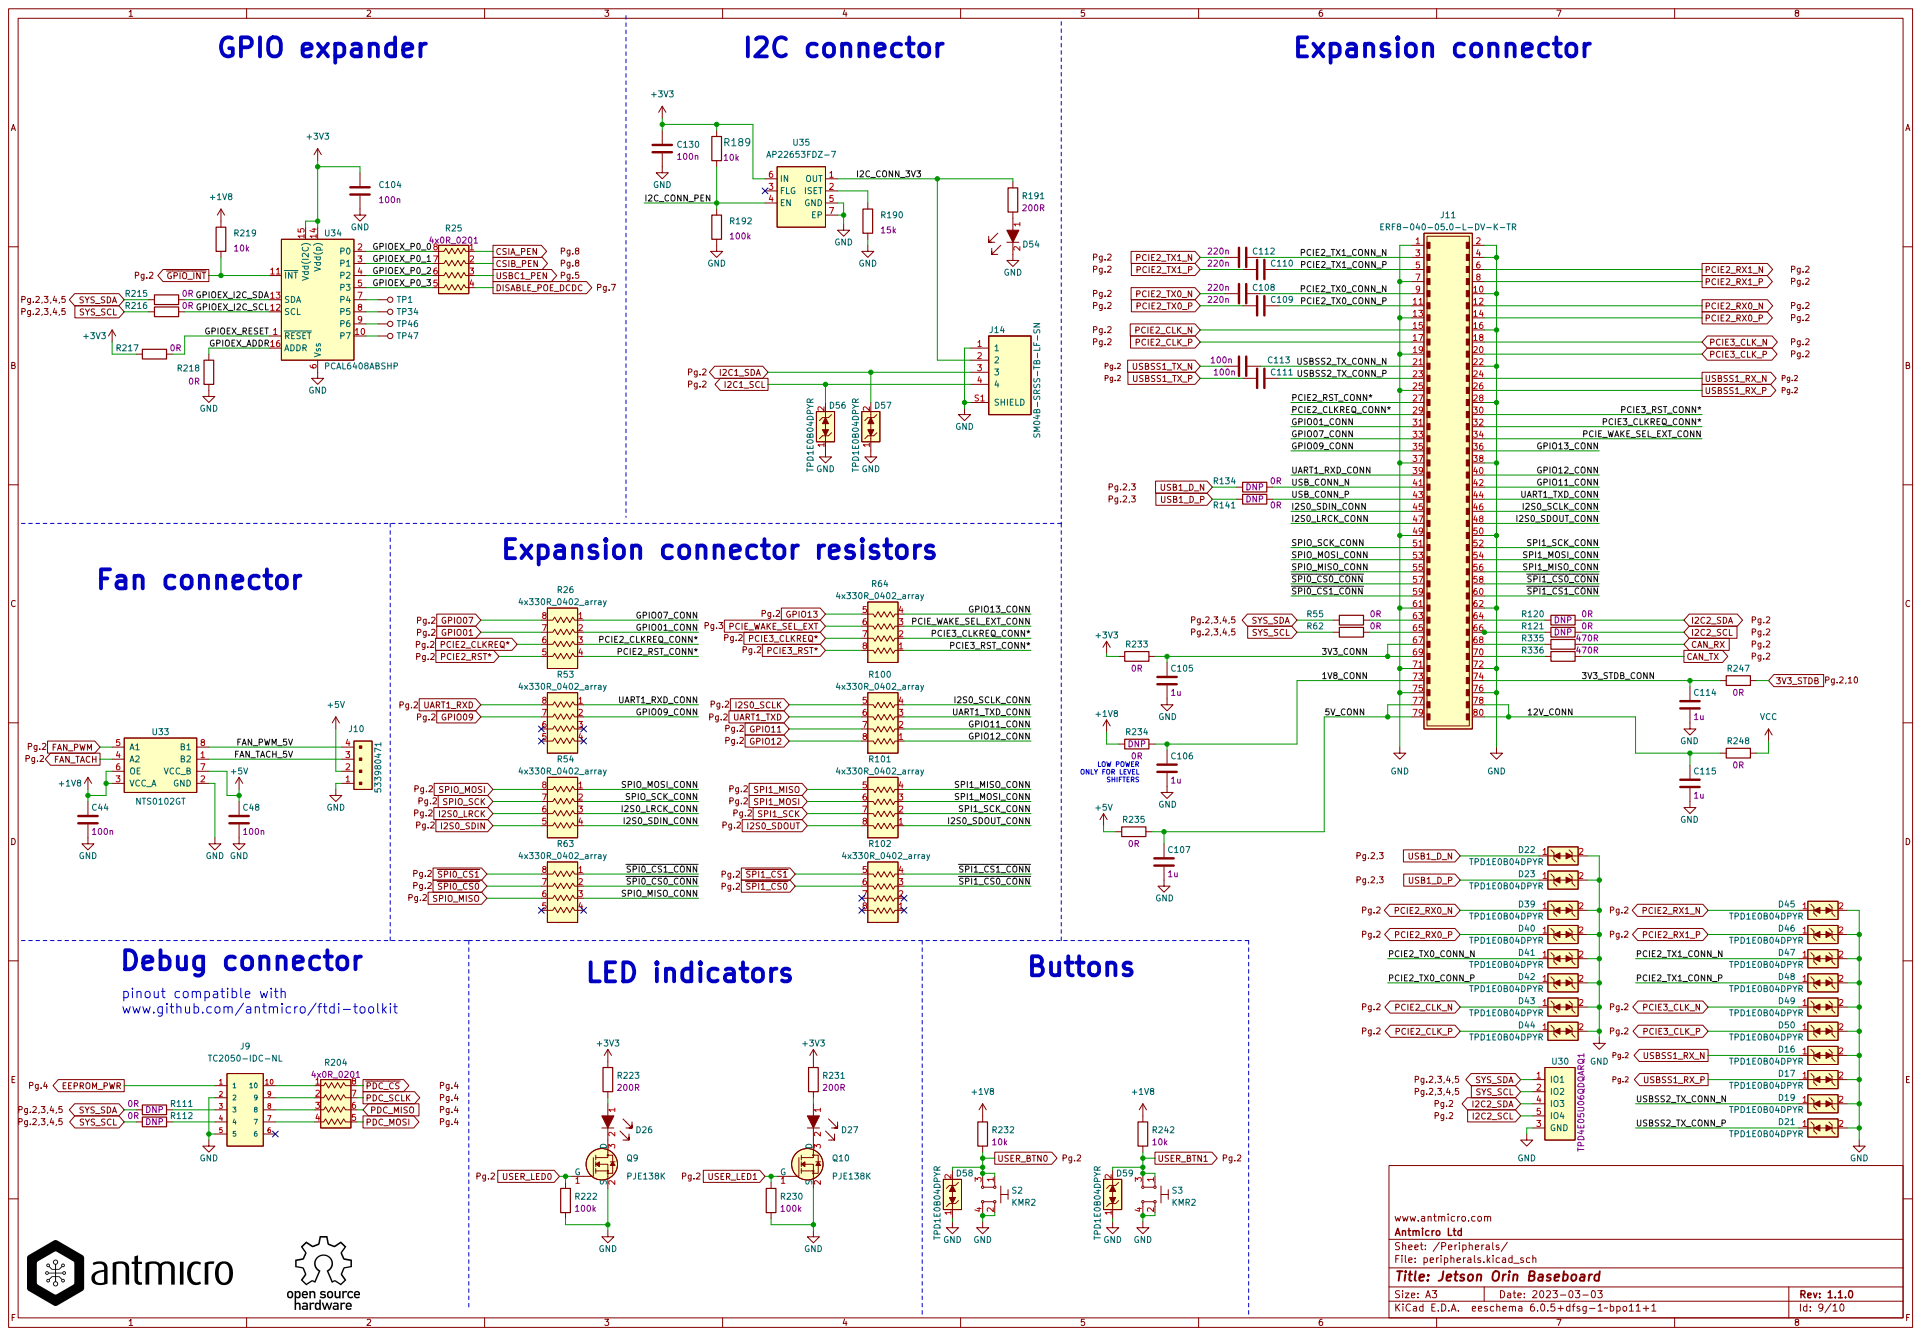
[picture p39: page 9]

LOW POWER ONLY FOR LEVEL SHIFTERS Fan connector

Pg.2 PCIE3_CLKREQ* Pg.2 GPIO13 Pg.2 PCIE3_RST* Pg.3 PCIE_WAKE_SEL_EXT Pg.2 GPIO11 Pg.2 UART1_TXD

pinout compatible with
www.github.com/antmicro/ftdi-toolkit

Sheet: /Peripherals/ Antmicro Ltd www.antmicro.com

File: peripherals.kicad_sch
Id: 9/10 Title: Jetson Orin Baseboard

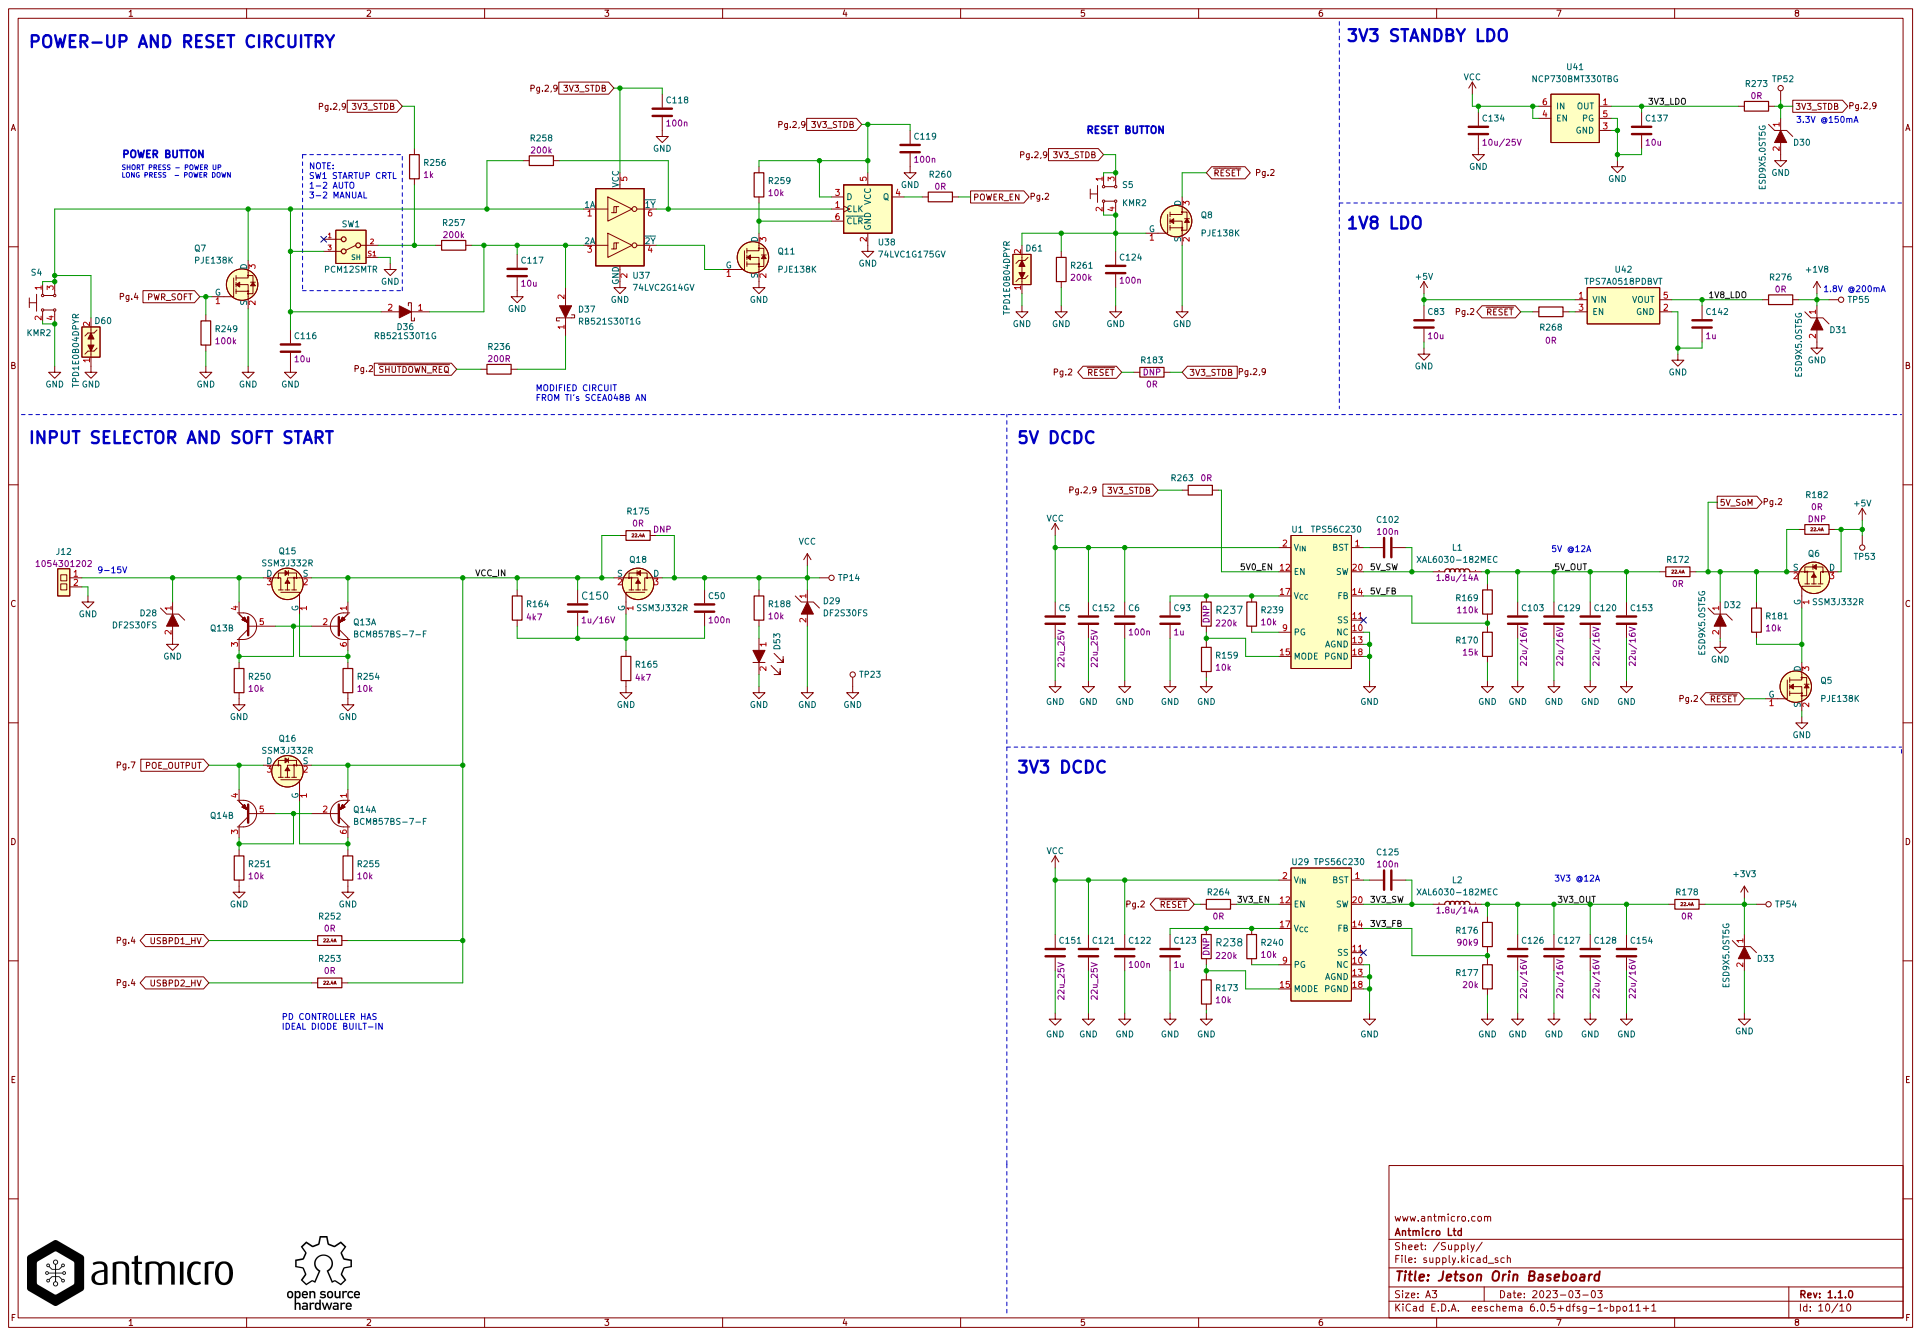
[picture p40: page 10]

POWER BUTTON POWER-UP AND RESET CIRCUITRY

SHORT PRESS - POWER UP
LONG PRESS - POWER DOWN

MODIFIED CIRCUIT FROM TI's SCEA048B AN

INPUT SELECTOR AND SOFT START

PD CONTROLLER HAS
IDEAL DIODE BUILT-IN

Sheet: /Supply/ Antmicro Ltd www.antmicro.com

File: supply.kicad_sch
Id: 10/10 Title: Jetson Orin Baseboard

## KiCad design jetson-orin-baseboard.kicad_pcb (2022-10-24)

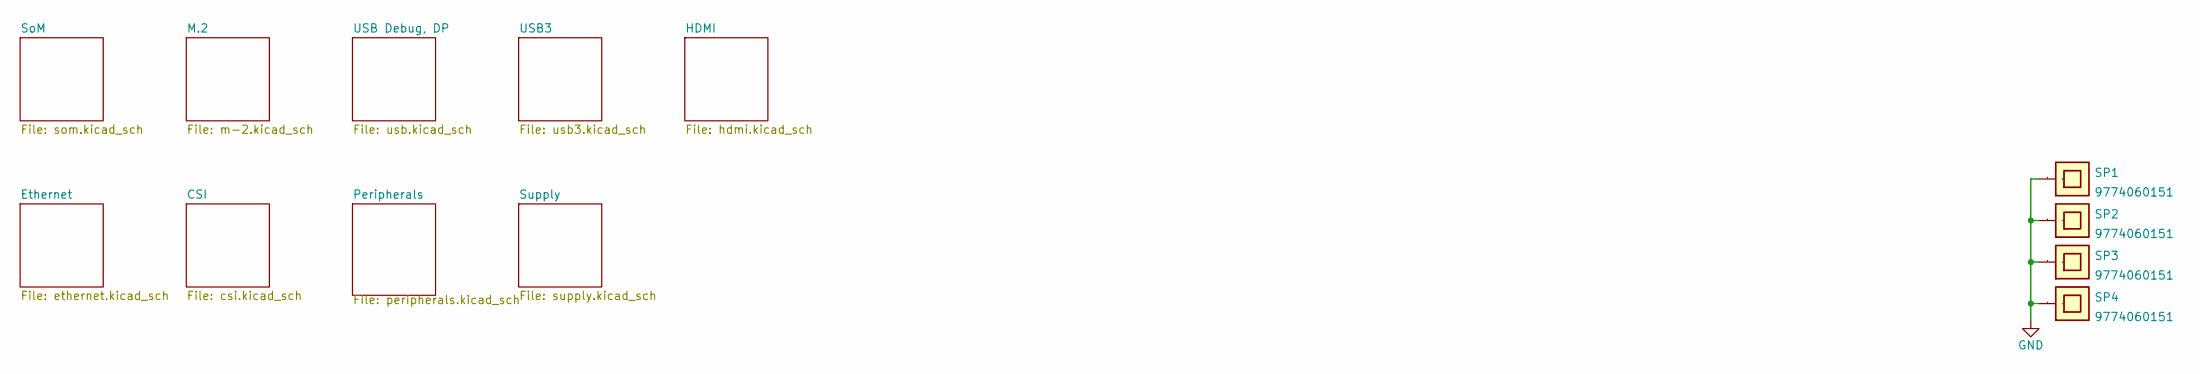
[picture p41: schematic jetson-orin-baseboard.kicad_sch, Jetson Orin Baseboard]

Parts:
SP1, SP2, SP3, SP4: 9774060151; MPN 9774060151

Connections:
GND: SP1.1, SP2.1, SP3.1, SP4.1; also elsewhere on the board

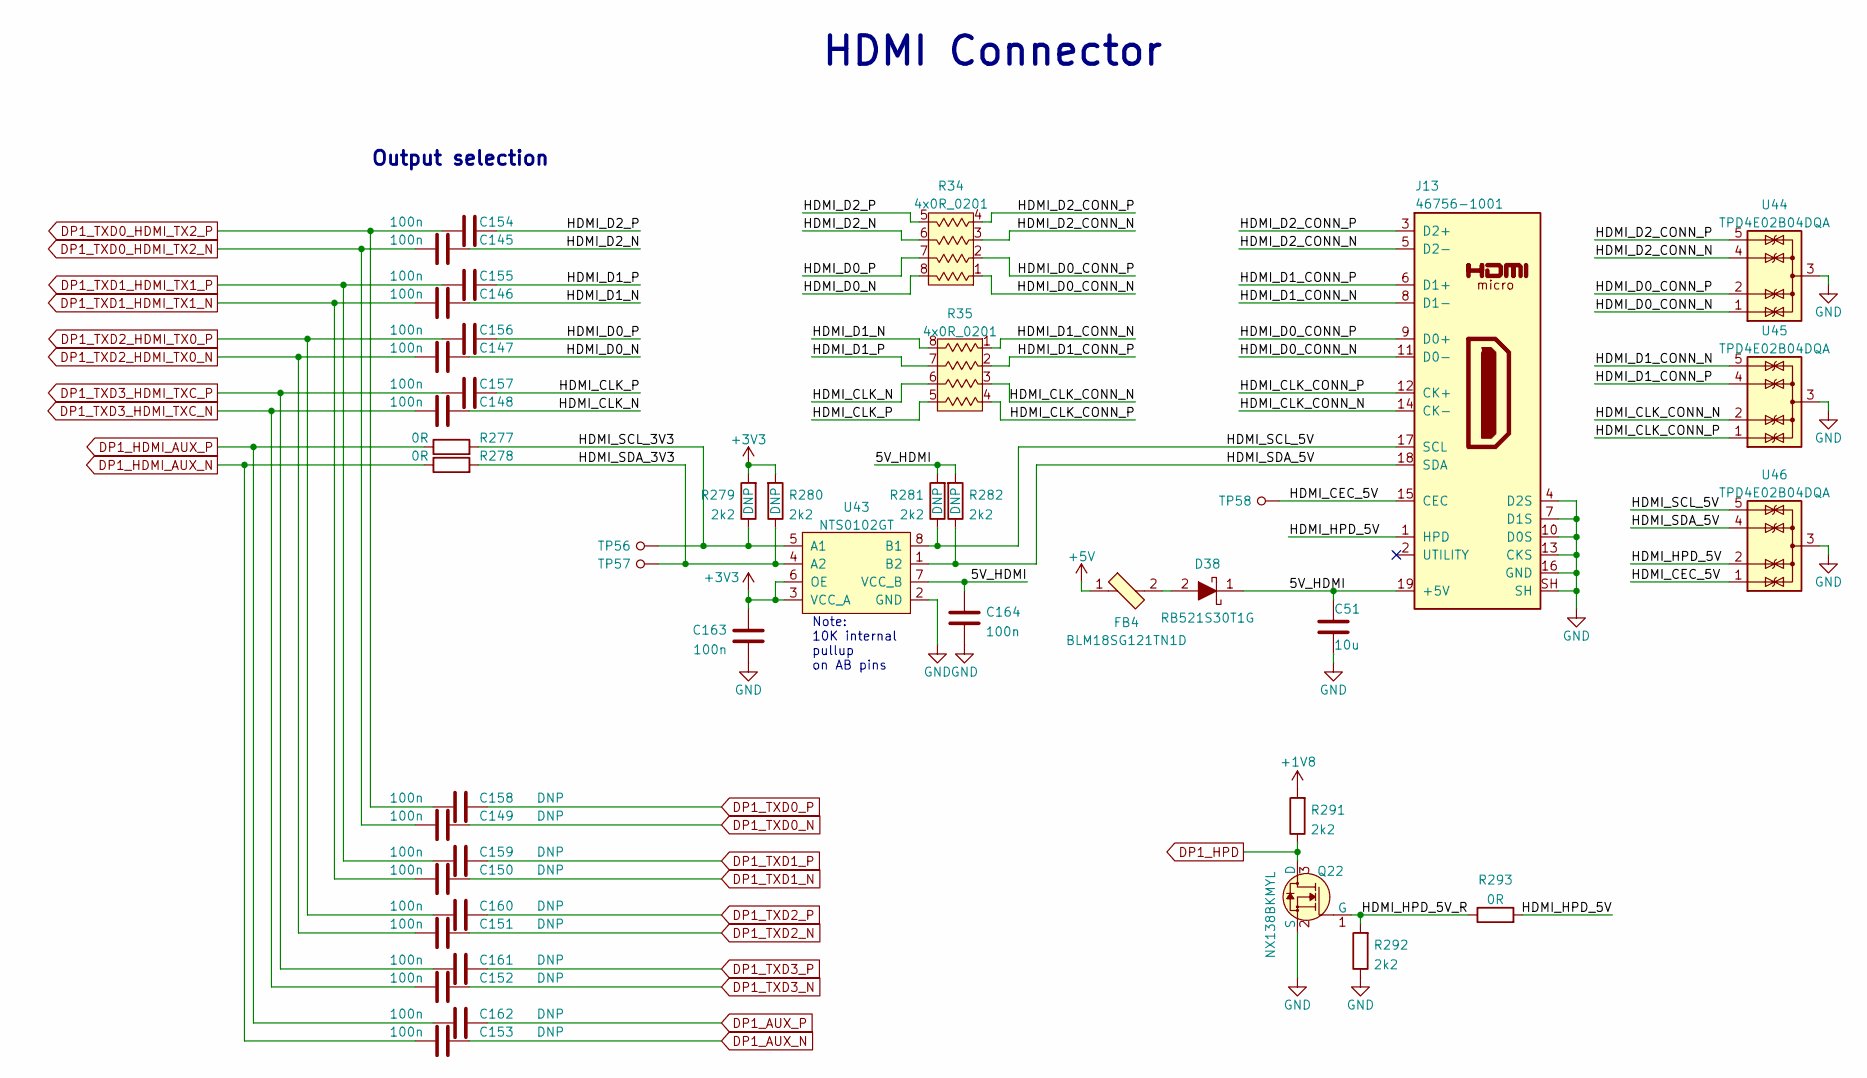
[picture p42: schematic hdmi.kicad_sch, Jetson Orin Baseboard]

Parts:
C51: C_10u_0603; 0603-cap; MPN GRM188R61A106KE69D
C145, C146, C147, C148, C149, C150, C151, C152, C153, C154, C155, C156, C157, C158, C159, C160, C161, C162, C163, C164: C_100n_0402; 0402-cap; MPN GRM155R61H104KE14D
D38: RB521S30T1G; SOD-523; MPN RB521S30T1G
FB4: BLM18SG121TN1D; 0603-res; MPN BLM18SG121TN1D
J13: 46756-1001; HDMI_Micro-D_Molex_46765-1x01; MPN 467651001
Q22: NX138BKMYL; DFN1006-3; MPN NX138BKMYL
R34, R35: 4x0R_0201_array; EXB18V; MPN EXB-18VR000X
R277, R278, R293: R_0R_0402; 0402-res; MPN ERJ2GE0R00X
R279, R280, R281, R282, R291, R292: R_2k2_0402; 0402-res; MPN RC0402FR-072K2L
TP56, TP57, TP58: TP_SMD_0_75MM; Testpoint_smd_0_75mm
U43: NTS0102GT; PSON50P100X195X50-8N; MPN NTS0102GT
U44, U45, U46: TPD4E02B04DQA; USON-10_2.5x1.0mm_P0.5mm; MPN TPD4E02B04DQAR

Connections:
+1V8: R291.2; also elsewhere on the board
+3V3: C163.2, R279.2, R280.2, U43.3 (VCC_A), U43.6 (OE); also elsewhere on the board
+5V: FB4.1; also elsewhere on the board
/HDMI/5V_HDMI: C51.1, C164.2, D38.1, J13.19 (+5V), R281.2, R282.2, U43.7 (VCC_B)
/HDMI/HDMI_CEC_5V: J13.15 (CEC), TP58.1, U46.1 (IO1), U46.10 (NC)
/HDMI/HDMI_CLK_CONN_N: J13.14 (CK-), R35.3, U45.2 (IO2), U45.9 (NC)
/HDMI/HDMI_CLK_CONN_P: J13.12 (CK+), R35.4, U45.1 (IO1), U45.10 (NC)
/HDMI/HDMI_CLK_N: C148.1, R35.6
/HDMI/HDMI_CLK_P: C157.1, R35.5
/HDMI/HDMI_D0_CONN_N: J13.11 (D0-), R34.1, U44.1 (IO1), U44.10 (NC)
/HDMI/HDMI_D0_CONN_P: J13.9 (D0+), R34.2, U44.2 (IO2), U44.9 (NC)
/HDMI/HDMI_D0_N: C147.1, R34.8
/HDMI/HDMI_D0_P: C156.1, R34.7
/HDMI/HDMI_D1_CONN_N: J13.8 (D1-), R35.1, U45.5 (IO4), U45.6 (NC)
/HDMI/HDMI_D1_CONN_P: J13.6 (D1+), R35.2, U45.4 (IO3), U45.7 (NC)
/HDMI/HDMI_D1_N: C146.1, R35.8
/HDMI/HDMI_D1_P: C155.1, R35.7
/HDMI/HDMI_D2_CONN_N: J13.5 (D2-), R34.3, U44.4 (IO3), U44.7 (NC)
/HDMI/HDMI_D2_CONN_P: J13.3 (D2+), R34.4, U44.5 (IO4), U44.6 (NC)
/HDMI/HDMI_D2_N: C145.1, R34.6
/HDMI/HDMI_D2_P: C154.1, R34.5
/HDMI/HDMI_HPD_5V: J13.1 (HPD), R293.2, U46.2 (IO2), U46.9 (NC)
/HDMI/HDMI_HPD_5V_R: Q22.1 (G), R292.2, R293.1
/HDMI/HDMI_SCL_3V3: R277.2, R279.1, TP56.1, U43.5 (A1)
/HDMI/HDMI_SCL_5V: J13.17 (SCL), R281.1, U43.8 (B1), U46.5 (IO4), U46.6 (NC)
/HDMI/HDMI_SDA_3V3: R278.2, R280.1, TP57.1, U43.4 (A2)
/HDMI/HDMI_SDA_5V: J13.18 (SDA), R282.1, U43.1 (B2), U46.4 (IO3), U46.7 (NC)
DP1_AUX_N: C153.1; also elsewhere on the board
DP1_AUX_P: C162.1; also elsewhere on the board
DP1_HDMI_AUX_N: C153.2, R278.1; also elsewhere on the board
DP1_HDMI_AUX_P: C162.2, R277.1; also elsewhere on the board
DP1_HPD: Q22.3 (D), R291.1; also elsewhere on the board
DP1_TXD0_HDMI_TX2_N: C145.2, C149.2; also elsewhere on the board
DP1_TXD0_HDMI_TX2_P: C154.2, C158.2; also elsewhere on the board
DP1_TXD0_N: C149.1; also elsewhere on the board
DP1_TXD0_P: C158.1; also elsewhere on the board
DP1_TXD1_HDMI_TX1_N: C146.2, C150.2; also elsewhere on the board
DP1_TXD1_HDMI_TX1_P: C155.2, C159.2; also elsewhere on the board
DP1_TXD1_N: C150.1; also elsewhere on the board
DP1_TXD1_P: C159.1; also elsewhere on the board
DP1_TXD2_HDMI_TX0_N: C147.2, C151.2; also elsewhere on the board
DP1_TXD2_HDMI_TX0_P: C156.2, C160.2; also elsewhere on the board
DP1_TXD2_N: C151.1; also elsewhere on the board
DP1_TXD2_P: C160.1; also elsewhere on the board
DP1_TXD3_HDMI_TXC_N: C148.2, C152.2; also elsewhere on the board
DP1_TXD3_HDMI_TXC_P: C157.2, C161.2; also elsewhere on the board
DP1_TXD3_N: C152.1; also elsewhere on the board
DP1_TXD3_P: C161.1; also elsewhere on the board
GND: C51.2, C163.1, C164.1, J13.4 (D2S), J13.7 (D1S), J13.10 (D0S), J13.13 (CKS), J13.16 (GND), J13.SH, Q22.2 (S), R292.1, U43.2 (GND), U44.3 (G), U44.8 (G), U45.3 (G), U45.8 (G), U46.3 (G), U46.8 (G); also elsewhere on the board
unnamed: D38.2, FB4.2

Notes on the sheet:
Output selection
Note: 10K internal pullup on AB pins
HDMI Connector

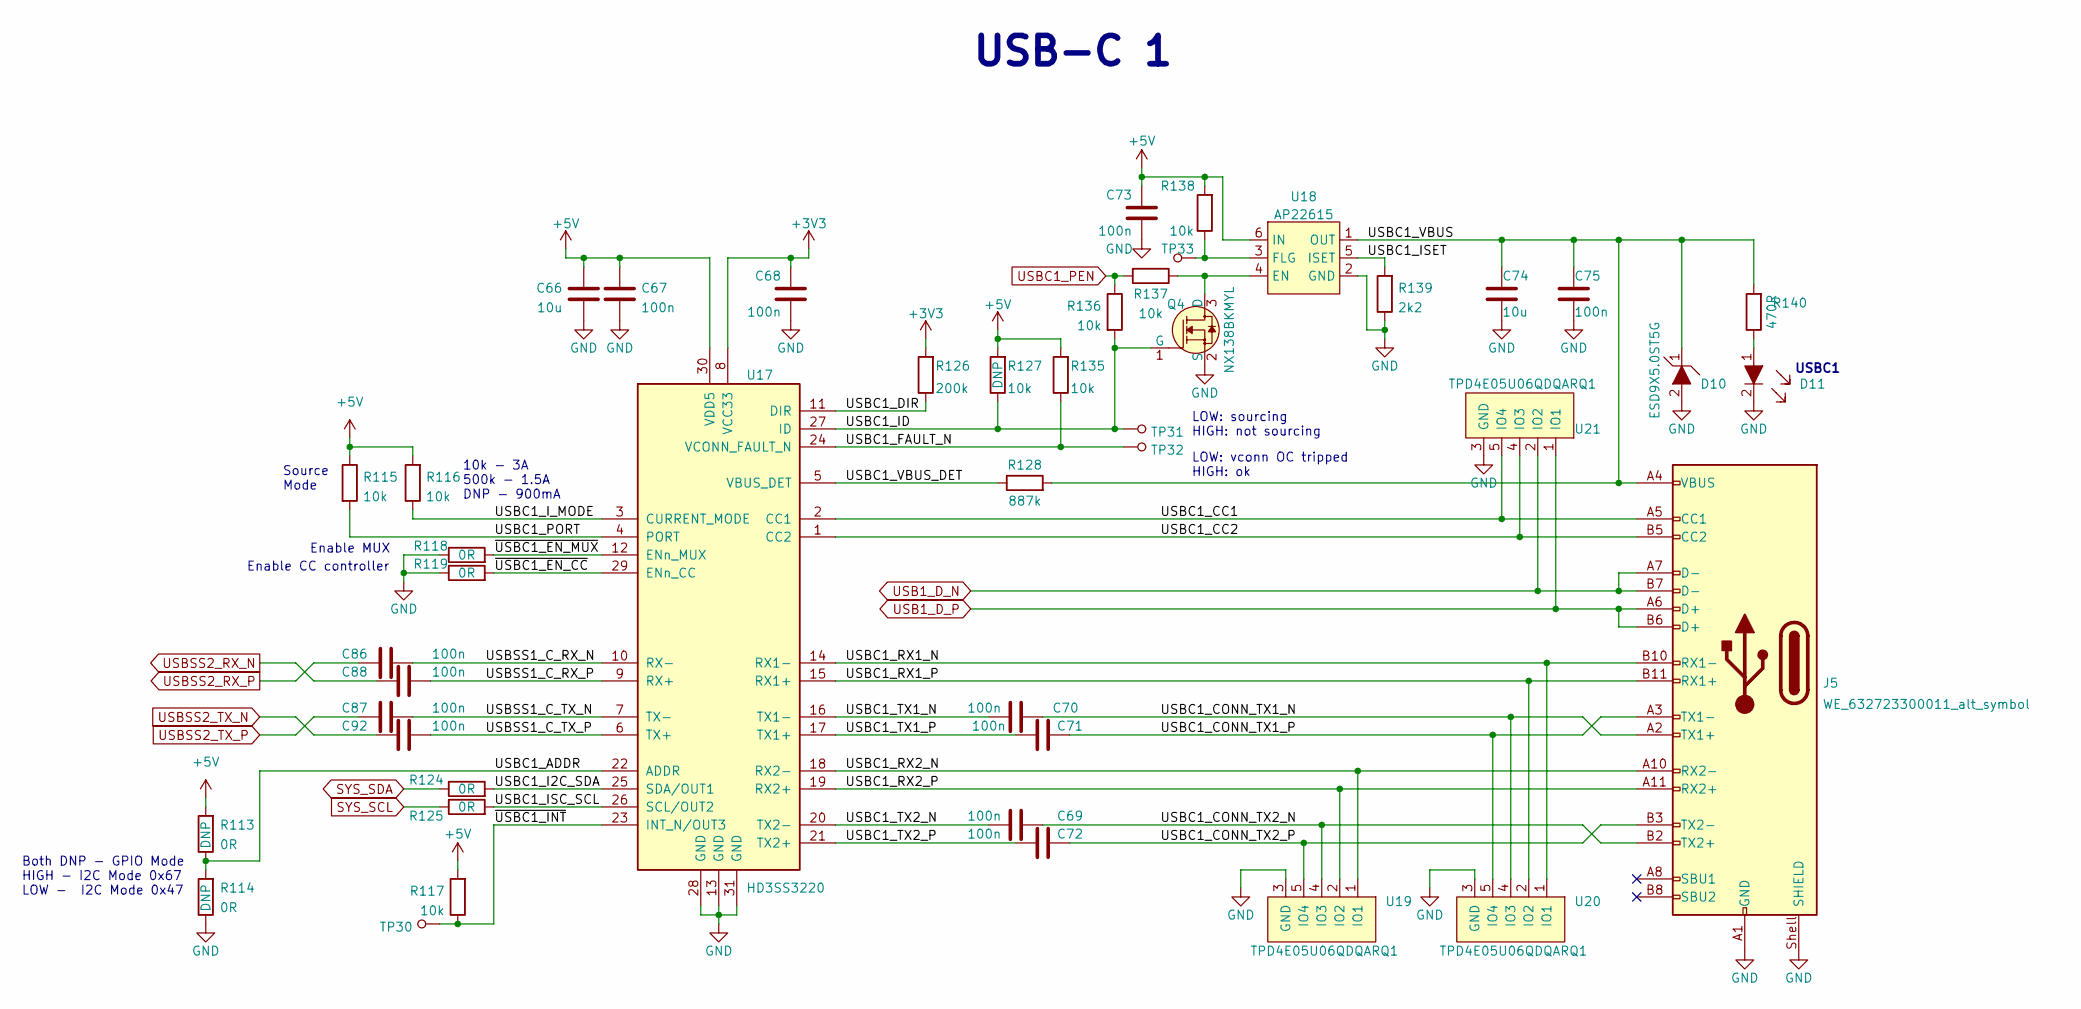
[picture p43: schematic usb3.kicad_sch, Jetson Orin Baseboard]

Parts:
C66, C74: C_10u_0603; 0603-cap; MPN GRM188R61A106KE69D
C67, C68, C69, C70, C71, C72, C73, C75, C86, C87, C88, C92: C_100n_0402; 0402-cap; MPN GRM155R61H104KE14D
D10: ESD9X5.0ST5G; SOD-923; MPN ESD9X5.0ST5G
D11: LTST-C190GKT; LED_0603; MPN LTST-C190GKT
J5: WE_632723300011_alt_symbol; WE_632723300011; MPN 632723300011
Q4: NX138BKMYL; DFN1006-3; MPN NX138BKMYL
R113, R114, R118, R119, R124, R125: R_0R_0402; 0402-res; MPN ERJ2GE0R00X
R115, R116, R117, R127, R135, R136, R137, R138: R_10k_0402; 0402-res; MPN CRCW040210K0FKEDHP
R126: R_200k_0402; 0402-res; MPN RC0402FR-07200KL
R128: R_887k_0402; 0402-res; MPN MCWR04X8870FTL
R139: R_2k2_0402; 0402-res; MPN RC0402FR-072K2L
R140: R_470R_0402; 0402-res; MPN CRCW0402470RFKED
TP30, TP31, TP32, TP33: TP_SMD_0_75MM; Testpoint_smd_0_75mm
U17: HD3SS3220; RNH0030A; MPN HD3SS3220RNHT
U18: AP22615; TSOT23-6; MPN AP22615AWU-7
U19, U20, U21: TPD4E05U06QDQARQ1; USON-10_2.5x1.0mm_P0.5mm; MPN TPD4E05U06QDQARQ1

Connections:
+3V3: C68.1, R126.2, U17.8 (VCC33); also elsewhere on the board
+5V: C66.1, C67.1, C73.1, R113.2, R115.1, R116.2, R117.2, R127.2, R135.2, R138.2, U17.30 (VDD5), U18.6 (IN); also elsewhere on the board
/USB3/USBC1_ADDR: R113.1, R114.2, U17.22 (ADDR)
/USB3/USBC1_CC1: J5.A5 (CC1), U17.2 (CC1), U21.5 (IO4), U21.6 (IO4)
/USB3/USBC1_CC2: J5.B5 (CC2), U17.1 (CC2), U21.4 (IO3), U21.7 (IO3)
/USB3/USBC1_CONN_TX1_N: C70.2, J5.A2 (TX1+), U20.4 (IO3), U20.7 (IO3)
/USB3/USBC1_CONN_TX1_P: C71.2, J5.A3 (TX1-), U20.5 (IO4), U20.6 (IO4)
/USB3/USBC1_CONN_TX2_N: C69.2, J5.B2 (TX2+), U19.4 (IO3), U19.7 (IO3)
/USB3/USBC1_CONN_TX2_P: C72.2, J5.B3 (TX2-), U19.5 (IO4), U19.6 (IO4)
/USB3/USBC1_DIR: R126.1, U17.11 (DIR)
/USB3/USBC1_FAULT_N: R135.1, TP32.1, U17.24 (VCONN_FAULT_N)
/USB3/USBC1_I2C_SDA: R124.2, U17.25 (SDA/OUT1)
/USB3/USBC1_ID: Q4.1 (G), R127.1, R136.2, TP31.1, U17.27 (ID)
/USB3/USBC1_ISC_SCL: R125.2, U17.26 (SCL/OUT2)
/USB3/USBC1_ISET: R139.2, U18.5 (ISET)
/USB3/USBC1_I_MODE: R116.1, U17.3 (CURRENT_MODE)
/USB3/USBC1_PORT: R115.2, U17.4 (PORT)
/USB3/USBC1_RX1_N: J5.B10 (RX1-), U17.14 (RX1-), U20.1 (IO1), U20.10 (IO1)
/USB3/USBC1_RX1_P: J5.B11 (RX1+), U17.15 (RX1+), U20.2 (IO2), U20.9 (IO2)
/USB3/USBC1_RX2_N: J5.A10 (RX2-), U17.18 (RX2-), U19.1 (IO1), U19.10 (IO1)
/USB3/USBC1_RX2_P: J5.A11 (RX2+), U17.19 (RX2+), U19.2 (IO2), U19.9 (IO2)
/USB3/USBC1_TX1_N: C70.1, U17.16 (TX1-)
/USB3/USBC1_TX1_P: C71.1, U17.17 (TX1+)
/USB3/USBC1_TX2_N: C69.1, U17.20 (TX2-)
/USB3/USBC1_TX2_P: C72.1, U17.21 (TX2+)
/USB3/USBC1_VBUS: C74.1, C75.1, D10.1, J5.A4 (VBUS), J5.A9 (VBUS), J5.B4 (VBUS), J5.B9 (VBUS), R128.2, R140.2, U18.1 (OUT)
/USB3/USBC1_VBUS_DET: R128.1, U17.5 (VBUS_DET)
/USB3/USBSS1_C_RX_N: C86.2, U17.10 (RX-)
/USB3/USBSS1_C_RX_P: C88.2, U17.9 (RX+)
/USB3/USBSS1_C_TX_N: C87.2, U17.7 (TX-)
/USB3/USBSS1_C_TX_P: C92.2, U17.6 (TX+)
/USB3/~USBC1_EN_CC: R119.2, U17.29 (ENn_CC)
/USB3/~USBC1_EN_MUX: R118.2, U17.12 (ENn_MUX)
/USB3/~USBC1_INT: R117.1, TP30.1, U17.23 (INT_N/OUT3)
GND: C66.2, C67.2, C68.2, C73.2, C74.2, C75.2, D10.2, D11.2, J5.A1 (GND), J5.A12 (GND), J5.B1 (GND), J5.B12 (GND), J5.Shell (SHIELD), Q4.2 (S), R114.1, R118.1, R119.1, R139.1, U17.13 (GND), U17.28 (GND), U17.31 (GND), U18.2 (GND), U19.3 (GND), U19.8 (GND), U20.3 (GND), U20.8 (GND), U21.3 (GND), U21.8 (GND); also elsewhere on the board
unnamed: D11.1, R140.1
unnamed: Q4.3 (D), R137.1, U18.4 (EN)
unnamed: R138.1, TP33.1, U18.3 (FLG)
SYS_SCL: R125.1; also elsewhere on the board
SYS_SDA: R124.1; also elsewhere on the board
USB1_D_N: J5.A7 (D-), J5.B7 (D-), U21.2 (IO2), U21.9 (IO2); also elsewhere on the board
USB1_D_P: J5.A6 (D+), J5.B6 (D+), U21.1 (IO1), U21.10 (IO1); also elsewhere on the board
USBC1_PEN: R136.1, R137.2; also elsewhere on the board
USBSS2_RX_N: C88.1; also elsewhere on the board
USBSS2_RX_P: C86.1; also elsewhere on the board
USBSS2_TX_N: C92.1; also elsewhere on the board
USBSS2_TX_P: C87.1; also elsewhere on the board

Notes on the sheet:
Source Mode
Enable MUX
Both DNP - GPIO Mode HIGH - I2C Mode 0x67 LOW - I2C Mode 0x47
USB-C 1
10k - 3A 500k - 1.5A DNP - 900mA
LOW: sourcing HIGH: not sourcing
USBC1
LOW: vconn OC tripped HIGH: ok
Enable CC controller

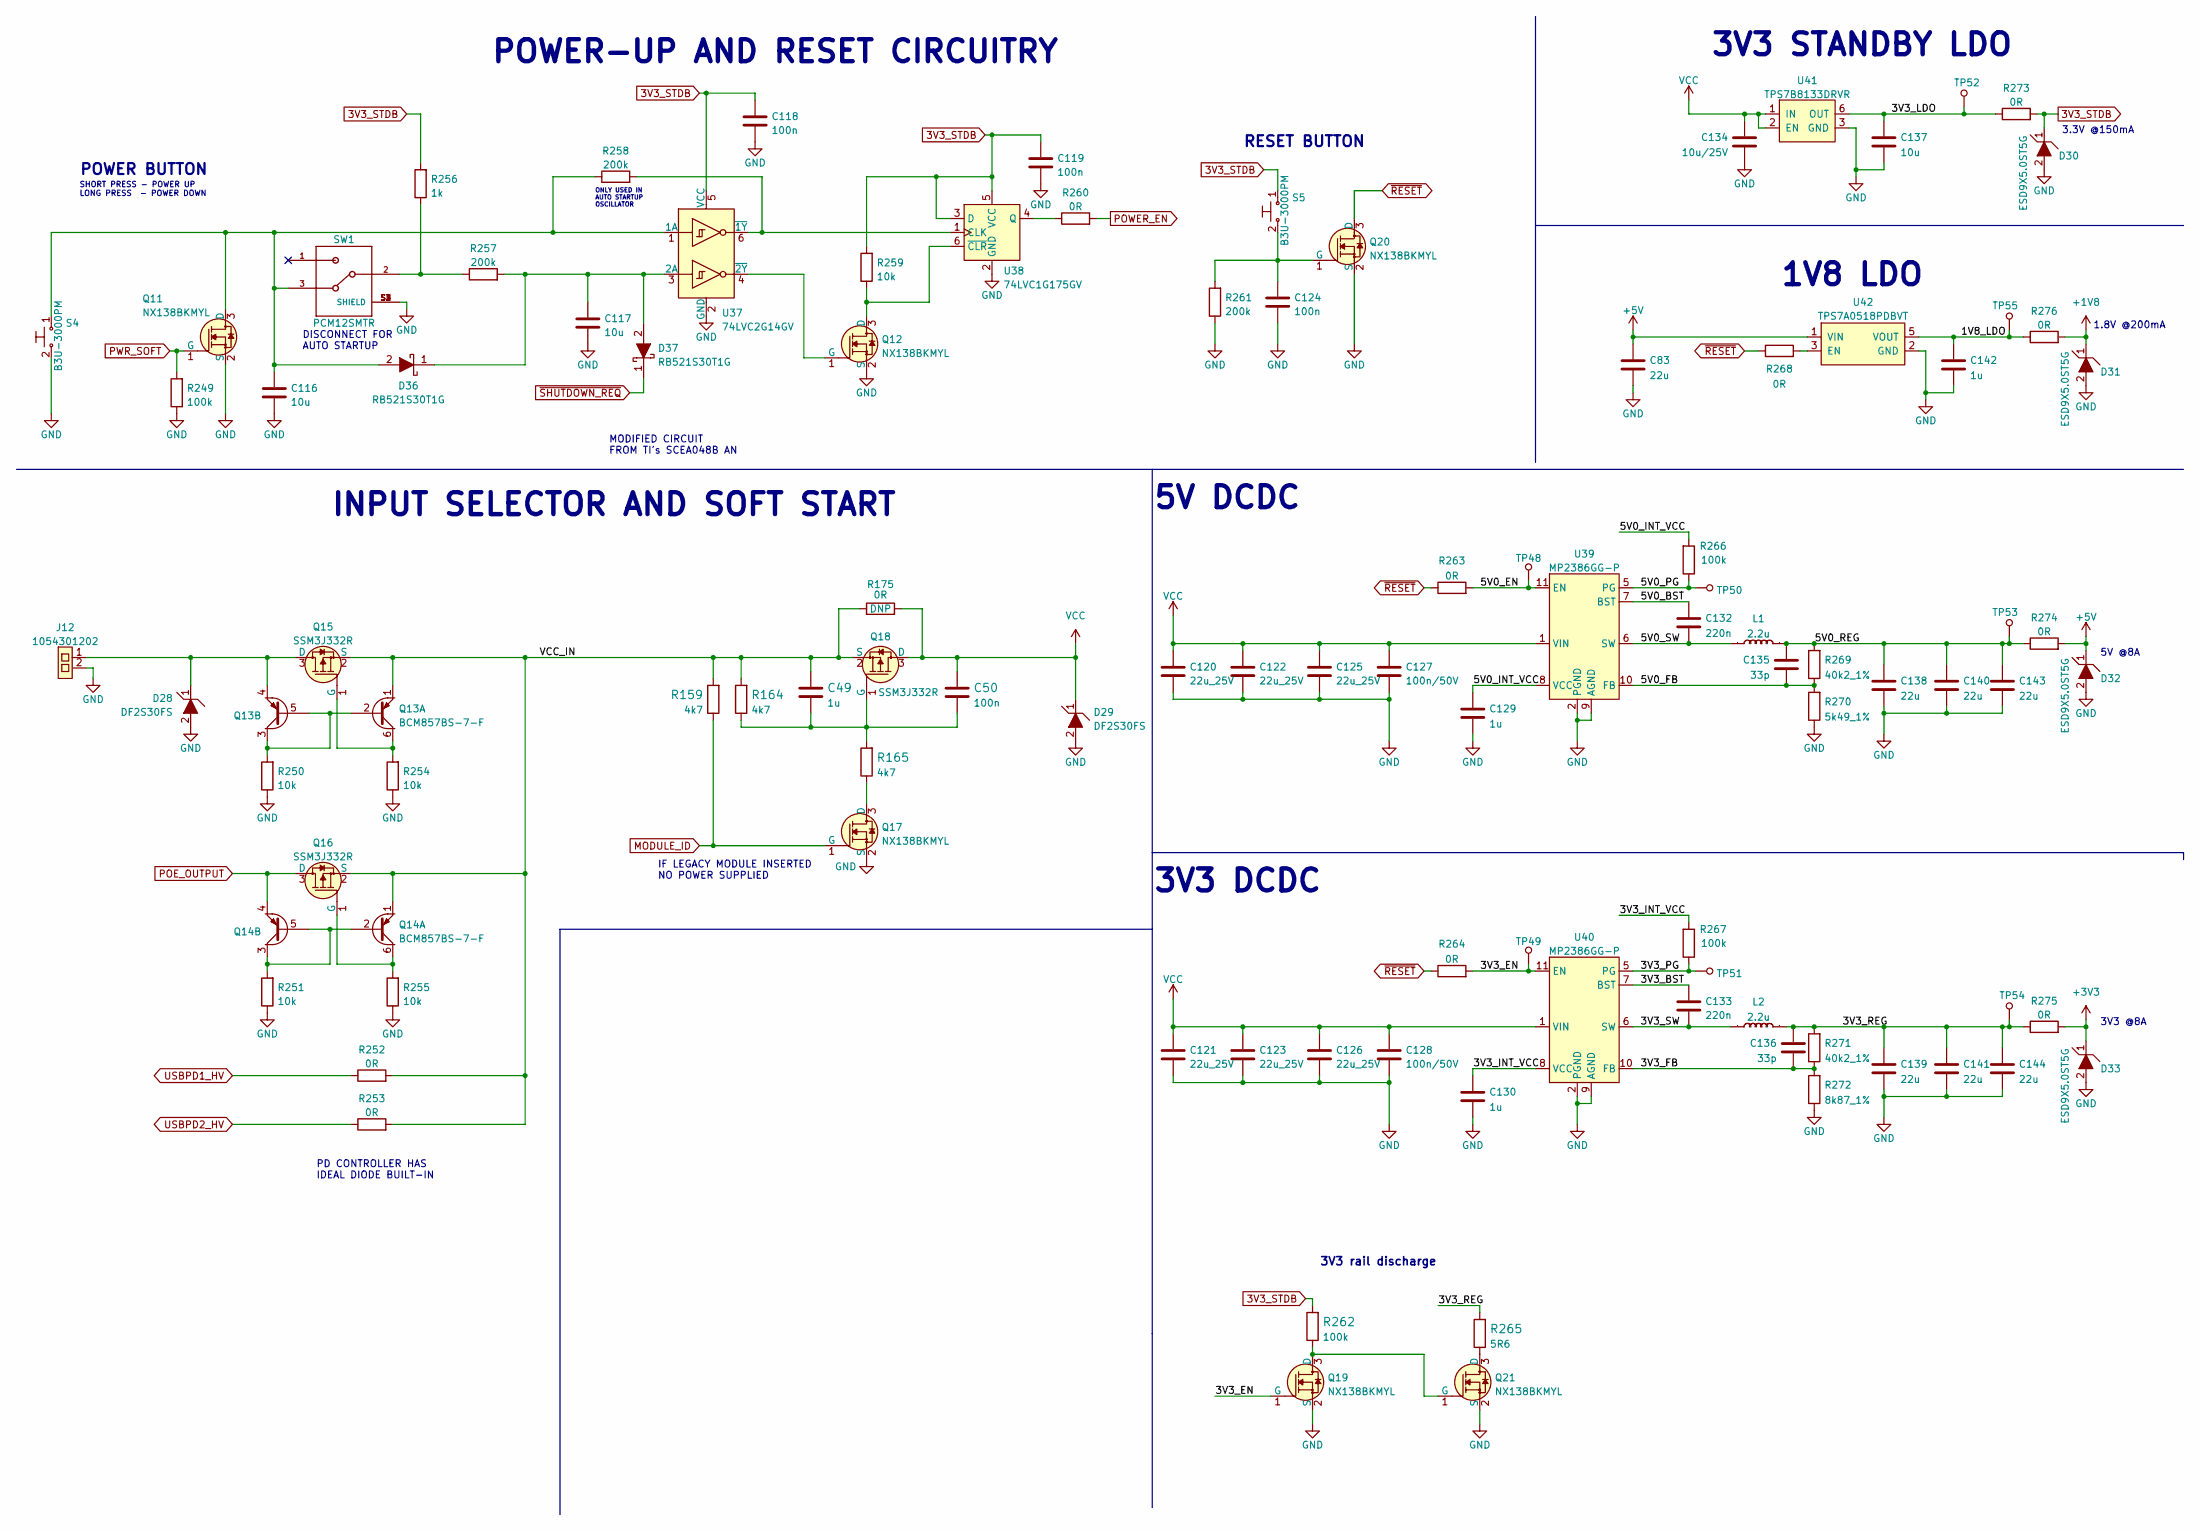
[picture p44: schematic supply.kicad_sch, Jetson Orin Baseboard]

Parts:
C49, C129, C130, C142: C_1u_0402; 0402-cap; MPN C1005X6S1A105K050BC
C50, C118, C119, C124: C_100n_0402; 0402-cap; MPN GRM155R61H104KE14D
C83, C138, C139, C140, C141, C143, C144: C_22u_0402; 0402-cap; MPN 04024W226MAT2A
C116, C117, C137: C_10u_0402; 0402-cap; MPN CC0402MRX5R5BB106
C120, C121, C122, C123, C125, C126: C_22u_0805_25V; 0805-cap; MPN CL21A226MAYNNNE
C127, C128: C_100n_0402_50V; 0402-cap; MPN GRM155R71H104KE14D
C132, C133: C_220n_0402; 0402-cap; MPN CC0402KRX5R6BB224
C134: C_10u_25V_0603; 0603-cap; MPN C1608X5R1E106M080AC
C135, C136: C_33p_0402; 0402-cap; MPN MC0402N330J500CT
D28, D29: DF2S30FS; SOD-923; MPN DF2S30FS
D30, D31, D32, D33: ESD9X5.0ST5G; SOD-923; MPN ESD9X5.0ST5G
D36, D37: RB521S30T1G; SOD-523; MPN RB521S30T1G
J12: Molex_Nano-Fit-105430_xx02-horizontal; Molex_Nano-Fit_105430-xx02_1x02_P2.50mm_Horizontal_SMD; MPN 1054301202
L1, L2: IHLP2525CZER2R2M01; IHLP2525CZER; MPN IHLP2525CZER8R2M01
Q11, Q12, Q17, Q19, Q20, Q21: NX138BKMYL; DFN1006-3; MPN NX138BKMYL
Q13, Q14: BCM857BS-7-F; SOT-363; MPN BCM857BS-7-F
Q15, Q16, Q18: SSM3J332R; SOT-23-3; MPN SSM3J332R,LF
R159, R164, R165: R_4k7_0402; 0402-res; MPN MCS04020C4701FE000
R175, R252, R253, R274, R275: R_0R_1206; 1206-res; MPN MCMR12X000_PTL
R249, R262, R266, R267: R_100k_0402; 0402-res; MPN CRCW0402100KFKEDHP
R250, R251, R254, R255, R259: R_10k_0402; 0402-res; MPN CRCW040210K0FKEDHP
R256: R_1k_0402; 0402-res; MPN CR0402-FX-1001GLF
R257, R258, R261: R_200k_0402; 0402-res; MPN RC0402FR-07200KL
R260, R263, R264, R268: R_0R_0402; 0402-res; MPN ERJ2GE0R00X
R265: R_5R6_0402; 0402-res; MPN ERJ2GEJ5R6X
R269, R271: R_40k2_1%_0402; 0402-res; MPN RC0402FR-0740K2L
R270: R_5k49_1%_0402; 0402-res; MPN ERJ-2RKF5491X
R272: R_8k87_1%_0402; 0402-res; MPN ERJ-2RKF8871X
R273, R276: R_0R_0603; 0603-res; MPN CR0603-J/-000ELF
S4, S5: B3U-3000PM; B3U-3000P; MPN B3U-3000PM
SW1: PCM12SMTR; MPN PCM13SMTR
TP48, TP49, TP50, TP51, TP52, TP53, TP54, TP55: TP_SMD_0_75MM; Testpoint_smd_0_75mm
U37: 74LVC2G14GV; SOT23-6L; MPN 74LVC2G14GV,125
U38: 74LVC1G175GV; SOT-23-6; MPN 74LVC1G175GV,125
U39, U40: MP2386GG-P; QFN-11_2x2mm_P0.5mm; MPN MP2386GG-P
U41: TPS7B8133DRVR; WSON6_TI_2x2mm; MPN TPS7B8133DRVR
U42: TPS7A0518PDBVT; SOT-23-5; MPN TPS7A0518PDBVT

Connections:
3V3_STDB: C118.1, C119.1, D30.1, R256.2, R259.2, R262.2, R273.2, S5.1, U37.5 (VCC), U38.3 (D), U38.5 (VCC); also elsewhere on the board
+1V8: D31.1, R276.2; also elsewhere on the board
+3V3: D33.1, R275.2; also elsewhere on the board
+5V: C83.1, D32.1, R274.2, U42.1 (VIN); also elsewhere on the board
/Supply/1V8_LDO: C142.1, R276.1, TP55.1, U42.5 (VOUT)
/Supply/3V3_BST: C133.1, U40.7 (BST)
/Supply/3V3_EN: Q19.1 (G), R264.2, TP49.1, U40.11 (EN)
/Supply/3V3_FB: C136.2, R271.1, R272.2, U40.10 (FB)
/Supply/3V3_INT_VCC: C130.1, R267.2, U40.8 (VCC)
/Supply/3V3_LDO: C137.1, R273.1, TP52.1, U41.6 (OUT)
/Supply/3V3_PG: R267.1, TP51.1, U40.5 (PG)
/Supply/3V3_REG: C136.1, C139.1, C141.1, C144.1, L2.2, R265.2, R271.2, R275.1, TP54.1
/Supply/3V3_SW: C133.2, L2.1, U40.6 (SW)
/Supply/5V0_BST: C132.2, U39.7 (BST)
/Supply/5V0_EN: R263.2, TP48.1, U39.11 (EN)
/Supply/5V0_FB: C135.2, R269.1, R270.2, U39.10 (FB)
/Supply/5V0_INT_VCC: C129.1, R266.2, U39.8 (VCC)
/Supply/5V0_PG: R266.1, TP50.1, U39.5 (PG)
/Supply/5V0_REG: C135.1, C138.1, C140.1, C143.1, L1.2, R269.2, R274.1, TP53.1
/Supply/5V0_SW: C132.1, L1.1, U39.6 (SW)
/Supply/VCC_IN: C49.1, Q13.1, Q14.1, Q15.2 (S), Q16.2 (S), Q18.2 (S), R159.2, R164.2, R175.1, R252.2, R253.2
GND: C83.2, C116.2, C117.2, C118.2, C119.2, C120.2, C121.2, C122.2, C123.2, C124.2, C125.2, C126.2, C127.2, C128.2, C129.2, C130.2, C134.2, C137.2, C138.2, C139.2, C140.2, C141.2, C142.2, C143.2, C144.2, D28.2, D29.2, D30.2, D31.2, D32.2, D33.2, J12.2, Q11.2 (S), Q12.2 (S), Q17.2 (S), Q19.2 (S), Q20.2 (S), Q21.2 (S), R249.1, R250.1, R251.1, R254.1, R255.1, R261.1, R270.1, R272.1, S4.2, SW1.S1 (SHIELD), SW1.S2 (SHIELD), SW1.S3 (SHIELD), SW1.S4 (SHIELD), U37.2 (GND), U38.2 (GND), U39.2 (PGND), U39.3 (PGND), U39.4 (PGND), U39.9 (AGND), U40.2 (PGND), U40.3 (PGND), U40.4 (PGND), U40.9 (AGND), U41.3 (GND), U41.4 (GND), U41.7 (GND), U42.2 (GND); also elsewhere on the board
MODULE_ID: Q17.1 (G), R159.1; also elsewhere on the board
unnamed: C49.2, C50.2, Q18.1 (G), R164.1, R165.2
unnamed: C116.1, D36.2, Q11.3 (D), R258.1, S4.1, SW1.3, U37.1 (1A)
unnamed: C117.1, D36.1, D37.2, R257.2, U37.3 (2A)
unnamed: C124.1, Q20.1 (G), R261.2, S5.2
unnamed: D28.1, J12.1, Q13.4, Q15.3 (D)
unnamed: Q12.1 (G), U37.4 (~2Y)
unnamed: Q12.3 (D), R259.1, U38.6 (~CLR)
unnamed: Q13.2, Q13.3, Q13.5, R250.2
unnamed: Q13.6, Q15.1 (G), R254.2
unnamed: Q14.2, Q14.3, Q14.5, R251.2
unnamed: Q14.6, Q16.1 (G), R255.2
unnamed: Q17.3 (D), R165.1
unnamed: Q19.3 (D), Q21.1 (G), R262.1
unnamed: Q21.3 (D), R265.1
unnamed: R256.1, R257.1, SW1.2
unnamed: R258.2, U37.6 (~1Y), U38.1 (CLK)
unnamed: R260.1, U38.4 (Q)
unnamed: R268.2, U42.3 (EN)
POE_OUTPUT: Q14.4, Q16.3 (D); also elsewhere on the board
POWER_EN: R260.2; also elsewhere on the board
PWR_SOFT: Q11.1 (G), R249.2; also elsewhere on the board
USBPD1_HV: R252.1; also elsewhere on the board
USBPD2_HV: R253.1; also elsewhere on the board
VCC: C50.1, C120.1, C121.1, C122.1, C123.1, C125.1, C126.1, C127.1, C128.1, C134.1, D29.1, Q18.3 (D), R175.2, U39.1 (VIN), U40.1 (VIN), U41.1 (IN), U41.2 (EN); also elsewhere on the board
~RESET: Q20.3 (D), R263.1, R264.1, R268.1; also elsewhere on the board
~SHUTDOWN_REQ: D37.1; also elsewhere on the board

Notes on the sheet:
ONLY USED IN AUTO STARTUP OSCILLATOR
5V @8A
3V3 STANDBY LDO
3.3V @150mA
MODIFIED CIRCUIT FROM TI's SCEA048B AN
1V8 LDO
SHORT PRESS - POWER UP LONG PRESS - POWER DOWN
5V DCDC
DISCONNECT FOR AUTO STARTUP
POWER BUTTON
POWER-UP AND RESET CIRCUITRY
3V3 @8A
3V3 DCDC
PD CONTROLLER HAS IDEAL DIODE BUILT-IN
INPUT SELECTOR AND SOFT START
IF LEGACY MODULE INSERTED NO POWER SUPPLIED
1.8V @200mA
3V3 rail discharge
RESET BUTTON

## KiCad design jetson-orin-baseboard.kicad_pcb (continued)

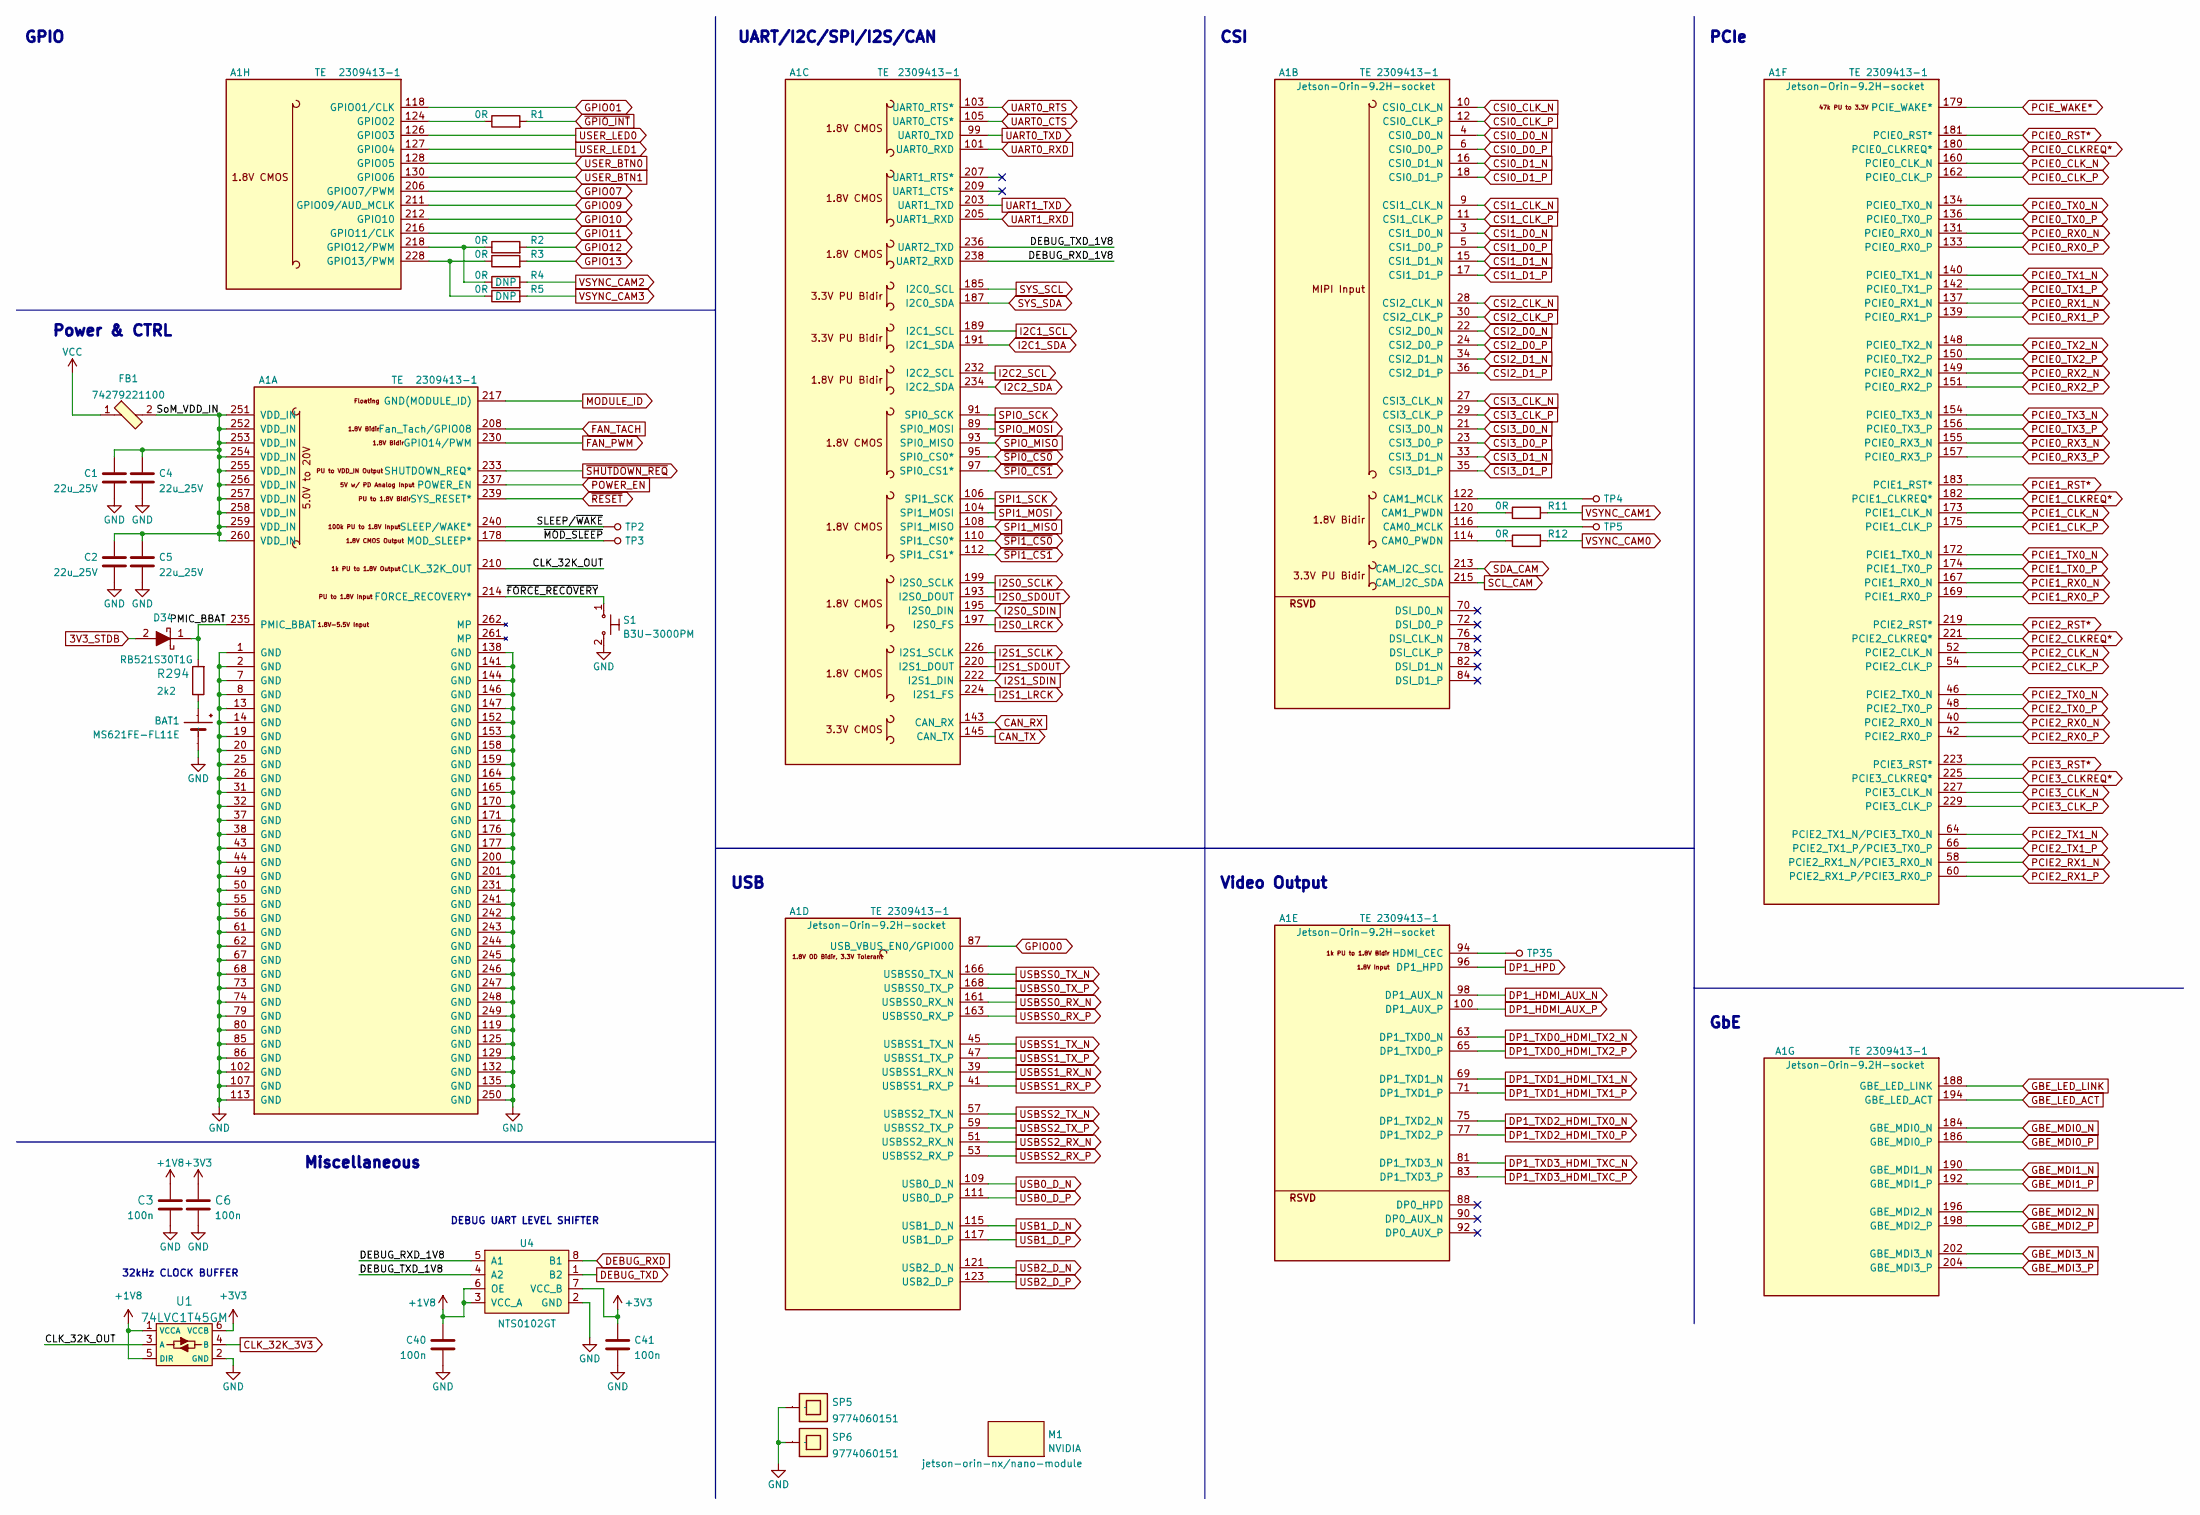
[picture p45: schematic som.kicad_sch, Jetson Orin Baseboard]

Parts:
A1: Jetson-Orin-9.2H-socket; TE_2309413; MPN 2309413-1
BAT1: MS621FE-FL11E; MPN MS621FE-FL11E
C1, C2, C4, C5: C_22u_0805_25V; 0805-cap; MPN CL21A226MAYNNNE
C3, C6, C40, C41: C_100n_0402; 0402-cap; MPN GRM155R61H104KE14D
D34: RB521S30T1G; SOD-523; MPN RB521S30T1G
FB1: 74279221100; 1206-res; MPN 74279221100
M1: jetson-orin-nx/nano-module; jetson-orin-nx-nano-module
R1, R2, R3, R4, R5, R11, R12: R_0R_0402; 0402-res; MPN ERJ2GE0R00X
R294: R_2k2_0402; 0402-res; MPN RC0402FR-072K2L
S1: B3U-3000PM; B3U-3000P; MPN B3U-3000PM
SP5, SP6: 9774060151; MPN 9774060151
TP2, TP3, TP4, TP5, TP35: TP_SMD_0_75MM; Testpoint_smd_0_75mm
U1: 74LVC1T45GM; SOT-886; MPN 74LVC1T45GM-Q100X
U4: NTS0102GT; PSON50P100X195X50-8N; MPN NTS0102GT

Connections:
3V3_STDB: D34.2; also elsewhere on the board
+1V8: C3.1, C40.2, U1.1 (VCCA), U1.5 (DIR), U4.3 (VCC_A), U4.6 (OE); also elsewhere on the board
+3V3: C6.1, C41.2, U1.6 (VCCB), U4.7 (VCC_B); also elsewhere on the board
/SoM/CLK_32K_OUT: A1.210 (CLK_32K_OUT), U1.3 (A)
/SoM/DEBUG_RXD_1V8: A1.238 (UART2_RXD), U4.5 (A1)
/SoM/DEBUG_TXD_1V8: A1.236 (UART2_TXD), U4.4 (A2)
/SoM/PMIC_BBAT: A1.235 (PMIC_BBAT), D34.1, R294.2
/SoM/SLEEP/~WAKE: A1.240 (SLEEP/WAKE*), TP2.1
/SoM/SoM_VDD_IN: A1.251 (VDD_IN), A1.252 (VDD_IN), A1.253 (VDD_IN), A1.254 (VDD_IN), A1.255 (VDD_IN), A1.256 (VDD_IN), A1.257 (VDD_IN), A1.258 (VDD_IN), A1.259 (VDD_IN), A1.260 (VDD_IN), C1.1, C2.1, C4.1, C5.1, FB1.2
/SoM/~FORCE_RECOVERY: A1.214 (FORCE_RECOVERY*), S1.1
/SoM/~MOD_SLEEP: A1.178 (MOD_SLEEP*), TP3.1
CAN_RX: A1.143 (CAN_RX); also elsewhere on the board
CAN_TX: A1.145 (CAN_TX); also elsewhere on the board
CLK_32K_3V3: U1.4 (B); also elsewhere on the board
CSI0_CLK_N: A1.10 (CSI0_CLK_N); also elsewhere on the board
CSI0_CLK_P: A1.12 (CSI0_CLK_P); also elsewhere on the board
CSI0_D0_N: A1.4 (CSI0_D0_N); also elsewhere on the board
CSI0_D0_P: A1.6 (CSI0_D0_P); also elsewhere on the board
CSI0_D1_N: A1.16 (CSI0_D1_N); also elsewhere on the board
CSI0_D1_P: A1.18 (CSI0_D1_P); also elsewhere on the board
CSI1_CLK_N: A1.9 (CSI1_CLK_N); also elsewhere on the board
CSI1_CLK_P: A1.11 (CSI1_CLK_P); also elsewhere on the board
CSI1_D0_N: A1.3 (CSI1_D0_N); also elsewhere on the board
CSI1_D0_P: A1.5 (CSI1_D0_P); also elsewhere on the board
CSI1_D1_N: A1.15 (CSI1_D1_N); also elsewhere on the board
CSI1_D1_P: A1.17 (CSI1_D1_P); also elsewhere on the board
CSI2_CLK_N: A1.28 (CSI2_CLK_N); also elsewhere on the board
CSI2_CLK_P: A1.30 (CSI2_CLK_P); also elsewhere on the board
CSI2_D0_N: A1.22 (CSI2_D0_N); also elsewhere on the board
CSI2_D0_P: A1.24 (CSI2_D0_P); also elsewhere on the board
CSI2_D1_N: A1.34 (CSI2_D1_N); also elsewhere on the board
CSI2_D1_P: A1.36 (CSI2_D1_P); also elsewhere on the board
CSI3_CLK_N: A1.27 (CSI3_CLK_N); also elsewhere on the board
CSI3_CLK_P: A1.29 (CSI3_CLK_P); also elsewhere on the board
CSI3_D0_N: A1.21 (CSI3_D0_N); also elsewhere on the board
CSI3_D0_P: A1.23 (CSI3_D0_P); also elsewhere on the board
CSI3_D1_N: A1.33 (CSI3_D1_N); also elsewhere on the board
CSI3_D1_P: A1.35 (CSI3_D1_P); also elsewhere on the board
DEBUG_RXD: U4.8 (B1); also elsewhere on the board
DEBUG_TXD: U4.1 (B2); also elsewhere on the board
DP1_HDMI_AUX_N: A1.98 (DP1_AUX_N); also elsewhere on the board
DP1_HDMI_AUX_P: A1.100 (DP1_AUX_P); also elsewhere on the board
DP1_HPD: A1.96 (DP1_HPD); also elsewhere on the board
DP1_TXD0_HDMI_TX2_N: A1.63 (DP1_TXD0_N); also elsewhere on the board
DP1_TXD0_HDMI_TX2_P: A1.65 (DP1_TXD0_P); also elsewhere on the board
DP1_TXD1_HDMI_TX1_N: A1.69 (DP1_TXD1_N); also elsewhere on the board
DP1_TXD1_HDMI_TX1_P: A1.71 (DP1_TXD1_P); also elsewhere on the board
DP1_TXD2_HDMI_TX0_N: A1.75 (DP1_TXD2_N); also elsewhere on the board
DP1_TXD2_HDMI_TX0_P: A1.77 (DP1_TXD2_P); also elsewhere on the board
DP1_TXD3_HDMI_TXC_N: A1.81 (DP1_TXD3_N); also elsewhere on the board
DP1_TXD3_HDMI_TXC_P: A1.83 (DP1_TXD3_P); also elsewhere on the board
FAN_PWM: A1.230 (GPIO14/PWM); also elsewhere on the board
FAN_TACH: A1.208 (Fan_Tach/GPIO08); also elsewhere on the board
GBE_LED_ACT: A1.194 (GBE_LED_ACT); also elsewhere on the board
GBE_LED_LINK: A1.188 (GBE_LED_LINK); also elsewhere on the board
GBE_MDI0_N: A1.184 (GBE_MDI0_N); also elsewhere on the board
GBE_MDI0_P: A1.186 (GBE_MDI0_P); also elsewhere on the board
GBE_MDI1_N: A1.190 (GBE_MDI1_N); also elsewhere on the board
GBE_MDI1_P: A1.192 (GBE_MDI1_P); also elsewhere on the board
GBE_MDI2_N: A1.196 (GBE_MDI2_N); also elsewhere on the board
GBE_MDI2_P: A1.198 (GBE_MDI2_P); also elsewhere on the board
GBE_MDI3_N: A1.202 (GBE_MDI3_N); also elsewhere on the board
GBE_MDI3_P: A1.204 (GBE_MDI3_P); also elsewhere on the board
GND: A1.1 (GND), A1.2 (GND), A1.7 (GND), A1.8 (GND), A1.13 (GND), A1.14 (GND), A1.19 (GND), A1.20 (GND), A1.25 (GND), A1.26 (GND), A1.31 (GND), A1.32 (GND), A1.37 (GND), A1.38 (GND), A1.43 (GND), A1.44 (GND), A1.49 (GND), A1.50 (GND), A1.55 (GND), A1.56 (GND), A1.61 (GND), A1.62 (GND), A1.67 (GND), A1.68 (GND), A1.73 (GND), A1.74 (GND), A1.79 (GND), A1.80 (GND), A1.85 (GND), A1.86 (GND), A1.102 (GND), A1.107 (GND), A1.113 (GND), A1.119 (GND), A1.125 (GND), A1.129 (GND), A1.132 (GND), A1.135 (GND), A1.138 (GND), A1.141 (GND), A1.144 (GND), A1.146 (GND), A1.147 (GND), A1.152 (GND), A1.153 (GND), A1.158 (GND), A1.159 (GND), A1.164 (GND), A1.165 (GND), A1.170 (GND), A1.171 (GND), A1.176 (GND), A1.177 (GND), A1.200 (GND), A1.201 (GND), A1.231 (GND), A1.241 (GND), A1.242 (GND), A1.243 (GND), A1.244 (GND), A1.245 (GND), A1.246 (GND), A1.247 (GND), A1.248 (GND), A1.249 (GND), A1.250 (GND), BAT1.-, C1.2, C2.2, C3.2, C4.2, C5.2, C6.2, C40.1, C41.1, S1.2, SP5.1, SP6.1, U1.2 (GND), U4.2 (GND); also elsewhere on the board
GPIO00: A1.87 (USB_VBUS_EN0/GPIO00); also elsewhere on the board
GPIO01: A1.118 (GPIO01/CLK); also elsewhere on the board
GPIO07: A1.206 (GPIO07/PWM); also elsewhere on the board
GPIO09: A1.211 (GPIO09/AUD_MCLK); also elsewhere on the board
GPIO10: A1.212 (GPIO10); also elsewhere on the board
GPIO11: A1.216 (GPIO11/CLK); also elsewhere on the board
GPIO12: R2.2; also elsewhere on the board
GPIO13: R3.2; also elsewhere on the board
I2C1_SCL: A1.189 (I2C1_SCL); also elsewhere on the board
I2C1_SDA: A1.191 (I2C1_SDA); also elsewhere on the board
I2C2_SCL: A1.232 (I2C2_SCL); also elsewhere on the board
I2C2_SDA: A1.234 (I2C2_SDA); also elsewhere on the board
I2S0_LRCK: A1.197 (I2S0_FS); also elsewhere on the board
I2S0_SCLK: A1.199 (I2S0_SCLK); also elsewhere on the board
I2S0_SDIN: A1.195 (I2S0_DIN); also elsewhere on the board
I2S0_SDOUT: A1.193 (I2S0_DOUT); also elsewhere on the board
I2S1_LRCK: A1.224 (I2S1_FS); also elsewhere on the board
I2S1_SCLK: A1.226 (I2S1_SCLK); also elsewhere on the board
I2S1_SDIN: A1.222 (I2S1_DIN); also elsewhere on the board
I2S1_SDOUT: A1.220 (I2S1_DOUT); also elsewhere on the board
MODULE_ID: A1.217 (GND(MODULE_ID)); also elsewhere on the board
unnamed: A1.94 (HDMI_CEC), TP35.1
unnamed: A1.114 (CAM0_PWDN), R12.1
unnamed: A1.116 (CAM0_MCLK), TP5.1
unnamed: A1.120 (CAM1_PWDN), R11.1
unnamed: A1.122 (CAM1_MCLK), TP4.1
unnamed: A1.124 (GPIO02), R1.1
unnamed: A1.218 (GPIO12/PWM), R2.1, R4.1
unnamed: A1.228 (GPIO13/PWM), R3.1, R5.1
unnamed: BAT1.+, R294.1
PCIE0_CLKREQ*: A1.180 (PCIE0_CLKREQ*); also elsewhere on the board
PCIE0_CLK_N: A1.160 (PCIE0_CLK_N); also elsewhere on the board
PCIE0_CLK_P: A1.162 (PCIE0_CLK_P); also elsewhere on the board
PCIE0_RST*: A1.181 (PCIE0_RST*); also elsewhere on the board
PCIE0_RX0_N: A1.131 (PCIE0_RX0_N); also elsewhere on the board
PCIE0_RX0_P: A1.133 (PCIE0_RX0_P); also elsewhere on the board
PCIE0_RX1_N: A1.137 (PCIE0_RX1_N); also elsewhere on the board
PCIE0_RX1_P: A1.139 (PCIE0_RX1_P); also elsewhere on the board
PCIE0_RX2_N: A1.149 (PCIE0_RX2_N); also elsewhere on the board
PCIE0_RX2_P: A1.151 (PCIE0_RX2_P); also elsewhere on the board
PCIE0_RX3_N: A1.155 (PCIE0_RX3_N); also elsewhere on the board
PCIE0_RX3_P: A1.157 (PCIE0_RX3_P); also elsewhere on the board
PCIE0_TX0_N: A1.134 (PCIE0_TX0_N); also elsewhere on the board
PCIE0_TX0_P: A1.136 (PCIE0_TX0_P); also elsewhere on the board
PCIE0_TX1_N: A1.140 (PCIE0_TX1_N); also elsewhere on the board
PCIE0_TX1_P: A1.142 (PCIE0_TX1_P); also elsewhere on the board
PCIE0_TX2_N: A1.148 (PCIE0_TX2_N); also elsewhere on the board
PCIE0_TX2_P: A1.150 (PCIE0_TX2_P); also elsewhere on the board
PCIE0_TX3_N: A1.154 (PCIE0_TX3_N); also elsewhere on the board
PCIE0_TX3_P: A1.156 (PCIE0_TX3_P); also elsewhere on the board
PCIE1_CLKREQ*: A1.182 (PCIE1_CLKREQ*); also elsewhere on the board
PCIE1_CLK_N: A1.173 (PCIE1_CLK_N); also elsewhere on the board
PCIE1_CLK_P: A1.175 (PCIE1_CLK_P); also elsewhere on the board
PCIE1_RST*: A1.183 (PCIE1_RST*); also elsewhere on the board
PCIE1_RX0_N: A1.167 (PCIE1_RX0_N); also elsewhere on the board
PCIE1_RX0_P: A1.169 (PCIE1_RX0_P); also elsewhere on the board
PCIE1_TX0_N: A1.172 (PCIE1_TX0_N); also elsewhere on the board
PCIE1_TX0_P: A1.174 (PCIE1_TX0_P); also elsewhere on the board
PCIE2_CLKREQ*: A1.221 (PCIE2_CLKREQ*); also elsewhere on the board
PCIE2_CLK_N: A1.52 (PCIE2_CLK_N); also elsewhere on the board
PCIE2_CLK_P: A1.54 (PCIE2_CLK_P); also elsewhere on the board
PCIE2_RST*: A1.219 (PCIE2_RST*); also elsewhere on the board
PCIE2_RX0_N: A1.40 (PCIE2_RX0_N); also elsewhere on the board
PCIE2_RX0_P: A1.42 (PCIE2_RX0_P); also elsewhere on the board
PCIE2_RX1_N: A1.58 (PCIE2_RX1_N/PCIE3_RX0_N); also elsewhere on the board
PCIE2_RX1_P: A1.60 (PCIE2_RX1_P/PCIE3_RX0_P); also elsewhere on the board
PCIE2_TX0_N: A1.46 (PCIE2_TX0_N); also elsewhere on the board
PCIE2_TX0_P: A1.48 (PCIE2_TX0_P); also elsewhere on the board
PCIE2_TX1_N: A1.64 (PCIE2_TX1_N/PCIE3_TX0_N); also elsewhere on the board
PCIE2_TX1_P: A1.66 (PCIE2_TX1_P/PCIE3_TX0_P); also elsewhere on the board
PCIE3_CLKREQ*: A1.225 (PCIE3_CLKREQ*); also elsewhere on the board
PCIE3_CLK_N: A1.227 (PCIE3_CLK_N); also elsewhere on the board
PCIE3_CLK_P: A1.229 (PCIE3_CLK_P); also elsewhere on the board
PCIE3_RST*: A1.223 (PCIE3_RST*)
PCIE_WAKE*: A1.179 (PCIE_WAKE*); also elsewhere on the board
POWER_EN: A1.237 (POWER_EN); also elsewhere on the board
SCL_CAM: A1.215 (CAM_I2C_SDA); also elsewhere on the board
SDA_CAM: A1.213 (CAM_I2C_SCL); also elsewhere on the board
SPI1_MISO: A1.108 (SPI1_MISO); also elsewhere on the board
SPI1_MOSI: A1.104 (SPI1_MOSI); also elsewhere on the board
SPI1_SCK: A1.106 (SPI1_SCK); also elsewhere on the board
SPIO_MISO: A1.93 (SPI0_MISO); also elsewhere on the board
SPIO_MOSI: A1.89 (SPI0_MOSI); also elsewhere on the board
SPIO_SCK: A1.91 (SPI0_SCK); also elsewhere on the board
SYS_SCL: A1.185 (I2C0_SCL); also elsewhere on the board
SYS_SDA: A1.187 (I2C0_SDA); also elsewhere on the board
UART0_CTS: A1.105 (UART0_CTS*); also elsewhere on the board
UART0_RTS: A1.103 (UART0_RTS*); also elsewhere on the board
UART0_RXD: A1.101 (UART0_RXD); also elsewhere on the board
UART0_TXD: A1.99 (UART0_TXD); also elsewhere on the board
UART1_RXD: A1.205 (UART1_RXD); also elsewhere on the board
UART1_TXD: A1.203 (UART1_TXD); also elsewhere on the board
USB0_D_N: A1.109 (USB0_D_N); also elsewhere on the board
USB0_D_P: A1.111 (USB0_D_P); also elsewhere on the board
USB1_D_N: A1.115 (USB1_D_N); also elsewhere on the board
USB1_D_P: A1.117 (USB1_D_P); also elsewhere on the board
USB2_D_N: A1.121 (USB2_D_N); also elsewhere on the board
USB2_D_P: A1.123 (USB2_D_P); also elsewhere on the board
USBSS0_RX_N: A1.161 (USBSS0_RX_N); also elsewhere on the board
USBSS0_RX_P: A1.163 (USBSS0_RX_P); also elsewhere on the board
USBSS0_TX_N: A1.166 (USBSS0_TX_N); also elsewhere on the board
USBSS0_TX_P: A1.168 (USBSS0_TX_P); also elsewhere on the board
USBSS1_RX_N: A1.39 (USBSS1_RX_N); also elsewhere on the board
USBSS1_RX_P: A1.41 (USBSS1_RX_P); also elsewhere on the board
USBSS1_TX_N: A1.45 (USBSS1_TX_N); also elsewhere on the board
USBSS1_TX_P: A1.47 (USBSS1_TX_P); also elsewhere on the board
USBSS2_RX_N: A1.51 (USBSS2_RX_N); also elsewhere on the board
USBSS2_RX_P: A1.53 (USBSS2_RX_P); also elsewhere on the board
USBSS2_TX_N: A1.57 (USBSS2_TX_N); also elsewhere on the board
USBSS2_TX_P: A1.59 (USBSS2_TX_P); also elsewhere on the board
USER_BTN0: A1.128 (GPIO05); also elsewhere on the board
USER_BTN1: A1.130 (GPIO06); also elsewhere on the board
USER_LED0: A1.126 (GPIO03); also elsewhere on the board
USER_LED1: A1.127 (GPIO04); also elsewhere on the board
VCC: FB1.1; also elsewhere on the board
VSYNC_CAM0: R12.2; also elsewhere on the board
VSYNC_CAM1: R11.2; also elsewhere on the board
VSYNC_CAM2: R4.2; also elsewhere on the board
VSYNC_CAM3: R5.2; also elsewhere on the board
~GPIO_INT: R1.2; also elsewhere on the board
~RESET: A1.239 (SYS_RESET*); also elsewhere on the board
~SHUTDOWN_REQ: A1.233 (SHUTDOWN_REQ*); also elsewhere on the board
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

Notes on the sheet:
DEBUG UART LEVEL SHIFTER
CSI
32kHz CLOCK BUFFER
Video Output
Power & CTRL
UART/I2C/SPI/I2S/CAN
PCIe
GbE
USB
GPIO
Miscellaneous

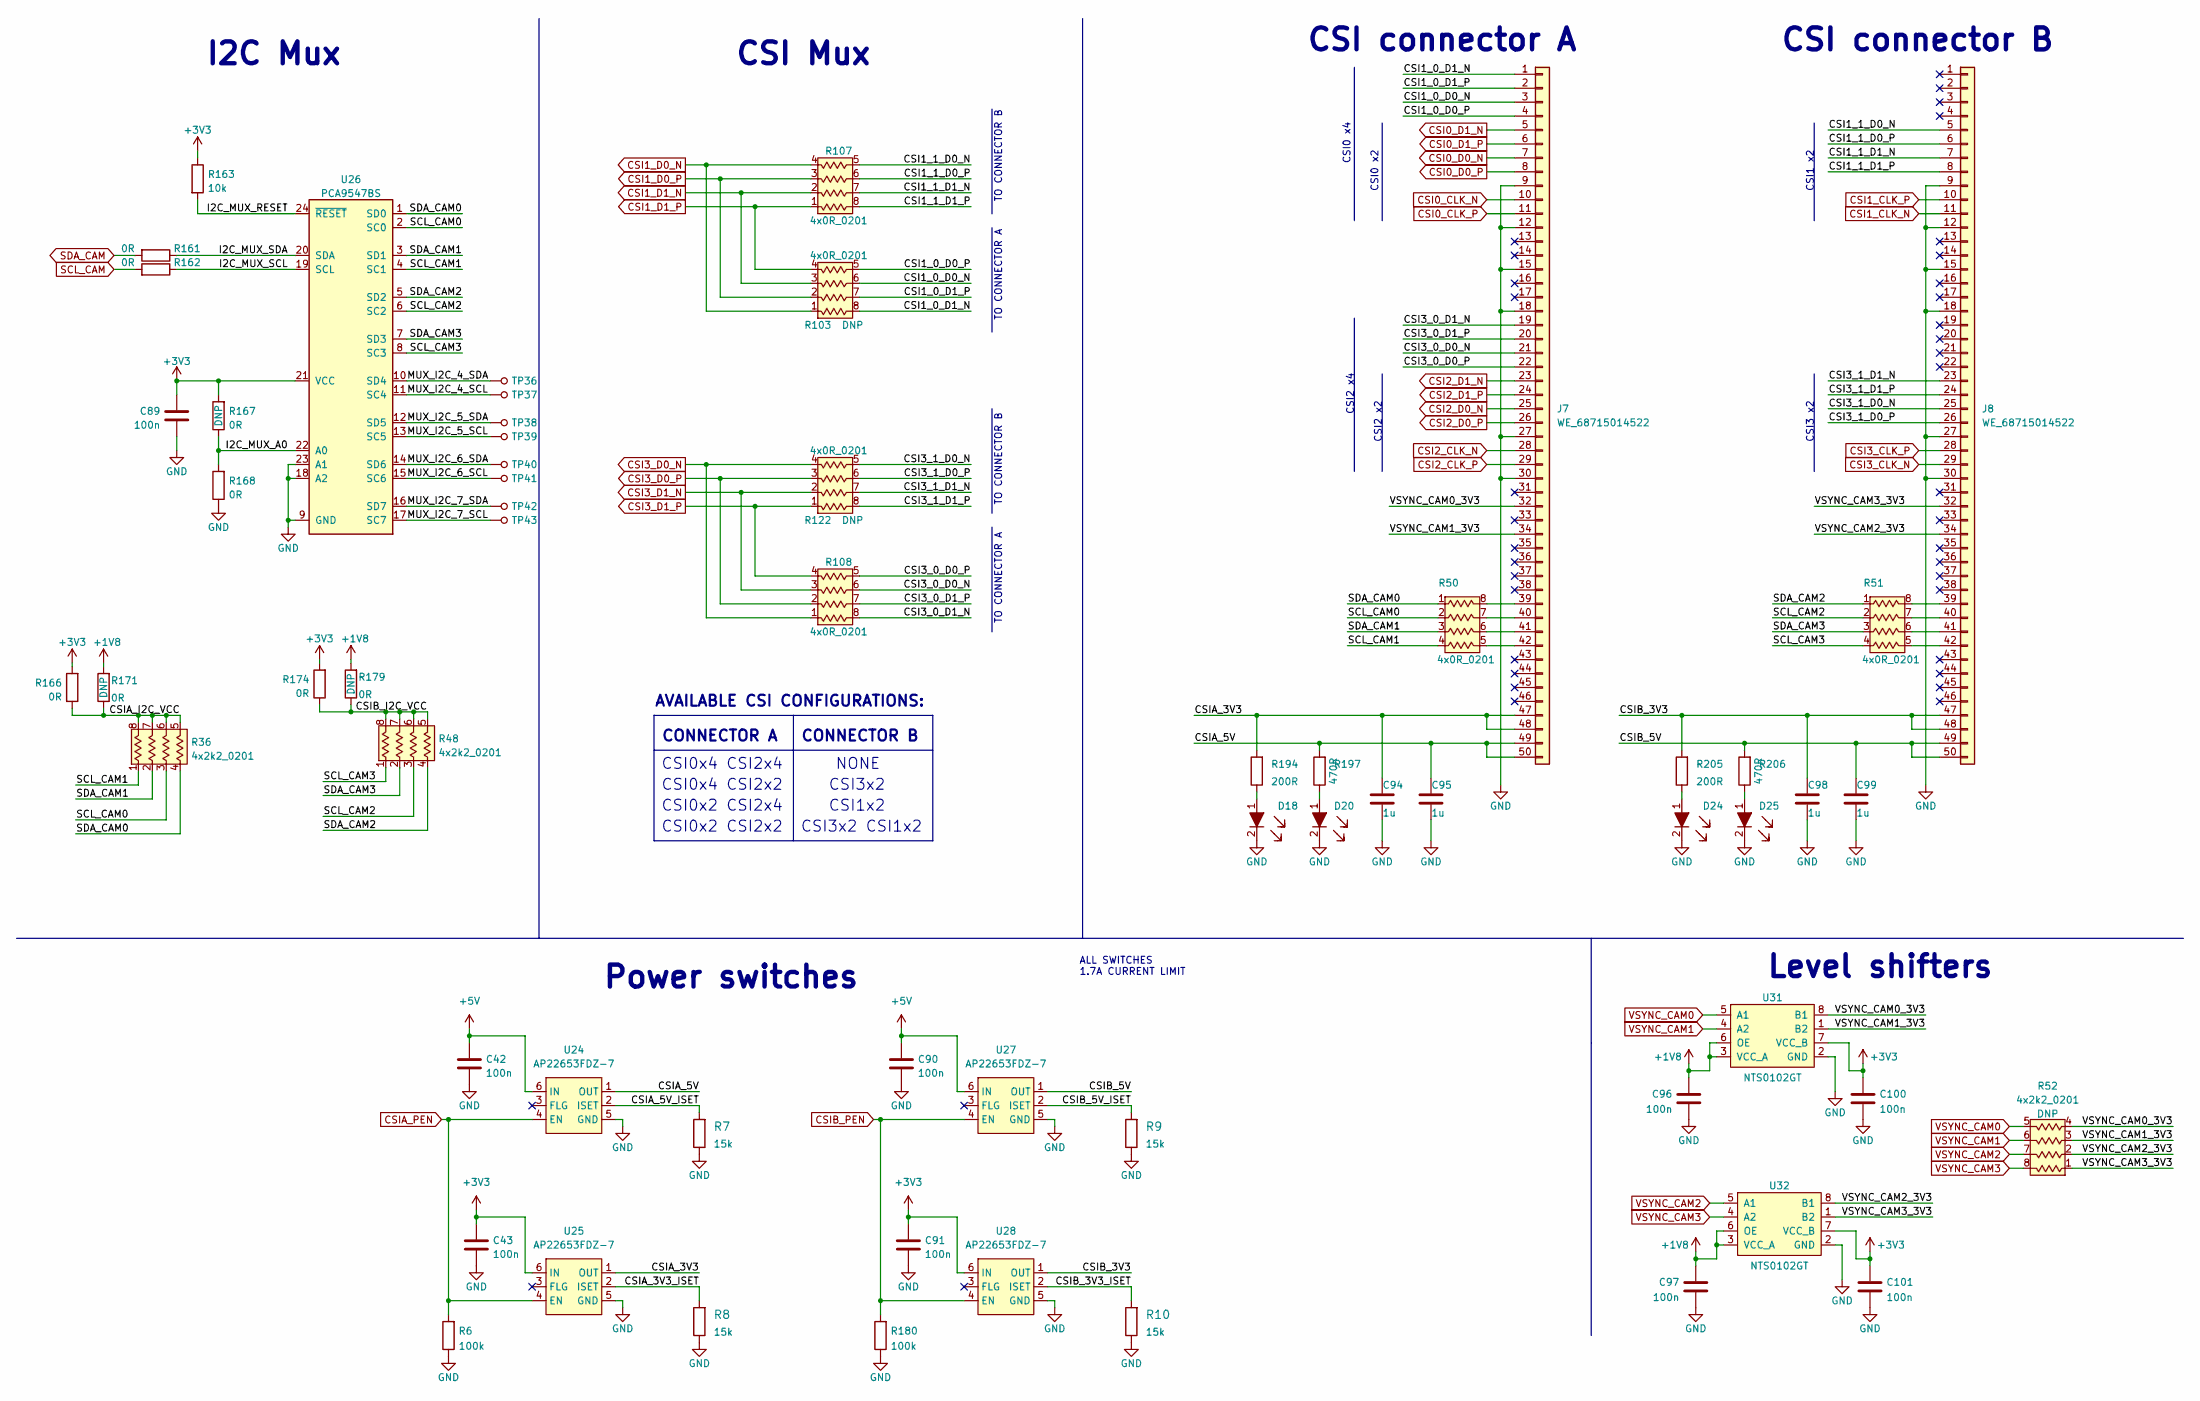
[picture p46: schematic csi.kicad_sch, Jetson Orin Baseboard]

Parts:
C42, C43, C89, C90, C91, C96, C97, C100, C101: C_100n_0402; 0402-cap; MPN GRM155R61H104KE14D
C94, C95, C98, C99: C_1u_0402; 0402-cap; MPN C1005X6S1A105K050BC
D18, D20, D24, D25: LTST-C190GKT; LED_0603; MPN LTST-C190GKT
J7, J8: WE_68715014522; MPN 68715014522
R6, R180: R_100k_0402; 0402-res; MPN CRCW0402100KFKEDHP
R7, R8, R9, R10: R_15k_0402; 0402-res; MPN SFR01MZPF1502
R36, R48, R52: 4x2k2_0201_array; EXB18V; MPN EXB-18V222JX
R50, R51, R103, R107, R108, R122: 4x0R_0201_array; EXB18V; MPN EXB-18VR000X
R161, R162, R166, R167, R168, R171, R174, R179: R_0R_0402; 0402-res; MPN ERJ2GE0R00X
R163: R_10k_0402; 0402-res; MPN CRCW040210K0FKEDHP
R194, R205: R_200R_0603; 0603-res; MPN ERJ-UP3F2000V
R197, R206: R_470R_0402; 0402-res; MPN CRCW0402470RFKED
TP36, TP37, TP38, TP39, TP40, TP41, TP42, TP43: TP_SMD_0_75MM; Testpoint_smd_0_75mm
U24, U25, U27, U28: AP22653FDZ-7; DFN-6-1EP_2x2mm_P0.65mm_EP1x1.6mm; MPN AP22653FDZ-7
U26: PCA9547BS; VQFN-24; MPN PCA9547BS,118
U31, U32: NTS0102GT; PSON50P100X195X50-8N; MPN NTS0102GT

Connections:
+1V8: C96.2, C97.2, R171.2, R179.2, U31.3 (VCC_A), U31.6 (OE), U32.3 (VCC_A), U32.6 (OE); also elsewhere on the board
+3V3: C43.1, C89.1, C91.1, C100.2, C101.2, R163.1, R166.2, R167.2, R174.2, U25.6 (IN), U26.21 (VCC), U28.6 (IN), U31.7 (VCC_B), U32.7 (VCC_B); also elsewhere on the board
+5V: C42.1, C90.1, U24.6 (IN), U27.6 (IN); also elsewhere on the board
/CSI/CSI1_0_D0_N: J7.3, R103.6
/CSI/CSI1_0_D0_P: J7.4, R103.5
/CSI/CSI1_0_D1_N: J7.1, R103.8
/CSI/CSI1_0_D1_P: J7.2, R103.7
/CSI/CSI1_1_D0_N: J8.5, R107.5
/CSI/CSI1_1_D0_P: J8.6, R107.6
/CSI/CSI1_1_D1_N: J8.7, R107.7
/CSI/CSI1_1_D1_P: J8.8, R107.8
/CSI/CSI3_0_D0_N: J7.21, R108.6
/CSI/CSI3_0_D0_P: J7.22, R108.5
/CSI/CSI3_0_D1_N: J7.19, R108.8
/CSI/CSI3_0_D1_P: J7.20, R108.7
/CSI/CSI3_1_D0_N: J8.25, R122.5
/CSI/CSI3_1_D0_P: J8.26, R122.6
/CSI/CSI3_1_D1_N: J8.23, R122.7
/CSI/CSI3_1_D1_P: J8.24, R122.8
/CSI/CSIA_3V3: C94.1, J7.47, J7.48, R194.2, U25.1 (OUT)
/CSI/CSIA_3V3_ISET: R8.2, U25.2 (ISET)
/CSI/CSIA_5V: C95.1, J7.49, J7.50, R197.2, U24.1 (OUT)
/CSI/CSIA_5V_ISET: R7.2, U24.2 (ISET)
/CSI/CSIA_I2C_VCC: R36.5, R36.6, R36.7, R36.8, R166.1, R171.1
/CSI/CSIB_3V3: C98.1, J8.47, J8.48, R205.2, U28.1 (OUT)
/CSI/CSIB_3V3_ISET: R10.2, U28.2 (ISET)
/CSI/CSIB_5V: C99.1, J8.49, J8.50, R206.2, U27.1 (OUT)
/CSI/CSIB_5V_ISET: R9.2, U27.2 (ISET)
/CSI/CSIB_I2C_VCC: R48.5, R48.6, R48.7, R48.8, R174.1, R179.1
/CSI/I2C_MUX_A0: R167.1, R168.2, U26.22 (A0)
/CSI/I2C_MUX_RESET: R163.2, U26.24 (~RESET)
/CSI/I2C_MUX_SCL: R162.1, U26.19 (SCL)
/CSI/I2C_MUX_SDA: R161.1, U26.20 (SDA)
/CSI/MUX_I2C_4_SCL: TP37.1, U26.11 (SC4)
/CSI/MUX_I2C_4_SDA: TP36.1, U26.10 (SD4)
/CSI/MUX_I2C_5_SCL: TP39.1, U26.13 (SC5)
/CSI/MUX_I2C_5_SDA: TP38.1, U26.12 (SD5)
/CSI/MUX_I2C_6_SCL: TP41.1, U26.15 (SC6)
/CSI/MUX_I2C_6_SDA: TP40.1, U26.14 (SD6)
/CSI/MUX_I2C_7_SCL: TP43.1, U26.17 (SC7)
/CSI/MUX_I2C_7_SDA: TP42.1, U26.16 (SD7)
/CSI/SCL_CAM0: R36.3, R50.2, U26.2 (SC0)
/CSI/SCL_CAM1: R36.1, R50.4, U26.4 (SC1)
/CSI/SCL_CAM2: R48.3, R51.2, U26.6 (SC2)
/CSI/SCL_CAM3: R48.1, R51.4, U26.8 (SC3)
/CSI/SDA_CAM0: R36.4, R50.1, U26.1 (SD0)
/CSI/SDA_CAM1: R36.2, R50.3, U26.3 (SD1)
/CSI/SDA_CAM2: R48.4, R51.1, U26.5 (SD2)
/CSI/SDA_CAM3: R48.2, R51.3, U26.7 (SD3)
/CSI/VSYNC_CAM0_3V3: J7.32, R52.4, U31.8 (B1)
/CSI/VSYNC_CAM1_3V3: J7.34, R52.3, U31.1 (B2)
/CSI/VSYNC_CAM2_3V3: J8.34, R52.2, U32.8 (B1)
/CSI/VSYNC_CAM3_3V3: J8.32, R52.1, U32.1 (B2)
CSI0_CLK_N: J7.10; also elsewhere on the board
CSI0_CLK_P: J7.11; also elsewhere on the board
CSI0_D0_N: J7.7; also elsewhere on the board
CSI0_D0_P: J7.8; also elsewhere on the board
CSI0_D1_N: J7.5; also elsewhere on the board
CSI0_D1_P: J7.6; also elsewhere on the board
CSI1_CLK_N: J8.11; also elsewhere on the board
CSI1_CLK_P: J8.10; also elsewhere on the board
CSI1_D0_N: R103.1, R107.4; also elsewhere on the board
CSI1_D0_P: R103.2, R107.3; also elsewhere on the board
CSI1_D1_N: R103.3, R107.2; also elsewhere on the board
CSI1_D1_P: R103.4, R107.1; also elsewhere on the board
CSI2_CLK_N: J7.28; also elsewhere on the board
CSI2_CLK_P: J7.29; also elsewhere on the board
CSI2_D0_N: J7.25; also elsewhere on the board
CSI2_D0_P: J7.26; also elsewhere on the board
CSI2_D1_N: J7.23; also elsewhere on the board
CSI2_D1_P: J7.24; also elsewhere on the board
CSI3_CLK_N: J8.29; also elsewhere on the board
CSI3_CLK_P: J8.28; also elsewhere on the board
CSI3_D0_N: R108.1, R122.4; also elsewhere on the board
CSI3_D0_P: R108.2, R122.3; also elsewhere on the board
CSI3_D1_N: R108.3, R122.2; also elsewhere on the board
CSI3_D1_P: R108.4, R122.1; also elsewhere on the board
CSIA_PEN: R6.2, U24.4 (EN), U25.4 (EN); also elsewhere on the board
CSIB_PEN: R180.2, U27.4 (EN), U28.4 (EN); also elsewhere on the board
GND: C42.2, C43.2, C89.2, C90.2, C91.2, C94.2, C95.2, C96.1, C97.1, C98.2, C99.2, C100.1, C101.1, D18.2, D20.2, D24.2, D25.2, J7.9, J7.12, J7.15, J7.18, J7.27, J7.30, J8.9, J8.12, J8.15, J8.18, J8.27, J8.30, R6.1, R7.1, R8.1, R9.1, R10.1, R168.1, R180.1, U24.5 (GND), U25.5 (GND), U26.9 (GND), U26.18 (A2), U26.23 (A1), U27.5 (GND), U28.5 (GND), U31.2 (GND), U32.2 (GND); also elsewhere on the board
unnamed: D18.1, R194.1
unnamed: D20.1, R197.1
unnamed: D24.1, R205.1
unnamed: D25.1, R206.1
unnamed: J7.39, R50.8
unnamed: J7.40, R50.7
unnamed: J7.41, R50.6
unnamed: J7.42, R50.5
unnamed: J8.39, R51.8
unnamed: J8.40, R51.7
unnamed: J8.41, R51.6
unnamed: J8.42, R51.5
SCL_CAM: R162.2; also elsewhere on the board
SDA_CAM: R161.2; also elsewhere on the board
VSYNC_CAM0: R52.5, U31.5 (A1); also elsewhere on the board
VSYNC_CAM1: R52.6, U31.4 (A2); also elsewhere on the board
VSYNC_CAM2: R52.7, U32.5 (A1); also elsewhere on the board
VSYNC_CAM3: R52.8, U32.4 (A2); also elsewhere on the board

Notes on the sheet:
CONNECTOR B
CSI2 x2
CSI0x2 CSI2x2
CONNECTOR A
CSI1x2
NONE
CSI3x2
TO CONNECTOR A
CSI3x2 CSI1x2
CSI0 x2
CSI3 x2
TO CONNECTOR B
CSI0x4 CSI2x2
Power switches
CSI2 x4
CSI0x4 CSI2x4
CSI1 x2
AVAILABLE CSI CONFIGURATIONS:
CSI Mux
CSI connector A
CSI0x2 CSI2x4
CSI0 x4
I2C Mux
CSI connector B
ALL SWITCHES 1.7A CURRENT LIMIT
Level shifters

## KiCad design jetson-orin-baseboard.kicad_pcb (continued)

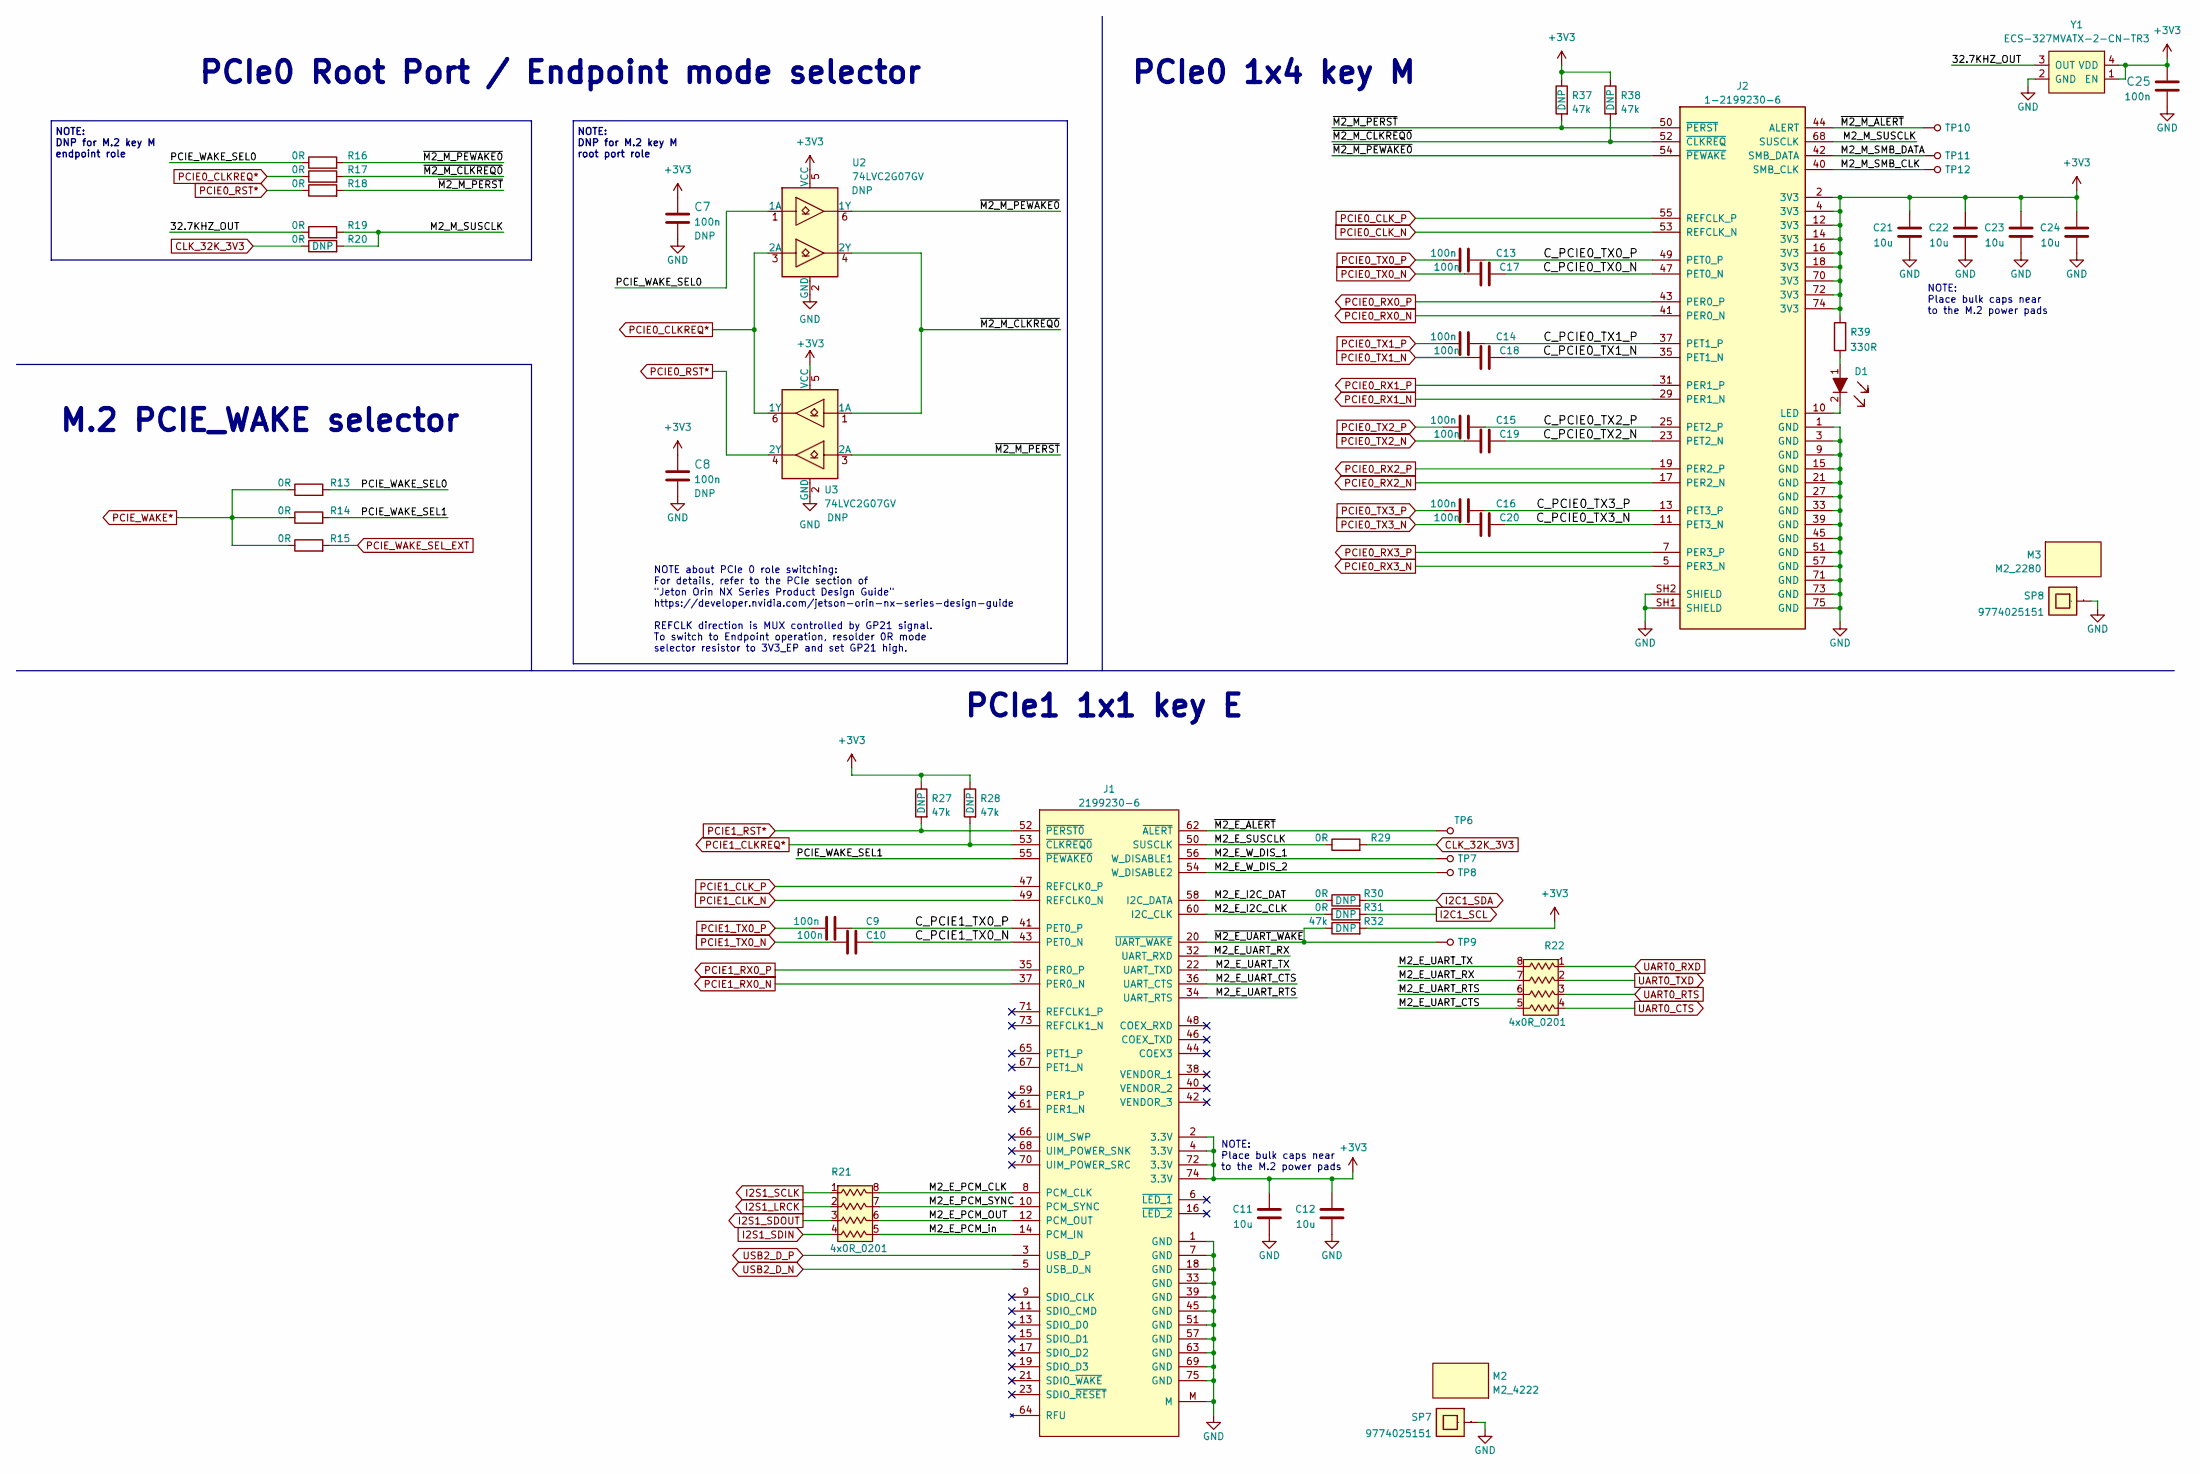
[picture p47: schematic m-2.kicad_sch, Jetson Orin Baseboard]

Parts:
C7, C8, C9, C10, C13, C14, C15, C16, C17, C18, C19, C20, C25: C_100n_0402; 0402-cap; MPN GRM155R61H104KE14D
C11, C12, C21, C22, C23, C24: C_10u_0603; 0603-cap; MPN GRM188R61A106KE69D
D1: LTST-C190GKT; LED_0603; MPN LTST-C190GKT
J1: 2199230-6; 2199230-4; MPN 2199230-6
J2: 1-2199230-6; MPN 1-2199230-6
M2: M2_4222; m2_4222
M3: M2_2280; m2_2280
R13, R14, R15, R16, R17, R18, R19, R20, R29, R30, R31: R_0R_0402; 0402-res; MPN ERJ2GE0R00X
R21, R22: 4x0R_0201_array; EXB18V; MPN EXB-18VR000X
R27, R28, R32, R37, R38: R_47k_0402; 0402-res; MPN MCMR04X4702FTL
R39: R_330R_0603; 0603-res; MPN CR0603-FX-3300GLF
SP7, SP8: 9774025151; MPN 9774025151
TP6, TP7, TP8, TP9, TP10, TP11, TP12: TP_SMD_0_75MM; Testpoint_smd_0_75mm
U2, U3: 74LVC2G07GV; SC-74; MPN 74LVC2G07GV,125
Y1: ECS-327MVATX-2-CN-TR3; Oscillator_SMD_ECS_2520MV-xxx-xx-4Pin_2.5x2.0mm; MPN ECS-327MVATX-2-CN-TR3

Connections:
+3V3: C7.1, C8.1, C11.1, C12.1, C21.1, C22.1, C23.1, C24.1, C25.1, J1.2 (3.3V), J1.4 (3.3V), J1.72 (3.3V), J1.74 (3.3V), J2.2 (3V3), J2.4 (3V3), J2.12 (3V3), J2.14 (3V3), J2.16 (3V3), J2.18 (3V3), J2.70 (3V3), J2.72 (3V3), J2.74 (3V3), R27.1, R28.1, R32.2, R37.1, R38.1, R39.2, U2.5 (VCC), U3.5 (VCC), Y1.1 (EN), Y1.4 (VDD); also elsewhere on the board
/M.2/32.7KHZ_OUT: R19.1, Y1.3 (OUT)
/M.2/C_PCIE0_TX0_N: C17.2, J2.47 (PET0_N)
/M.2/C_PCIE0_TX0_P: C13.2, J2.49 (PET0_P)
/M.2/C_PCIE0_TX1_N: C18.2, J2.35 (PET1_N)
/M.2/C_PCIE0_TX1_P: C14.2, J2.37 (PET1_P)
/M.2/C_PCIE0_TX2_N: C19.2, J2.23 (PET2_N)
/M.2/C_PCIE0_TX2_P: C15.2, J2.25 (PET2_P)
/M.2/C_PCIE0_TX3_N: C20.2, J2.11 (PET3_N)
/M.2/C_PCIE0_TX3_P: C16.2, J2.13 (PET3_P)
/M.2/C_PCIE1_TX0_N: C10.2, J1.43 (PET0_N)
/M.2/C_PCIE1_TX0_P: C9.2, J1.41 (PET0_P)
/M.2/M2_E_I2C_CLK: J1.60 (I2C_CLK), R31.1
/M.2/M2_E_I2C_DAT: J1.58 (I2C_DATA), R30.1
/M.2/M2_E_PCM_CLK: J1.8 (PCM_CLK), R21.8
/M.2/M2_E_PCM_OUT: J1.12 (PCM_OUT), R21.6
/M.2/M2_E_PCM_SYNC: J1.10 (PCM_SYNC), R21.7
/M.2/M2_E_PCM_in: J1.14 (PCM_IN), R21.5
/M.2/M2_E_SUSCLK: J1.50 (SUSCLK), R29.1
/M.2/M2_E_UART_CTS: J1.36 (UART_CTS), R22.5
/M.2/M2_E_UART_RTS: J1.34 (UART_RTS), R22.6
/M.2/M2_E_UART_RX: J1.32 (UART_RXD), R22.7
/M.2/M2_E_UART_TX: J1.22 (UART_TXD), R22.8
/M.2/M2_E_W_DIS_1: J1.56 (W_DISABLE1), TP7.1
/M.2/M2_E_W_DIS_2: J1.54 (W_DISABLE2), TP8.1
/M.2/M2_M_SMB_CLK: J2.40 (SMB_CLK), TP12.1
/M.2/M2_M_SMB_DATA: J2.42 (SMB_DATA), TP11.1
/M.2/M2_M_SUSCLK: J2.68 (SUSCLK), R19.2, R20.2
/M.2/PCIE_WAKE_SEL0: R13.2, R16.1, U2.1 (1A)
/M.2/PCIE_WAKE_SEL1: J1.55 (~PEWAKE0), R14.2
/M.2/~M2_E_ALERT: J1.62 (~ALERT), TP6.1
/M.2/~M2_E_UART_WAKE: J1.20 (~UART_WAKE), R32.1, TP9.1
/M.2/~M2_M_ALERT: J2.44 (ALERT), TP10.1
/M.2/~M2_M_CLKREQ0: J2.52 (~CLKREQ), R17.2, R38.2, U2.4 (2Y), U3.1 (1A)
/M.2/~M2_M_PERST: J2.50 (~PERST), R18.2, R37.2, U3.3 (2A)
/M.2/~M2_M_PEWAKE0: J2.54 (~PEWAKE), R16.2, U2.6 (1Y)
CLK_32K_3V3: R20.1, R29.2; also elsewhere on the board
GND: C7.2, C8.2, C11.2, C12.2, C21.2, C22.2, C23.2, C24.2, C25.2, J1.1 (GND), J1.7 (GND), J1.18 (GND), J1.33 (GND), J1.39 (GND), J1.45 (GND), J1.51 (GND), J1.57 (GND), J1.63 (GND), J1.69 (GND), J1.75 (GND), J1.M, J2.1 (GND), J2.3 (GND), J2.9 (GND), J2.15 (GND), J2.21 (GND), J2.27 (GND), J2.33 (GND), J2.39 (GND), J2.45 (GND), J2.51 (GND), J2.57 (GND), J2.71 (GND), J2.73 (GND), J2.75 (GND), J2.SH1 (SHIELD), J2.SH2 (SHIELD), SP7.1, SP8.1, U2.2 (GND), U3.2 (GND), Y1.2 (GND); also elsewhere on the board
I2C1_SCL: R31.2; also elsewhere on the board
I2C1_SDA: R30.2; also elsewhere on the board
I2S1_LRCK: R21.2; also elsewhere on the board
I2S1_SCLK: R21.1; also elsewhere on the board
I2S1_SDIN: R21.4; also elsewhere on the board
I2S1_SDOUT: R21.3; also elsewhere on the board
unnamed: D1.1, R39.1
unnamed: D1.2, J2.10 (LED)
PCIE0_CLKREQ*: R17.1, U2.3 (2A), U3.6 (1Y); also elsewhere on the board
PCIE0_CLK_N: J2.53 (REFCLK_N); also elsewhere on the board
PCIE0_CLK_P: J2.55 (REFCLK_P); also elsewhere on the board
PCIE0_RST*: R18.1, U3.4 (2Y); also elsewhere on the board
PCIE0_RX0_N: J2.41 (PER0_N); also elsewhere on the board
PCIE0_RX0_P: J2.43 (PER0_P); also elsewhere on the board
PCIE0_RX1_N: J2.29 (PER1_N); also elsewhere on the board
PCIE0_RX1_P: J2.31 (PER1_P); also elsewhere on the board
PCIE0_RX2_N: J2.17 (PER2_N); also elsewhere on the board
PCIE0_RX2_P: J2.19 (PER2_P); also elsewhere on the board
PCIE0_RX3_N: J2.5 (PER3_N); also elsewhere on the board
PCIE0_RX3_P: J2.7 (PER3_P); also elsewhere on the board
PCIE0_TX0_N: C17.1; also elsewhere on the board
PCIE0_TX0_P: C13.1; also elsewhere on the board
PCIE0_TX1_N: C18.1; also elsewhere on the board
PCIE0_TX1_P: C14.1; also elsewhere on the board
PCIE0_TX2_N: C19.1; also elsewhere on the board
PCIE0_TX2_P: C15.1; also elsewhere on the board
PCIE0_TX3_N: C20.1; also elsewhere on the board
PCIE0_TX3_P: C16.1; also elsewhere on the board
PCIE1_CLKREQ*: J1.53 (~CLKREQ0), R28.2; also elsewhere on the board
PCIE1_CLK_N: J1.49 (REFCLK0_N); also elsewhere on the board
PCIE1_CLK_P: J1.47 (REFCLK0_P); also elsewhere on the board
PCIE1_RST*: J1.52 (~PERST0), R27.2; also elsewhere on the board
PCIE1_RX0_N: J1.37 (PER0_N); also elsewhere on the board
PCIE1_RX0_P: J1.35 (PER0_P); also elsewhere on the board
PCIE1_TX0_N: C10.1; also elsewhere on the board
PCIE1_TX0_P: C9.1; also elsewhere on the board
PCIE_WAKE*: R13.1, R14.1, R15.1; also elsewhere on the board
PCIE_WAKE_SEL_EXT: R15.2; also elsewhere on the board
UART0_CTS: R22.4; also elsewhere on the board
UART0_RTS: R22.3; also elsewhere on the board
UART0_RXD: R22.1; also elsewhere on the board
UART0_TXD: R22.2; also elsewhere on the board
USB2_D_N: J1.5 (USB_D_N); also elsewhere on the board
USB2_D_P: J1.3 (USB_D_P); also elsewhere on the board

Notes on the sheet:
PCIe1 1x1 key E
NOTE about PCIe 0 role switching: For details, refer to the PCIe section of "Jeton Orin NX Series Product Design Guide" https://developer.nvidia.com/jetson-orin-nx-series-design-guide REFCLK direction is MUX controlled by GP21 signal. To switch to Endpoint operation, resolder 0R mode selector resis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
M.2 PCIE_WAKE selector
PCIe0 1x4 key M
NOTE: Place bulk caps near to the M.2 power pads
NOTE: DNP for M.2 key M root port role
PCIe0 Root Port / Endpoint mode selector
NOTE: DNP for M.2 key M endpoint role

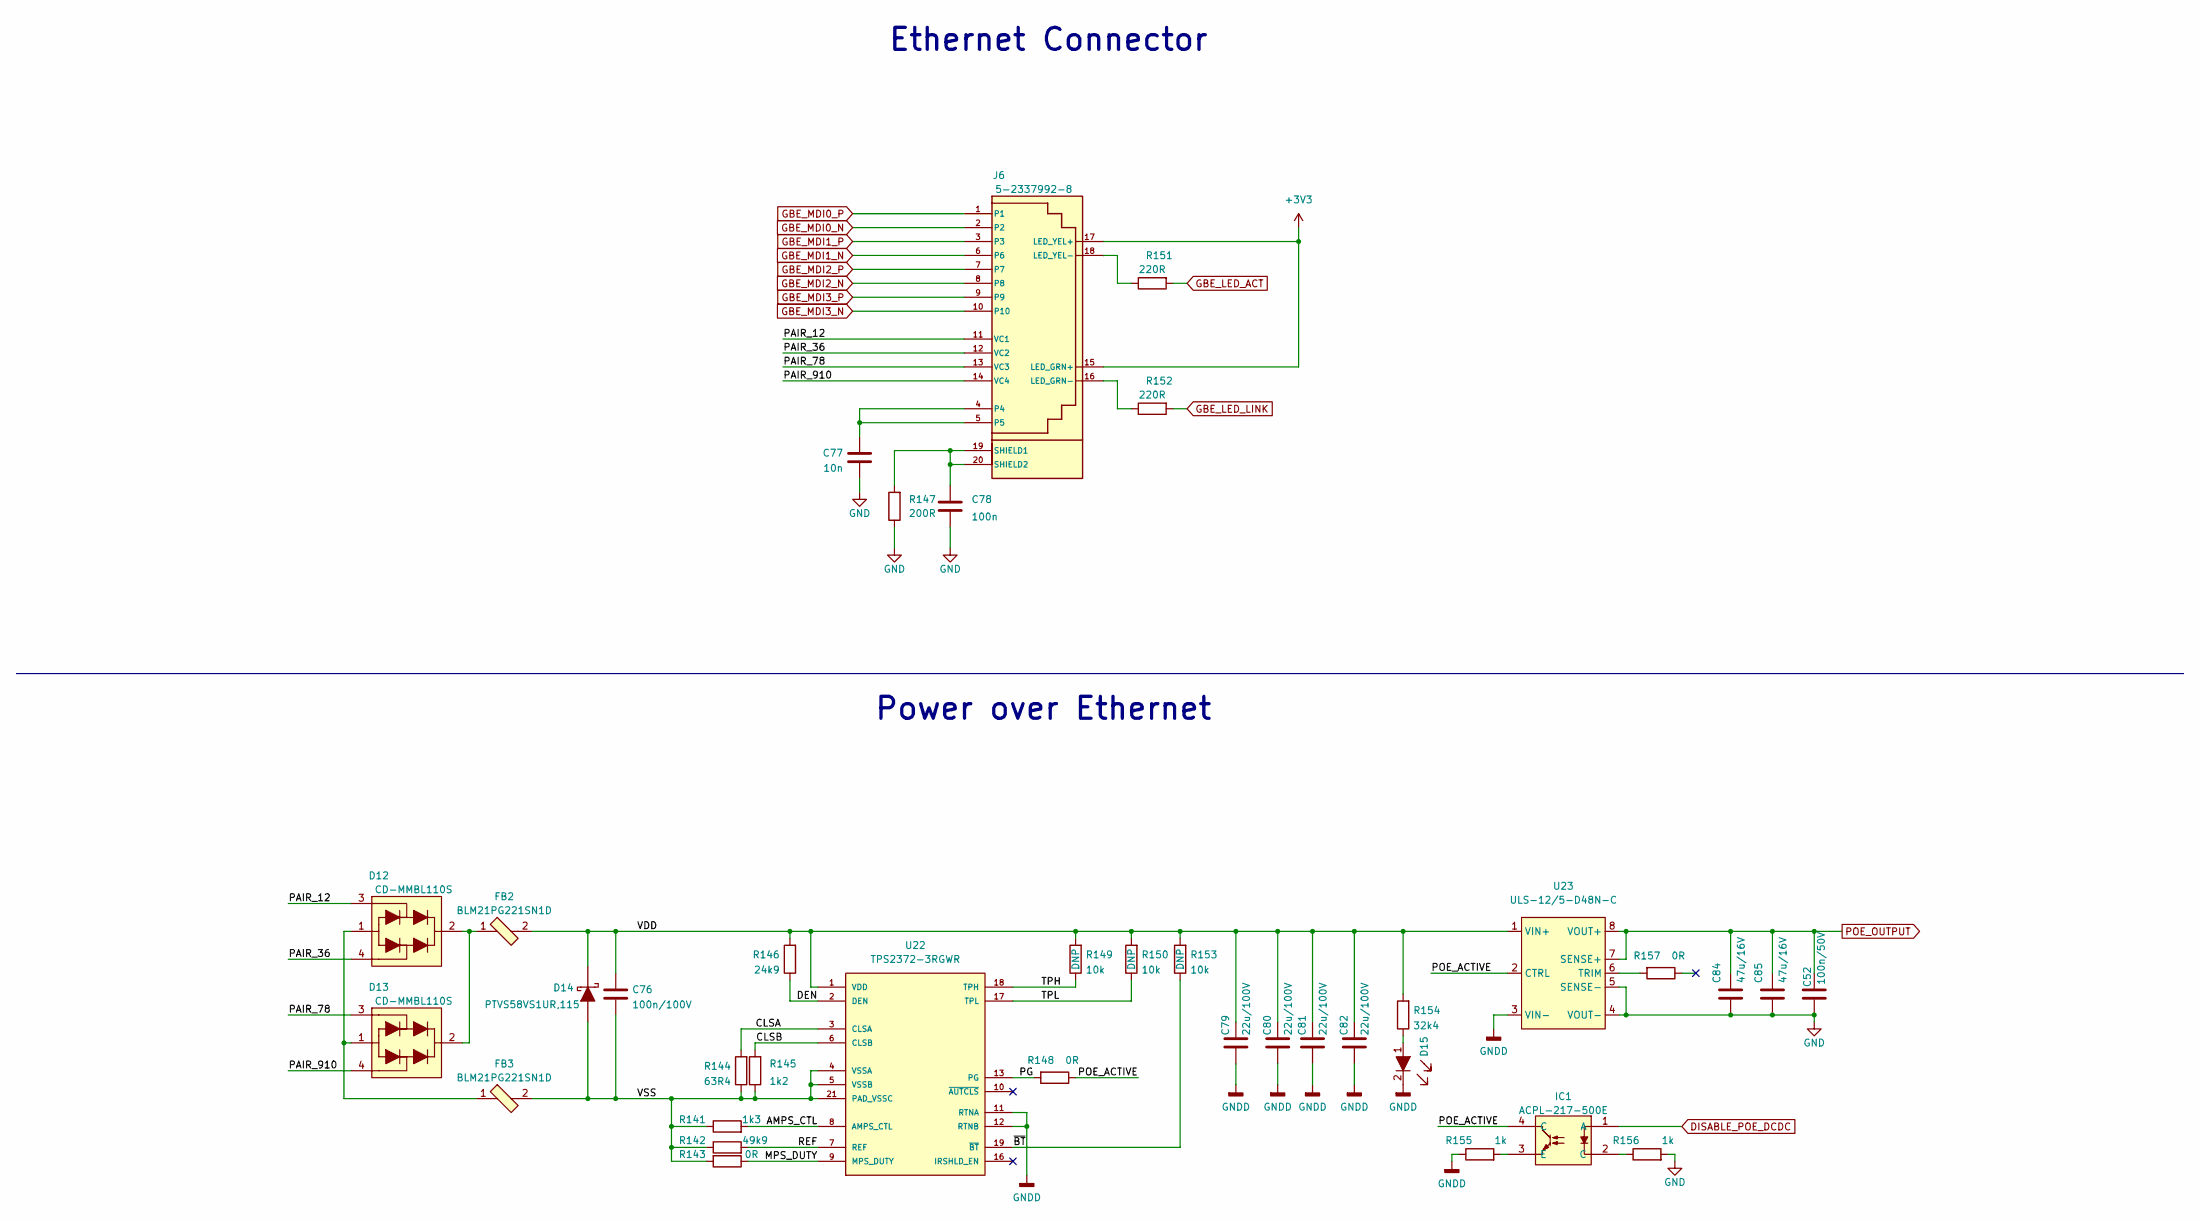
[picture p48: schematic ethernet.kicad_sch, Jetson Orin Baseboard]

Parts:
C52: C_100n_0402_50V; 0402-cap; MPN GRM155R71H104KE14D
C76: C_100n_0805_100V; 0805-cap; MPN CL21B104KCFNNNE
C77: C_10n_0402; 0402-cap; MPN 04025G103ZAT2A
C78: C_100n_0402; 0402-cap; MPN GRM155R61H104KE14D
C79, C80, C81, C82: C_22u_2220_100V; 2220-cap; MPN C5750X7S2A226M280KB
C84, C85: C_47u_16V_1206; 1206-cap; MPN C3216X5R1C476M160AB
D12, D13: CD-MMBL110S; DFN3538; MPN CD-MMBL110S
D14: PTVS58VS1UR,115; SOD-123F; MPN PTVS58VS1UR,115
D15: LTST-C190GKT; LED_0603; MPN LTST-C190GKT
FB2, FB3: BLM21PG221SN1D; 0805-res; MPN BLM21PG221SN1D
IC1: ACPL-217-500E; SOIC127P700X242-4N; MPN ACPL-217-500E; Mouser Part Number 630-ACPL-217-500E
J6: 5-2337992-8; MPN 5-2337992-8
R141: R_1k3_0603; 0603-res; MPN ERJ3GEYJ132V
R142: R_49k9_0402; 0402-res; MPN CRCW040249K9FKED
R143, R148, R157: R_0R_0603; 0603-res; MPN CR0603-J/-000ELF
R144: R_63R4_0603; 0603-res; MPN ERJPA3F63R4V
R145: R_1k2_0402; 0402-res; MPN ERJ2RKF1201X
R146: R_24k9_0402; 0402-res; MPN WR04X2492FTL
R147: R_200R_0402; 0402-res; MPN RC0402FR-07200RL
R149, R150, R153: R_10k_0402; 0402-res; MPN CRCW040210K0FKEDHP
R151, R152: R_220R_0402; 0402-res; MPN ERJ2GEJ221X
R154: R_32k4_0402; 0402-res; MPN ERA-2ARB3242X
R155, R156: R_1k_0603; 0603-res; MPN CR0603-JW-102ELF
U22: TPS2372-3RGWR; Texas_RGW0020B; MPN TPS2372-3RGWR
U23: ULS-12/5-D48N-C; ULS-12_5-D48N-C; MPN ULS-12/5-D48N-C

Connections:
+3V3: J6.15 (LED_GRN+), J6.17 (LED_YEL+); also elsewhere on the board
/Ethernet/AMPS_CTL: R141.2, U22.8 (AMPS_CTL)
/Ethernet/CLSA: R144.2, U22.3 (CLSA)
/Ethernet/CLSB: R145.2, U22.6 (CLSB)
/Ethernet/DEN: R146.1, U22.2 (DEN)
/Ethernet/MPS_DUTY: R143.1, U22.9 (MPS_DUTY)
/Ethernet/PAIR_12: D12.3, J6.11 (VC1)
/Ethernet/PAIR_36: D12.4, J6.12 (VC2)
/Ethernet/PAIR_78: D13.3, J6.13 (VC3)
/Ethernet/PAIR_910: D13.4, J6.14 (VC4)
/Ethernet/PG: R148.2, U22.13 (PG)
/Ethernet/POE_ACTIVE: IC1.4 (C), R148.1, U23.2 (CTRL)
/Ethernet/REF: R142.2, U22.7 (REF)
/Ethernet/TPH: R149.1, U22.18 (TPH)
/Ethernet/TPL: R150.1, U22.17 (TPL)
/Ethernet/VDD: C76.1, C79.1, C80.1, C81.1, C82.1, D14.K, FB2.2, R146.2, R149.2, R150.2, R153.2, R154.2, U22.1 (VDD), U23.1 (VIN+)
/Ethernet/VSS: C76.2, D14.A, FB3.2, R141.1, R142.1, R143.2, R144.1, R145.1, U22.4 (VSSA), U22.5 (VSSB), U22.21 (PAD_VSSC)
/Ethernet/~BT: R153.1, U22.19 (~BT)
DISABLE_POE_DCDC: IC1.1 (A); also elsewhere on the board
GBE_LED_ACT: R151.2; also elsewhere on the board
GBE_LED_LINK: R152.2; also elsewhere on the board
GBE_MDI0_N: J6.2; also elsewhere on the board
GBE_MDI0_P: J6.1; also elsewhere on the board
GBE_MDI1_N: J6.6; also elsewhere on the board
GBE_MDI1_P: J6.3; also elsewhere on the board
GBE_MDI2_N: J6.8; also elsewhere on the board
GBE_MDI2_P: J6.7; also elsewhere on the board
GBE_MDI3_N: J6.10; also elsewhere on the board
GBE_MDI3_P: J6.9; also elsewhere on the board
GND: C52.2, C77.2, C78.2, C84.2, C85.2, R147.1, R156.2, U23.4 (VOUT-), U23.5 (SENSE-); also elsewhere on the board
GNDD: C79.2, C80.2, C81.2, C82.2, D15.2, R155.1, U22.11 (RTNA), U22.12 (RTNB), U23.3 (VIN-)
unnamed: C77.1, J6.4, J6.5
unnamed: C78.1, J6.19 (SHIELD1), J6.20 (SHIELD2), R147.2
unnamed: D12.1, D13.1, FB3.1
unnamed: D12.2, D13.2, FB2.1
unnamed: D15.1, R154.1
unnamed: IC1.2 (C), R156.1
unnamed: IC1.3 (E), R155.2
unnamed: J6.16 (LED_GRN-), R152.1
unnamed: J6.18 (LED_YEL-), R151.1
unnamed: R157.2, U23.6 (TRIM)
POE_OUTPUT: C52.1, C84.1, C85.1, U23.7 (SENSE+), U23.8 (VOUT+); also elsewhere on the board

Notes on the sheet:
Power over Ethernet
Ethernet Connector

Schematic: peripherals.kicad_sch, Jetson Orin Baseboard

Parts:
C44, C48, C104, C108, C109, C110, C111, C112, C113: C_100n_0402; 0402-cap; MPN GRM155R61H104KE14D
C105, C106, C107, C114, C115: C_1u_0402; 0402-cap; MPN C1005X6S1A105K050BC
D26, D27: LTST-C190GKT; LED_0603; MPN LTST-C190GKT
D39, D40, D41, D42, D43, D44, D45, D46, D47, D48, D49, D50: TPD1E0B04DPYR; XDFN-2_1x0.60mm; MPN TPD1E0B04DPYR
J9: TC2050-IDC-NL; TC2050-IDC-NL_2x05_Vertical; MPN TC2050-IDC-NL
J10: 533980471; Molex_PicoBlade_53398-0471_1x04-1MP_P1.25mm_Vertical; MPN 0533980471
J11: ERF8-040-05.0-L-DV-K-TR; ERF8-040-XX.X-X-DV-XX; MPN ERF8-040-05.0-L-DV-K-TR
Q9, Q10: NX138BKMYL; DFN1006-3; MPN NX138BKMYL
R25: 4x0R_0201_array; EXB18V; MPN EXB-18VR000X
R26, R53, R54, R63, R64, R100, R101, R102: 4x330R_0402_array; R_Array_4x0402; MPN EXB-28V331JX
R55, R62, R120, R121, R215, R216, R217, R218: R_0R_0402; 0402-res; MPN ERJ2GE0R00X
R219: R_10k2_0402; 0402-res; MPN MCWR04X1022FTL
R222, R230: R_100k_0402; 0402-res; MPN CRCW0402100KFKEDHP
R223, R231: R_200R_0402; 0402-res; MPN RC0402FR-07200RL
R232, R242: R_10k_0402; 0402-res; MPN CRCW040210K0FKEDHP
R233, R234, R235, R247, R248: R_0R_0603; 0603-res; MPN CR0603-J/-000ELF
R335, R336: R_470R_0402; 0402-res; MPN CRCW0402470RFKED
S2, S3: B3U-3000PM; B3U-3000P; MPN B3U-3000PM
TP1, TP34, TP46, TP47: TP_SMD_0_75MM; Testpoint_smd_0_75mm
U29, U30: TPD4E05U06QDQARQ1; USON-10_2.5x1.0mm_P0.5mm; MPN TPD4E05U06QDQARQ1
U33: NTS0102GT; PSON50P100X195X50-8N; MPN NTS0102GT
U34: PCAL6408ABSHP; VQFN-16-1EP_3x3mm; MPN PCAL6408ABSHP

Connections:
3V3_STDB: R247.2; also elsewhere on the board
+1V8: C44.2, R219.2, R232.2, R234.2, R242.2, U33.3 (VCC_A), U33.6 (OE); also elsewhere on the board
+3V3: C104.1, R223.2, R231.2, R233.2, U34.14 (Vdd(p)), U34.15 (Vdd(I2C)); also elsewhere on the board
+5V: C48.2, J10.2, R235.1, U33.7 (VCC_B); also elsewhere on the board
+12V: R248.1
/Peripherals/1V8_CONN: C106.1, J11.73, R234.1
/Peripherals/3V3_CONN: C105.1, J11.67, J11.69, R233.1
/Peripherals/3V3_STDB_CONN: C114.1, J11.74, R247.1
/Peripherals/5V_CONN: C107.1, J11.77, J11.79, R235.2
/Peripherals/12V_CONN: C115.1, J11.78, J11.80, R248.2
/Peripherals/FAN_PWM_5V: J10.4, U33.8 (B1)
/Peripherals/FAN_TACH_5V: J10.3, U33.1 (B2)
/Peripherals/GPIO00_CONN: J11.44, R100.2
/Peripherals/GPIO01_CONN: J11.31, R26.2
/Peripherals/GPIO07_CONN: J11.33, R26.1
/Peripherals/GPIO09_CONN: J11.35, R53.4
/Peripherals/GPIO10_CONN: J11.39, R53.3
/Peripherals/GPIO11_CONN: J11.42, R100.3
/Peripherals/GPIO12_CONN: J11.40, R100.4
/Peripherals/GPIO13_CONN: J11.36, R64.1
/Peripherals/GPIOEX_ADDR: R218.2, U34.16 (ADDR)
/Peripherals/GPIOEX_I2C_SCL: R216.2, U34.12 (SCL)
/Peripherals/GPIOEX_I2C_SDA: R215.2, U34.13 (SDA)
/Peripherals/GPIOEX_P0_0: R25.8, U34.2 (P0)
/Peripherals/GPIOEX_P0_1: R25.7, U34.3 (P1)
/Peripherals/GPIOEX_P0_2: R25.6, U34.4 (P2)
/Peripherals/GPIOEX_P0_3: R25.5, U34.5 (P3)
/Peripherals/GPIOEX_RESET: R217.2, U34.1 (~RESET)
/Peripherals/I2S0_LRCK_CONN: J11.47, R54.3
/Peripherals/I2S0_SCLK_CONN: J11.46, R100.1
/Peripherals/I2S0_SDIN_CONN: J11.45, R54.4
/Peripherals/I2S0_SDOUT_CONN: J11.48, R101.4
/Peripherals/PCIE2_CLKREQ_CONN*: J11.29, R26.3
/Peripherals/PCIE2_RST_CONN*: J11.27, R26.4
/Peripherals/PCIE2_TX0_CONN_N: C108.2, D41.1, J11.9
/Peripherals/PCIE2_TX0_CONN_P: C109.2, D42.1, J11.11
/Peripherals/PCIE2_TX1_CONN_N: C112.2, D47.1, J11.3
/Peripherals/PCIE2_TX1_CONN_P: C110.2, D48.1, J11.5
/Peripherals/PCIE3_CLKREQ_CONN*: J11.32, R64.3
/Peripherals/PCIE_WAKE_SEL_EXT_CONN: J11.34, R64.2
/Peripherals/SPI1_MISO_CONN: J11.56, R101.1
/Peripherals/SPI1_MOSI_CONN: J11.54, R101.2
/Peripherals/SPI1_SCK_CONN: J11.52, R101.3
/Peripherals/SPIO_MISO_CONN: J11.55, R63.3
/Peripherals/SPIO_MOSI_CONN: J11.53, R54.1
/Peripherals/SPIO_SCK_CONN: J11.51, R54.2
/Peripherals/UART1_RXD_CONN: J11.43, R53.1
/Peripherals/UART1_TXD_CONN: J11.41, R53.2
/Peripherals/USBSS2_TX_CONN_N: C113.2, J11.21, U29.4 (IO3), U29.7 (IO3)
/Peripherals/USBSS2_TX_CONN_P: C111.2, J11.23, U29.5 (IO4), U29.6 (IO4)
/Peripherals/~SPI0_CS0_CONN: J11.57, R63.2
/Peripherals/~SPI0_CS1_CONN: J11.59, R63.1
/Peripherals/~SPI1_CS0_CONN: J11.58, R102.2
/Peripherals/~SPI1_CS1_CONN: J11.60, R102.1
CAN_RX: R335.1; also elsewhere on the board
CAN_TX: R336.1; also elsewhere on the board
CSIA_PEN: R25.1; also elsewhere on the board
CSIB_PEN: R25.2; also elsewhere on the board
DEBUG_RXD: J9.2; also elsewhere on the board
DEBUG_TXD: J9.1; also elsewhere on the board
DISABLE_POE_DCDC: R25.4; also elsewhere on the board
EEPROM_PWR: J9.10; also elsewhere on the board
FAN_PWM: U33.5 (A1); also elsewhere on the board
FAN_TACH: U33.4 (A2); also elsewhere on the board
GND: C44.1, C48.1, C104.2, C105.2, C106.2, C107.2, C114.2, C115.2, D39.2, D40.2, D41.2, D42.2, D43.2, D44.2, D45.2, D46.2, D47.2, D48.2, D49.2, D50.2, J9.5, J10.1, J11.1, J11.2, J11.4, J11.7, J11.10, J11.13, J11.16, J11.19, J11.22, J11.25, J11.28, J11.37, J11.38, J11.49, J11.50, J11.61, J11.62, J11.71, J11.72, J11.75, J11.76, Q9.2 (S), Q10.2 (S), R217.1, R218.1, R222.1, R230.1, S2.2, S3.2, U29.3 (GND), U29.8 (GND), U30.3 (GND), U30.8 (GND), U33.2 (GND), U34.6 (Vss); also elsewhere on the board
GPIO00: R100.6; also elsewhere on the board
GPIO01: R26.6; also elsewhere on the board
GPIO07: R26.5; also elsewhere on the board
GPIO09: R53.8; also elsewhere on the board
GPIO10: R53.7; also elsewhere on the board
GPIO11: R100.7; also elsewhere on the board
GPIO12: R100.8; also elsewhere on the board
GPIO13: R64.5; also elsewhere on the board
I2C2_SCL: R121.2, U30.5 (IO4), U30.6 (IO4); also elsewhere on the board
I2C2_SDA: R120.2, U30.4 (IO3), U30.7 (IO3); also elsewhere on the board
I2S0_LRCK: R54.7; also elsewhere on the board
I2S0_SCLK: R100.5; also elsewhere on the board
I2S0_SDIN: R54.8; also elsewhere on the board
I2S0_SDOUT: R101.8; also elsewhere on the board
unnamed: D26.1, R223.1
unnamed: D26.2, Q9.3 (D)
unnamed: D27.1, R231.1
unnamed: D27.2, Q10.3 (D)
unnamed: J11.63, R55.2
unnamed: J11.64, R120.1
unnamed: J11.65, R62.2
unnamed: J11.66, R121.1
unnamed: J11.68, R335.2
unnamed: J11.70, R336.2
unnamed: TP1.1, U34.7 (P4)
unnamed: TP34.1, U34.8 (P5)
unnamed: TP46.1, U34.9 (P6)
unnamed: TP47.1, U34.10 (P7)
PCIE2_CLKREQ*: R26.7; also elsewhere on the board
PCIE2_CLK_N: D43.1, J11.15; also elsewhere on the board
PCIE2_CLK_P: D44.1, J11.17; also elsewhere on the board
PCIE2_RST*: R26.8; also elsewhere on the board
PCIE2_RX0_N: D39.1, J11.12; also elsewhere on the board
PCIE2_RX0_P: D40.1, J11.14; also elsewhere on the board
PCIE2_RX1_N: D45.1, J11.6; also elsewhere on the board
PCIE2_RX1_P: D46.1, J11.8; also elsewhere on the board
PCIE2_TX0_N: C108.1; also elsewhere on the board
PCIE2_TX0_P: C109.1; also elsewhere on the board
PCIE2_TX1_N: C112.1; also elsewhere on the board
PCIE2_TX1_P: C110.1; also elsewhere on the board
PCIE3_CLKREQ*: R64.7; also elsewhere on the board
PCIE3_CLK_N: D49.1, J11.18; also elsewhere on the board
PCIE3_CLK_P: D50.1, J11.20; also elsewhere on the board
PCIE3_RST_CONN*: J11.30, R64.4, R64.8
PCIE_WAKE_SEL_EXT: R64.6; also elsewhere on the board
PDC_MISO: J9.8; also elsewhere on the board
PDC_MOSI: J9.9; also elsewhere on the board
PDC_SCLK: J9.7; also elsewhere on the board
SPI1_MISO: R101.5; also elsewhere on the board
SPI1_MOSI: R101.6; also elsewhere on the board
SPI1_SCK: R101.7; also elsewhere on the board
SPIO_MISO: R63.8; also elsewhere on the board
SPIO_MOSI: R54.5; also elsewhere on the board
SPIO_SCK: R54.6; also elsewhere on the board
SYS_SCL: J9.4, R62.1, R216.1, U30.2 (IO2), U30.9 (IO2); also elsewhere on the board
SYS_SDA: J9.3, R55.1, R215.1, U30.1 (IO1), U30.10 (IO1); also elsewhere on the board
UART1_RXD: R53.5; also elsewhere on the board
UART1_TXD: R53.6; also elsewhere on the board
USBC1_PEN: R25.3; also elsewhere on the board
USBSS1_RX_N: J11.24, U29.1 (IO1), U29.10 (IO1); also elsewhere on the board
USBSS1_RX_P: J11.26, U29.2 (IO2), U29.9 (IO2); also elsewhere on the board
USBSS1_TX_N: C113.1; also elsewhere on the board
USBSS1_TX_P: C111.1; also elsewhere on the board
USER_BTN0: R232.1, S2.1; also elsewhere on the board
USER_BTN1: R242.1, S3.1; also elsewhere on the board
USER_LED0: Q9.1 (G), R222.2; also elsewhere on the board
USER_LED1: Q10.1 (G), R230.2; also elsewhere on the board
~GPIO_INT: R219.1, U34.11 (~INT); also elsewhere on the board
~PDC_CS: J9.6; also elsewhere on the board
~SPI0_CS0: R63.7; also elsewhere on the board
~SPI0_CS1: R63.6; also elsewhere on the board
~SPI1_CS0: R102.8; also elsewhere on the board
~SPI1_CS1: R102.7; also elsewhere on the board

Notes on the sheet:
TAG-CONNECT
Fan connector
Expansion connector
LED indicators
Expansion connector resistors
GPIO expander
Debug connector
LOW POWER ONLY FOR LEVEL SHIFTERS
Buttons

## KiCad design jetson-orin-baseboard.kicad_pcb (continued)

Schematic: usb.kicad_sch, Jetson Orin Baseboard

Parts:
C26, C27, C29, C31, C33, C36, C37, C38, C39, C45, C46, C47, C54, C55, C57, C60, C61, C62, C63: C_100n_0402; 0402-cap; MPN GRM155R61H104KE14D
C28, C30, C34, C35, C56, C59: C_10u_0402; 0402-cap; MPN CC0402MRX5R5BB106
C32: C_10u_25V_0603; 0603-cap; MPN C1608X5R1E106M080AC
C53, C58, C64, C65: C_100n_0402_50V; 0402-cap; MPN GRM155R71H104KE14D
D2, D3, D4, D5, D8, D9: LTST-C190GKT; LED_0603; MPN LTST-C190GKT
D6, D7: DF2S30FS; SOD-923; MPN DF2S30FS
D35: RB521S30T1G; SOD-523; MPN RB521S30T1G
J3: USB4105-GF-A; GCT_USB4105-GF-A; MPN USB4105-GF-A
J4: WE_632723300011_alt_symbol; WE_632723300011; MPN 632723300011
Q1, Q2, Q3: NX138BKMYL; DFN1006-3; MPN NX138BKMYL
R23, R24, R33: 4x0R_0201_array; EXB18V; MPN EXB-18VR000X
R40, R41, R56, R57, R58, R59, R60, R61, R65, R66, R67, R70, R71, R75, R76, R79, R80, R81, R82, R84: R_0R_0402; 0402-res; MPN ERJ2GE0R00X
R42, R44, R46, R47, R49, R74, R77, R83, R99: R_10k_0402; 0402-res; MPN CRCW040210K0FKEDHP
R43, R45, R105, R111: R_100k_0402; 0402-res; MPN CRCW0402100KFKEDHP
R68, R69, R72, R73, R106, R112: R_200R_0603; 0603-res; MPN ERJ-UP3F2000V
R78, R104: R_2k2_0402; 0402-res; MPN RC0402FR-072K2L
R85, R86, R87, R88, R89, R90, R91, R92, R93, R94, R95, R96, R97, R98: R_1k_0402; 0402-res; MPN CR0402-FX-1001GLF
R109, R110: R_2M0_0402; 0402-res; MPN AC0402FR-072ML
TP13, TP14, TP15, TP16, TP17, TP18, TP19, TP20, TP21, TP22, TP23, TP24, TP25, TP26, TP27, TP29: TP_SMD_0_75MM; Testpoint_smd_0_75mm
TP28: TP; TP-R-1.5
U5: FT230XQ-R; WQFN-16-1EP_4x4mm; MPN FT230XQ-R
U6: TPS65988; IC_TPS65987DDHRSHR; MPN TPS65988DHRSHR
U7: W25Q80DVUXIE_TR; USON-8_2x3mm_P0.5mm; MPN W25Q80DVUXIE TR
U8: TPS7B8133DRVR; WSON6_TI_2x2mm; MPN TPS7B8133DRVR
U9, U12: AP22615; TSOT23-6; MPN AP22615AWU-7
U10: TUSB1046-DCI; WQFN-40_1EP_6x3mm_Pitch0.4mm_EP4.7x2.7mm; MPN TUSB1046-DCIRNQT
U11, U13, U14, U15, U16: TPD4E05U06QDQARQ1; USON-10_2.5x1.0mm_P0.5mm; MPN TPD4E05U06QDQARQ1

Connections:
+1V8: Q1.1 (G), R47.2; also elsewhere on the board
+3V3: C26.1, C36.1, C37.1, C54.1, C55.1, C56.1, R49.2, R85.2, R87.2, R89.2, R91.2, R93.2, R95.2, R97.2, R106.2, R112.2, U6.5 (VIN_3V3), U10.1 (VCC), U10.6 (VCC), U10.20 (VCC), U10.28 (VCC); also elsewhere on the board
+5V: C35.1, C45.1, C57.1, C59.1, R74.2, R83.2, U6.25 (PP1_CABLE), U6.46 (PP2_CABLE), U9.6 (IN), U12.6 (IN); also elsewhere on the board
/USB Debug, DP/DRAIN1: U6.7 (DRAIN2), U6.52 (DRAIN2), U6.56 (DRAIN2), U6.57 (DRAIN2)
/USB Debug, DP/DRAIN2: U6.8 (DRAIN1), U6.15 (DRAIN1), U6.19 (DRAIN1), U6.58 (DRAIN1)
/USB Debug, DP/FLASH_CLK: R23.7, U7.6 (SCLK)
/USB Debug, DP/FLASH_MISO: R24.7, R24.8, U7.2 (SO/IO1)
/USB Debug, DP/FLASH_MOSI: R23.8, U7.5 (SI/IO0)
/USB Debug, DP/FTDI_3V3: C27.1, C29.1, C34.1, R46.2, R72.2, R73.2, U5.1 (VCCIO), U5.8 (3V3OUT), U5.10 (VCC), U8.6 (OUT)
/USB Debug, DP/FTDI_CBUS0: TP15.1, U5.12 (CBUS0)
/USB Debug, DP/FTDI_CBUS3: TP16.1, U5.14 (CBUS3)
/USB Debug, DP/FTDI_LED_RX: D3.2, U5.11 (CBUS1)
/USB Debug, DP/FTDI_LED_TX: D2.2, U5.5 (CBUS2)
/USB Debug, DP/HPDIN: R75.2, U10.32 (HPDIN/RSVD2)
/USB Debug, DP/LDO_3V3: D35.2
/USB Debug, DP/PDC_ADCIN1: R42.1, R43.2, U6.6 (ADCIN1)
/USB Debug, DP/PDC_ADCIN2: R44.1, R45.2, U6.10 (ADCIN2)
/USB Debug, DP/PDC_CTL0: R33.4, U6.18 (GPIO2)
/USB Debug, DP/PDC_CTL1: R33.2, U6.16 (GPIO0)
/USB Debug, DP/PDC_FLIP: R33.3, U6.17 (GPIO1)
/USB Debug, DP/PDC_GPIO14: R68.2, U6.42 (GPIO14/PWM1)
/USB Debug, DP/PDC_GPIO15: R69.2, U6.43 (GPIO15/PWM2)
/USB Debug, DP/PDC_HPD1: R65.2, U6.30 (GPIO3/HPD1)
/USB Debug, DP/PDC_I2C1_IRQn: TP17.1, U6.29 (~I2C1_IRQ)
/USB Debug, DP/PDC_I2C1_SCL: R70.2, U6.27 (I2C1_SCL)
/USB Debug, DP/PDC_I2C1_SDA: R71.2, U6.28 (I2C1_SDA)
/USB Debug, DP/PDC_I2C2_IRQn: TP18.1, U6.34 (~I2C2_IRQ)
/USB Debug, DP/PDC_I2C2_SCL: TP19.1, U6.32 (I2C2_SCL)
/USB Debug, DP/PDC_I2C2_SDA: TP20.1, U6.33 (I2C2_SDA)
/USB Debug, DP/PDC_I2C3_SCL: R66.2, U6.21 (I2C3_SCL/GPIO5)
/USB Debug, DP/PDC_I2C3_SDA: R67.2, U6.22 (I2C3_SDA/GPIO6)
/USB Debug, DP/PDC_LDO_1V8: C28.1, U6.35 (LDO_1V8)
/USB Debug, DP/PDC_LDO_3V3: C30.1, R42.2, R44.2, U6.9 (LDO_3V3)
/USB Debug, DP/PDC_RESET: R41.2, U6.44 (HRESET)
/USB Debug, DP/USBC0_5V_PEN: R84.1, U6.49 (GPIO17/PP_EXT2)
/USB Debug, DP/USBC0_CC1: J4.A5 (CC1), U6.45 (C2_CC1), U16.5 (IO4), U16.6 (IO4)
/USB Debug, DP/USBC0_CC2: J4.B5 (CC2), U6.47 (C2_CC2), U16.4 (IO3), U16.7 (IO3)
/USB Debug, DP/USBC0_CONN_TX1_N: C60.2, J4.A3 (TX1-), U15.5 (IO4), U15.6 (IO4)
/USB Debug, DP/USBC0_CONN_TX1_P: C62.2, J4.A2 (TX1+), U15.4 (IO3), U15.7 (IO3)
/USB Debug, DP/USBC0_CONN_TX2_N: C61.2, J4.B2 (TX2+), U14.4 (IO3), U14.7 (IO3)
/USB Debug, DP/USBC0_CONN_TX2_P: C63.2, J4.B3 (TX2-), U14.5 (IO4), U14.6 (IO4)
/USB Debug, DP/USBC0_CTL0: R33.6, R82.1, U10.22 (CTL0/SDA)
/USB Debug, DP/USBC0_CTL1: R33.5, U10.23 (CTL1/HPDIN)
/USB Debug, DP/USBC0_DPEQ0: R91.1, R92.1, U10.14 (DPEQ0/A1)
/USB Debug, DP/USBC0_DPEQ1: R93.1, R94.1, U10.2 (DPEQ1)
/USB Debug, DP/USBC0_EQ0: R95.1, R96.1, U10.38 (EQ0)
/USB Debug, DP/USBC0_EQ1: R97.1, R98.1, U10.35 (EQ1)
/USB Debug, DP/USBC0_FLG: R83.1, TP29.1, U12.3 (FLG)
/USB Debug, DP/USBC0_FLIP: R33.7, R79.1, U10.21 (FLIP/SCL)
/USB Debug, DP/USBC0_I2C_EN: R85.1, R86.1, U10.17 (I2C_EN)
/USB Debug, DP/USBC0_RX1_N: J4.B11 (RX1+), U10.31 (RX1_N), U15.2 (IO2), U15.9 (IO2)
/USB Debug, DP/USBC0_RX1_P: J4.B10 (RX1-), U10.30 (RX1_P), U15.1 (IO1), U15.10 (IO1)
/USB Debug, DP/USBC0_RX2_N: J4.A10 (RX2-), U10.39 (RX2_N), U14.1 (IO1), U14.10 (IO1)
/USB Debug, DP/USBC0_RX2_P: J4.A11 (RX2+), U10.40 (RX2_P), U14.2 (IO2), U14.9 (IO2)
/USB Debug, DP/USBC0_SBU1: J4.A8 (SBU1), R109.2, U10.27 (SBU1), U13.2 (IO2), U13.9 (IO2)
/USB Debug, DP/USBC0_SBU2: J4.B8 (SBU2), R110.2, U10.26 (SBU2), U13.1 (IO1), U13.10 (IO1)
/USB Debug, DP/USBC0_SSEQ0: R87.1, R88.1, U10.11 (SSEQ0/A0)
/USB Debug, DP/USBC0_SSEQ1: R89.1, R90.1, U10.3 (SSEQ1)
/USB Debug, DP/USBC0_TX1_N: C60.1, U10.34 (TX1_N)
/USB Debug, DP/USBC0_TX1_P: C62.1, U10.33 (TX1_P)
/USB Debug, DP/USBC0_TX2_N: C61.1, U10.36 (TX2_N)
/USB Debug, DP/USBC0_TX2_P: C63.1, U10.37 (TX2_P)
/USB Debug, DP/USBC0_VBUS: C65.1, D7.1, J4.A4 (VBUS), J4.A9 (VBUS), J4.B4 (VBUS), J4.B9 (VBUS), Q3.1 (G), R111.2, U6.3 (VBUS2), U12.1 (OUT)
/USB Debug, DP/USBC3_5V_PEN: R76.1, U6.48 (GPIO16/PP_EXT1)
/USB Debug, DP/USBC3_CC1: J3.A5 (CC1), U6.24 (C1_CC1), U11.5 (IO4), U11.6 (IO4)
/USB Debug, DP/USBC3_CC2: J3.B5 (CC2), U6.26 (C1_CC2), U11.4 (IO3), U11.7 (IO3)
/USB Debug, DP/USBC3_FLG: R74.1, TP27.1, U9.3 (FLG)
/USB Debug, DP/USBC3_VBUS: C32.1, C64.1, D6.1, J3.A4 (VBUS), J3.A9 (VBUS), J3.B4 (VBUS), J3.B9 (VBUS), Q2.1 (G), R105.2, U6.13 (VBUS1), U8.1 (IN), U8.2 (EN), U9.1 (OUT)
/USB Debug, DP/USBC_HPD1: Q1.3 (D), R49.1, R65.1, R75.1
/USB Debug, DP/USBPD_SCL: R61.1, R66.1, R70.1, R79.2
/USB Debug, DP/USBPD_SDA: R60.1, R67.1, R71.1, R82.2
/USB Debug, DP/USBSS0_RX_C_N: C38.2, U10.4 (SSRX_N)
/USB Debug, DP/USBSS0_RX_C_P: C46.2, U10.5 (SSRX_P)
/USB Debug, DP/USBSS0_TX_C_N: C39.2, U10.7 (SSTX_N)
/USB Debug, DP/USBSS0_TX_C_P: C47.2, U10.8 (SSTX_P)
/USB Debug, DP/USB_FTDI_N: R80.2, U5.7 (USBDM)
/USB Debug, DP/USB_FTDI_P: R81.2, U5.6 (USBDP)
/USB Debug, DP/~PFLASH_CS: R24.5, U7.1 (~CS)
/USB Debug, DP/~PFLASH_HOLD: R23.6, U7.7 (~HOLD/IO3)
/USB Debug, DP/~PFLASH_WP: R24.6, U7.3 (~WP/IO2)
DEBUG_RXD: R56.1; also elsewhere on the board
DEBUG_TXD: R57.1; also elsewhere on the board
DP1_AUX_N: U10.25 (AUX_N); also elsewhere on the board
DP1_AUX_P: U10.24 (AUX_P); also elsewhere on the board
DP1_HPD: R40.1; also elsewhere on the board
DP1_TXD0_N: U10.10 (DP0_N); also elsewhere on the board
DP1_TXD0_P: U10.9 (DP0_P); also elsewhere on the board
DP1_TXD1_N: U10.13 (DP1_N); also elsewhere on the board
DP1_TXD1_P: U10.12 (DP1_P); also elsewhere on the board
DP1_TXD2_N: U10.16 (DP2_N); also elsewhere on the board
DP1_TXD2_P: U10.15 (DP2_P); also elsewhere on the board
DP1_TXD3_N: U10.19 (DP3_N); also elsewhere on the board
DP1_TXD3_P: U10.18 (DP3_P); also elsewhere on the board
EEPROM_PWR: C33.1, D35.1, R23.3, R24.1, R24.3, TP21.1, U7.8 (VCC); also elsewhere on the board
GND: C26.2, C27.2, C28.2, C29.2, C30.2, C31.2, C32.2, C33.2, C34.2, C35.2, C36.2, C37.2, C45.2, C53.2, C54.2, C55.2, C56.2, C57.2, C58.2, C59.2, C64.2, C65.2, D4.2, D5.2, D6.2, D7.2, J3.A1 (GND), J3.A12 (GND), J3.B1 (GND), J3.B12 (GND), J3.S1 (SHIELD), J4.A1 (GND), J4.A12 (GND), J4.B1 (GND), J4.B12 (GND), J4.Shell (SHIELD), Q2.2 (S), Q3.2 (S), R41.1, R43.1, R45.1, R77.1, R78.1, R86.2, R88.2, R90.2, R92.2, R94.2, R96.2, R98.2, R99.1, R104.1, R105.1, R109.1, R110.1, R111.1, TP26.1, U5.3 (GND), U5.13 (GND), U5.17 (GND), U6.20 (GND), U6.51 (GND), U6.59 (GND_EP), U7.4 (VSS), U8.3 (GND), U8.4 (GND), U8.7 (GND), U9.2 (GND), U10.41 (EP_GND), U11.3 (GND), U11.8 (GND), U12.2 (GND), U13.3 (GND), U13.8 (GND), U14.3 (GND), U14.8 (GND), U15.3 (GND), U15.8 (GND), U16.3 (GND), U16.8 (GND); also elsewhere on the board
unnamed: C31.1, R46.1, U5.9 (~RESET)
unnamed: D2.1, R72.1
unnamed: D3.1, R73.1
unnamed: D4.1, R68.1
unnamed: D5.1, R69.1
unnamed: D8.1, R106.1
unnamed: D8.2, Q2.3 (D)
unnamed: D9.1, R112.1
unnamed: D9.2, Q3.3 (D)
unnamed: Q1.2 (S), R40.2, R47.1
unnamed: R56.2, U5.15 (TXD)
unnamed: R57.2, U5.2 (RXD)
unnamed: R58.2, U5.16 (~RTS)
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

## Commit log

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2022-09-30 SCH: Add Orin NX power supply & management unit
    [jetson-orin-nx-baseboard.kicad_sch, supply.kicad_sch, usb.kicad_sch]
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2022-09-30 SCH: Change subschematic page sizes to A3, move Antmicro & OSHW logos
    [csi.kicad_sch, ethernet.kicad_sch, interfaces.kicad_sch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]
2022-09-30 SCH-USB: Update FT4233HPQ symbol, fix labels
    Symbol was updated in global library to fix MPN, swapped pins and other issues
    [usb.kicad_sch]
2022-09-30 SCH: Move Jetson Orin NX socket connections to dedicated subschematic & make it A2
    [jetson-orin-nx-baseboard.kicad_sch, som.kicad_sch, supply.kicad_sch]
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2022-09-30 Fix PD1_VCONN label name
    [usb.kicad_sch]
2022-09-30 SCH-SoM: Fix symbol text field placement
    These are defined correctly in symbol from library, but the text
    positions get lost when placing them using "Add component" (A hotkey).
    I selected all the SoM Units & updated their symbols from library, which
    fixes the issue (also moved fields around for X-mirrored Units)
    [som.kicad_sch]
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2022-09-30 Add USB2.0 HUB, place passives to USB, add mockup connections to SOM and USB
    [interfaces.kicad_sch, jetson-orin-nx-baseboard.kicad_sch, m-2.kicad_sch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]
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2022-09-30 Add missing PD interface connections
    [ftdi.kicad_sch, jetson-orin-nx-baseboard.kicad_sch, usb.kicad_sch]
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2022-09-30 Wire up M.2 with SoM + PCIE_WAKE selector, fix global labels
    [jetson-orin-nx-baseboard.kicad_sch, m-2.kicad_sch, som.kicad_sch]
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2022-09-30 MANUAL MERGE & SCH: Add RJ45 and PoE circuitry to Ethernet subsheet & respective global labels to SoM subsheet
    Had to make a manual merge on jetson-orin-nx-baseboard.kicad_sch using Meld, included all new UUIDs, triple checked whether:
    - All UUIDs from remote and local are included
    - All S-Expressions are closed/have matching parentheses
    Checked and the SCH files open correctly in KiCad, no missing elements spotted.
    [ethernet.kicad_sch, jetson-orin-nx-baseboard.kicad_sch, som.kicad_sch]
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2022-09-30 Cleaned up schematics, added debug connector, user LEDs and buttons. Connected misc. signals
    [csi.kicad_sch, jetson-orin-nx-baseboard.kicad_sch, peripherals.kicad_sch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]
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2022-09-30 Add labels to majority of the wires and fix minor errors in usb.kicad_sch
    [usb.kicad_sch]
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2022-09-30 Fixed FTDI LED power supply
    [jetson-orin-nx-baseboard.kicad_sch, peripherals.kicad_sch, usb.kicad_sch]
2022-09-30 Finished designing toggle button power-up, sequencing and reset circuitry with auto startup option
    [jetson-orin-nx-baseboard.kicad_sch, som.kicad_sch, supply.kicad_sch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]
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2022-09-30 Fix page numbers
    [jetson-orin-nx-baseboard.kicad_sch]
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2022-09-30 Fix connections and component positions after AP22615 symbol update
    [jetson-orin-nx-baseboard.kicad_sch, peripherals.kicad_sch]
2022-09-30 Fix inter-sheet references positions in ethernet subsheet
    [ethernet.kicad_sch]
2022-09-30 Fix inter-sheet references' positions in M.2 sub-sheet
    [m-2.kicad_sch]
2022-09-30 Fix inter-sheet references positions in csi subsheet
    [csi.kicad_sch]
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2022-09-30 M.2 SCH: Add PCIe 0 Root Port / Endpoint mode switching circuitry
    [jetson-orin-nx-baseboard.kicad_sch, m-2.kicad_sch]
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2022-09-30 M.2 SCH: Set PCIe 0 default role as Root Port by marking 3V3_EP resistor as DNP
    [m-2.kicad_sch]
2022-09-30 M.2 SCH: Add missing internal labels for PCIe 0 control signals
    [m-2.kicad_sch]
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2022-09-30 Connected SoM's control signals, fixed components without footprints
    [csi.kicad_sch, jetson-orin-baseboard.kicad_sch, peripherals.kicad_sch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]
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2022-09-30 Fix mixed U302, U301 connections
    [m-2.kicad_sch]
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2022-09-30 Minor improvements in supply subsheet
    Add pullups and testpoints to 5V and 3V3 PG signals
    Add labales to VCC outputs of the 5V and 3V3 DCDC
    Rearrange items in schematic
    [jetson-orin-baseboard.kicad_sch, supply.kicad_sch]
2022-09-30 Replace SoM VDD_IN caps with 25V rated ones
    [jetson-orin-baseboard.kicad_sch, som.kicad_sch]
2022-09-30 Replace 22u_25V_0805 caps in supply with ones from cap_misc library
    [jetson-orin-baseboard.kicad_sch, supply.kicad_sch]
2022-09-30 Cleaned up the schematic, fixed library issues, annotated schematic
    [csi.kicad_sch, ethernet.kicad_sch, jetson-orin-baseboard.kicad_sch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]
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2022-09-30 Unified schematic look of ethernet sheet, improved shielding of eth connector, replaced gnd symbols
    [csi.kicad_sch, ethernet.kicad_sch, jetson-orin-baseboard.kicad_sch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]
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2022-09-30 Add CSI MUX labels and numbers to refer to on Block Diagram, update all GND symbols from global library
    [csi.kicad_sch, ethernet.kicad_sch, jetson-orin-baseboard.kicad_sch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]
2022-09-30 M.2 SCH: Rewire PCIe Root Port / Endpoint mode switching circuitry w/ updated symbol
    [jetson-orin-baseboard.kicad_sch, m-2.kicad_sch]
2022-09-30 M.2 SCH: Rearrange schematic for uniformity and readabilty
    Rearrange sub-schematic to follow the general schematic style:
    - Divide subsections of the subschematic with dashed lines
    - Alter subsection title font size to 4mm to fit rest of the schematic
    [m-2.kicad_sch]
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2022-09-30 Wire CLK_32K_OUT to all M.2 connectors thru 0Rs, Reannotate and fix typo on M.2 sub-schematic
    [jetson-orin-baseboard.kicad_sch, m-2.kicad_sch, som.kicad_sch]
2022-09-30 Update net labels in M.2 and USB subsheets
    Minor tweaks in placement of the component values
    Fix M.2 net labels betweeen capacitors and connectors
    [m-2.kicad_sch, usb.kicad_sch]
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2022-09-30 Remove USB connector, remove one M.2 key M, remove 40pin connector
    Major changes to the design:
    - remove the USB 2.0 mux
    - remove one USB-C connectors
    - connect USB2-2 directly to the M.2 key E
    - remove one M.2 key M connectors
    - remove 40pin 2.54mm connector
    [jetson-orin-baseboard.kicad_sch, m-2.kicad_sch, peripherals.kicad_sch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]
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2022-09-30 Fix HDMI sheet name typo, GND symbols autoannotated
    [csi.kicad_sch, ethernet.kicad_sch, jetson-orin-baseboard.kicad_sch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]
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2022-09-30 SoM SCH: Fix misspelling and improve aesthetics
    [som.kicad_sch]
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2022-09-30 Import changes to PCB, place part of components inside PCB, temporarily remove part of components on PCB
    [jetson-orin-baseboard.kicad_pcb]
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2022-09-30 Reset grid and drill origins
    [jetson-orin-baseboard.kicad_pcb]
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2022-10-03 Fix UART2 connected to expansion connector, add I2S, UART to M.2
    [m-2.kicad_sch, peripherals.kicad_sch, som.kicad_sch]
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2022-10-04 Replace HPD voltage converter with parts from global library
    [hdmi.kicad_sch]
2022-10-04 Fix TPD4E05U06QDQARQ1 footprint link, annotate parts
    [jetson-orin-baseboard.kicad_sch, m-2.kicad_sch, peripherals.kicad_sch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]
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2022-10-04 Unify reference designator and value text size, minor improvements on som subsheet
    [csi.kicad_sch, ethernet.kicad_sch, hdmi.kicad_sch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]
2022-10-04 Supply SCH: Correct POWER_EN global label direction
    [supply.kicad_sch]
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2022-10-05 Add 32.7kHz oscillator to M2 key M
    [jetson-orin-baseboard.kicad_sch, m-2.kicad_sch]
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2022-10-05 Unused M.2 pins as test-point, M2 key E I2C and UART wake resistors set to DNP
    [jetson-orin-baseboard.kicad_sch, m-2.kicad_sch]
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2022-10-05 Add 3V3 rail discharge
    - add 3V3 rail discharge circuitry
    - add 3V3 and 5V0 switch side labels
    - minor improvements in arrangement on the supply sheet
    - minor update on m-2 sheet
    [jetson-orin-baseboard.kicad_sch, m-2.kicad_sch, supply.kicad_sch]
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2022-10-06 Add option to source M.2 key M SUSCLK from SoM 32kHz clock
    [jetson-orin-baseboard.kicad_sch, m-2.kicad_sch]
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2022-10-06 Cleanup in CSI sheet
    - improve CSI multiplexers and I2C mux symbols
    - add table describing selected channel depending on S pin state
    - minor improvement in readability in power switch area
    - add test points to I2C mux outputs
    [csi.kicad_sch]
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2022-10-07 Fixed voltage on fan connector
    [csi.kicad_sch, hdmi.kicad_sch, jetson-orin-baseboard.kicad_sch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]
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2022-10-07 Aligned the order of the sheets with the order of the pages
    [jetson-orin-baseboard.kicad_sch]
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2022-10-10 Replace CSI muxes with R0s. annotate parts
    [csi.kicad_sch, jetson-orin-baseboard.kicad_sch, peripherals.kicad_sch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]
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2022-10-12 Remove R0s from high speed signals, replace part of R0s with resistor ladder. Assign net clases
    [csi.kicad_sch, jetson-orin-baseboard.kicad_pcb, jetson-orin-baseboard.kicad_sch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]
2022-10-13 Replace I2C pullups with 2.2kOhm array
    [csi.kicad_sch, jetson-orin-baseboard.kicad_sch]
2022-10-13 Replace part of 0R resistors with resistor arrays
    [csi.kicad_sch, jetson-orin-baseboard.kicad_sch, m-2.kicad_sch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]
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2022-10-13 Rearanged PCB to move M.2 connector and changed exp conn resistors to res arrays
    [csi.kicad_sch, jetson-orin-baseboard.kicad_pcb, jetson-orin-baseboard.kicad_sch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]
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2022-10-28 Routed power-up and reset circuitry
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2022-11-15 Fixed DRC errors, fixed swapped SDA/SCL
    [csi.kicad_sch, jetson-orin-baseboard.kicad_sch, som.kicad_sch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]
2022-11-17 Fixed swapped CSI signals
    [csi.kicad_sch, usb.kicad_sch]
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2022-11-17 Fixed bit order on CSI B connector
    [csi.kicad_sch]
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2022-11-17 Fixed M.2 holes
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2022-11-21 Minor silkscreen/via/clearance cleanup
    [jetson-orin-baseboard.kicad_sch, supply.kicad_sch]
2022-11-24 Fixed copper-hole clerance and fixed all the violations
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2022-11-24 M.2 SCH: Remove obsolete note about PCIe0 Root Port / Endpoint switching
    [m-2.kicad_sch]
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2022-11-28 Replace Key E PCIe capacitors with 220n ones
    [jetson-orin-baseboard.kicad_sch, m-2.kicad_sch]
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2022-11-29 Fix symbols after loclib
    [csi.kicad_sch, ethernet.kicad_sch, hdmi.kicad_sch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]
2022-11-29 Replace TPS7B8133DRVR with NCP730BMT330TBG, adjust schematics and layout
    [jetson-orin-baseboard.kicad_sch, supply.kicad_sch, usb.kicad_sch]
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2022-12-09 Fixed 3d models after loclib
    [ethernet.kicad_sch, som.kicad_sch]
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2022-12-15 Fixed wrong gnd net name
    [ethernet.kicad_sch, som.kicad_sch, supply.kicad_sch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]
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2023-01-09 Redesigned power supply section for 5V modules [#40386]
    [jetson-orin-baseboard.kicad_sch, som.kicad_sch, supply.kicad_sch]
2023-01-09 Replaced 22uF 4V capacitor with 10uF 6.3V [#40387]
    [jetson-orin-baseboard.kicad_sch, supply.kicad_sch]
2023-01-09 Swapped order of USB 2.0 lanes [#40389]
    [m-2.kicad_sch, peripherals.kicad_sch, usb.kicad_sch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]
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2023-01-10 Replaced NX138BKMYL with PJE138K transistor [#40527]
    [hdmi.kicad_sch, jetson-orin-baseboard.kicad_sch, peripherals.kicad_sch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]
2023-01-10 Fixed PoE enable signalling [#40391]
    [ethernet.kicad_sch, jetson-orin-baseboard.kicad_sch]
2023-01-10 Fixed EXV18V footprint [#40394]
2023-01-10 Replaced PCA9547 with PI4MSD5V9548AZDEX to support 1.8V I2C voltages for cameras [#40392]
    [csi.kicad_sch, ethernet.kicad_sch, hdmi.kicad_sch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]
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2023-01-11 Fixed I2C label swap [#40595]
    [som.kicad_sch, usb.kicad_sch]
2023-01-16 Fixed PCIe capacitor values [#40734]
    [jetson-orin-baseboard.kicad_sch, m-2.kicad_sch]
2023-01-16 Fixed swapped lines on M.2 key E connector [#40779]
    [jetson-orin-baseboard.kicad_sch, m-2.kicad_sch]
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2023-02-02 Replace USB SS SOM-MUX capacitors with ORs
    [jetson-orin-baseboard.kicad_sch, usb.kicad_sch, usb3.kicad_sch]
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2023-02-08 Remove rule resulting in KiCad crashing when dragging via
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2023-02-09 Replace buttons with top-actuated ones
    [peripherals.kicad_sch, som.kicad_sch, supply.kicad_sch]
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2023-02-09 Replace buttons on PCB. Update VBUS led circuitry. Improve power planes
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2023-02-14 Replace HDMI connector with mini HDMI one
    [hdmi.kicad_sch, jetson-orin-baseboard.kicad_sch]
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2023-02-16 Add missing DP AUX pullup/down resistors
    [jetson-orin-baseboard.kicad_sch, usb.kicad_sch]
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2023-02-17 Connect USB-C HPD to correct pin
    [usb.kicad_sch]
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2023-02-17 Place tag connect on the PCB. Update layout after recent schematic changes
    [jetson-orin-baseboard.kicad_sch, peripherals.kicad_sch]
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2023-02-28 Fix SDA/SCL cross
    [hdmi.kicad_sch]
2023-02-28 Replace 1u/10V cap with 1u/25V one
    [supply.kicad_sch]
2023-02-28 Add capacitors to USB SS. Add VBUS, _HV 1u/4u7 caps. Improve readability
    [usb.kicad_sch]
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2023-03-01 Fix mixed labels on resistor arrays
    [peripherals.kicad_sch]
2023-03-01 Add resistor to slow down discharge of U37 2A input. Add TVS to S4 and S5
    [jetson-orin-baseboard.kicad_sch, supply.kicad_sch]
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2023-03-01 Update TPS56C230 symbol. Add more capacitors to the 5V and 3.3V DCDCs
    [jetson-orin-baseboard.kicad_sch, supply.kicad_sch]
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2023-03-02 Update PoE DCDC trimming resistors. Add 0R to bypass transistor on POE_ACTIVE
    [ethernet.kicad_sch, jetson-orin-baseboard.kicad_sch]
2023-03-02 Simplify U6 I2C connection. Adjust pinout on R80/R81 remove flash R0 arrays
    [usb.kicad_sch]
2023-03-02 Flip connections on R26 and R63 for easier routing
    [peripherals.kicad_sch]
2023-03-02 Flip connections on U31 for easier routing
    [csi.kicad_sch]
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2023-03-02 Import changes to PCB. Resolve DRC errors
    [jetson-orin-baseboard.kicad_sch]
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2023-03-06 Set R199 and R229 as DNP. U23 has builtin pullup on CTRL pin
    [ethernet.kicad_sch]
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2023-10-20 Fixed HDMI 3d model offset
    [hdmi.kicad_sch, jetson-orin-baseboard.kicad_sch]
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2024-01-03 43563 fix incorrect dnp fields
    [m-2.kicad_sch, peripherals.kicad_sch, som.kicad_sch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]
2024-01-05 [#53466] pcb: swap CSIA_5V and CSIA_3V3 LEDs labels
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2024-03-26 [#56923] Fix OHP issue
    [usb.kicad_sch]
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2024-06-05 [#60168] Fix silkscreen warnings
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2024-06-14 [#60110] Fixed HS routing. Fixed silkscreen
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2024-08-16 [#61587] Fix length matching. Bump revision to 1.1.7
    [csi.kicad_sch, ethernet.kicad_sch, hdmi.kicad_sch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]
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2024-08-16 [#61587] Modify custom rule clearance to increase copper to hole clearance on GND to 0.25mm
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2024-08-16 [#61587] Correct R42 value back to 10k
    [usb.kicad_sch]
2024-08-16 [#61587] Correct malformed DNP properties
    [csi.kicad_sch, ethernet.kicad_sch, hdmi.kicad_sch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]
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2024-09-03 [#64267] Replace 3V3 converter with the new one
    [supply.kicad_sch]
2024-09-03 [#64267] Replace 5V converter with the new one
    [supply.kicad_sch]
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2024-09-03 [#64267] Swap 5V and 3V3 converter placement
    [supply.kicad_sch]
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2024-09-03 [#64267] Replace the coil for the 5V converter
    [supply.kicad_sch]
2024-09-03 [#64267] Replace the coil for the 3V3 converter, layout power paths
    [supply.kicad_sch]
2024-09-03 [#64267] Repair broken signals, add custom rule for switching node
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2024-09-03 [#64602] Add resistor divider for UVLO for 5V converter, repair last broken tracks, adjust silkscreen
    [supply.kicad_sch]
2024-09-03 [#64602] Fix some tracks and silkscreen
2024-10-07 [#64602] Update component footprints from library, increase clearance between GND and 3V3 switching node, clear DRC
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2024-10-07 [#64336] Update footprints from library, fix DRC
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2024-10-07 [#64336] Swap SPI and I2C information on silkscreen
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2024-10-07 [#64928] Implement fixes after schematic review
    [supply.kicad_sch, usb.kicad_sch]
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2024-10-07 [#64928] Correct names of fiducials on PCB, add not in schematic property to all of them
2024-10-07 [#64928] Correct date on textfield on PCB
2024-10-07 [#64928] Organize area around J9, add more testpoints on power supplies, move them to one place
    [usb.kicad_sch, usb3.kicad_sch]
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2024-10-07 Reverted PD bootstrap change. Updated footprints and cleaned DRC
    [peripherals.kicad_sch, supply.kicad_sch, usb.kicad_sch]
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2024-10-07 [#64928] Add DNP 10M pulldown to Q20, fix note, Replace U29 with NTS0102GT
    [usb.kicad_sch]
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2024-10-14 [#67155] Add pin driven errors to exclusions
2024-10-14 [#67155] Fix off grid ERCs
    [csi.kicad_sch, ethernet.kicad_sch, hdmi.kicad_sch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]
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2024-10-15 [#67339] Add custom rule for hole to track clearance
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2024-10-18 [#67339] Fix USBC1_CONN_TX2 traces
    [csi.kicad_sch, ethernet.kicad_sch, hdmi.kicad_sch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]
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2024-11-22 [#69189] Fix swapped designators, bump revision to 1.2.2
    [csi.kicad_sch, ethernet.kicad_sch, hdmi.kicad_sch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]
2024-11-22 [#69189] Fix ERC
    [ethernet.kicad_sch, usb.kicad_sch]
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2025-01-15 [#71466] Fix silkscreen and GbE length matching
2025-01-15 [#71466] Clear ERC and DRC, improve power traces, mark slew rate control capacitors in ideal diodes as DNP
    [hdmi.kicad_sch, supply.kicad_sch]
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2025-01-21 [#71466] Fix date on the PCB and GbE spacing
2025-01-21 [#71466] WIP: Fix ideal diodes
    [supply.kicad_sch]
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2025-02-12 [#72863] Fixed HPM LED supply voltage
    [supply.kicad_sch]
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2025-02-17 [#73151] Replace buttons at schematic
    [csi.kicad_sch, ethernet.kicad_sch, hdmi.kicad_sch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]
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2025-02-17 [#73151] Increase clearance around buttons
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

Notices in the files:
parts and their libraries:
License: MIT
